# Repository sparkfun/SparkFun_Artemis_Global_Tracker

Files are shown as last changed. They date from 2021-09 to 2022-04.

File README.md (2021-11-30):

SparkFun Artemis Global Tracker
===============================

SparkFun Artemis Global Tracker (https://www.sparkfun.com/products/18712)

[*SparkFun Artemis Global Tracker (WRL-18712)*](https://www.sparkfun.com/products/18712)

The SparkFun Artemis Global Tracker combines the SparkFun Artemis processor with an Iridium 9603N satellite transceiver, ZOE-M8Q GNSS transceiver, and MS8607 PHT sensor to create a truly global tracking and data gathering device in a small form-factor. With a clear view of the sky, this board allows you to send and receive short data messages from anywhere in the world including remote locations like the polar regions, far beyond the reach of WiFi and GSM networks.

Repository Contents
-------------------

* **/Documentation** - Datasheets, FAQs, Hardware Overview, and Message Format for the full Global Tracker Example
* **/Hardware** - Eagle PCB, SCH and LBR design files
* **/Software** - Arduino examples
* **/Tools** - Tools to help: configure the full GlobalTracker example via USB or remotely via Iridium messaging; and track and map its position
* **/binaries** - binary files for the examples which you can upload using the [Artemis Firmware Upload GUI](https://github.com/sparkfun/Artemis-Firmware-Upload-GUI) instead of the Arduino IDE
* **/img** - Folder hosting for images used in the repository
* **LICENSE.md** contains the licence information

Documentation
-------------

* **[Hookup Guide](https://learn.sparkfun.com/tutorials/artemis-global-tracker-hookup-guide)** - Hookup Guide for the SparkFun Artemis Global Tracker.
* **[Artemis Development with Arduino](https://learn.sparkfun.com/tutorials/artemis-development-with-the-arduino-ide)** - An in-depth guide on developing in the Arduino IDE for the Artemis module and any Artemis microcontroller development board.
* **[SparkFun Apollo3 Arduino Core](https://github.com/sparkfun/Arduino_Apollo3)** - GitHub Repository for the SparkFun Apollo3 Arduino core.
* **[Installing an Arduino Library Guide](https://learn.sparkfun.com/tutorials/installing-an-arduino-library)** - Basic information on how to install an Arduino library.
* **[SparkFun IridiumSBD I<sup>2</sup>C Arduino Library](https://github.com/sparkfun/SparkFun_IridiumSBD_I2C_Arduino_Library)** - An Arduino library to support Short Burst Data communication using the Iridium 9602 and 9603N over both Serial and I2C.
* **[SparkFun u-blox GNSS Arduino Library](https://github.com/sparkfun/SparkFun_u-blox_GNSS_Arduino_Library)** - An Arduino library which allows you to communicate seamlessly with the full range of u-blox GNSS modules.
* **[SparkFun MS8607 Arduino Library](https://github.com/sparkfun/SparkFun_PHT_MS8607_Arduino_Library)** - An Arduino library for the TE MS8607 combined Pressure, Humidity and Temperature sensor.

Version History
---------------

* [SPX-16469](https://www.sparkfun.com/products/16469) - Initial SparkX Release
* [WRL-18712](https://www.sparkfun.com/products/18712) - Initial SparkFun Release

License Information
-------------------

This product is _**open source**_!

Please review the LICENSE.md file for license information.

If you have any questions or concerns on licensing, please contact technical support on our [SparkFun forums](https://forum.sparkfun.com/viewforum.php?f=123).

Distributed as-is; no warranty is given.

- Your friends at SparkFun.

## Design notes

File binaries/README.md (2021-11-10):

# Artemis Global Tracker: Binaries

This folder contains the binary files for some of the AGT examples.

You can upload these to the AGT using the [Artemis Firmware Upload GUI](https://github.com/sparkfun/Artemis-Firmware-Upload-GUI) instead of the Arduino IDE.
Which is handy if you want to quickly update the firmware in the field, or are not familiar with the IDE.

To use:

* Download and extract the [AGT repo ZIP](https://github.com/sparkfun/Artemis_Global_Tracker/archive/main.zip)
* Download and extract the [AFU repo ZIP](https://github.com/sparkfun/Artemis-Firmware-Upload-GUI/archive/master.zip)
* Run the AFU artemis_firmware_uploader_gui executable for your platform
  * **/Windows** contains the Windows .exe
  * **/OSX** contains an executable for macOS X
  * **/Linux** contains an executable built on Ubuntu
  * **/Raspberry_Pi__Debian** contains an executable for Raspberry Pi 4 (Debian Buster)
* Select the AGT firmware file you'd like to upload (should end in *.bin*)
  * **Example1 - Blink** powers up the tracker and blinks the white LED (connected to D19).
  * **Example14 - Simple Tracker** is a simple tracker which: wakes up every INTERVAL minutes; gets a GNSS fix; reads the PHT sensor; and sends all the data in a SBD message.
  * **Example15 - Better Tracker** is a better tracker where the INTERVAL, RBDESTINATION and RBSOURCE are stored in 'EEPROM' (Flash) and can be configured via Iridium SBD messages.
  * **Example16 - Global Tracker** is the full Global Tracker. All of the settings can be configured via USB-C or remotely via an Iridium SBD message using the [Artemis Global Tracker Configuration Tool (AGTCT)](../Tools).
  * **Example19 - Serial Terminal** allows the AGT to be operated via a simple Serial Terminal interface. Open the Serial Monitor or a Terminal Emulator at 115200 baud to see the menu.
* Attach the AGT target board using USB
* Select the COM port (hit Refresh to refresh the list of USB devices)
* Press Upload

The GUI does take a few seconds to load and run. _**Don't Panic**_ if the GUI does not start right away.

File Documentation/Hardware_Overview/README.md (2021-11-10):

# Artemis Global Tracker: Hardware Overview

The Artemis Global Tracker is an open source satellite tracker utilising the [SparkFun Artemis module](https://www.sparkfun.com/products/15484),
[Iridium 9603N satellite transceiver](https://www.iridium.com/products/iridium-9603/) and [u-blox ZOE-M8Q GNSS
](https://www.u-blox.com/en/product/zoe-m8-series).

The hardware design is based extensively on the:
- [SparkFun Artemis module](https://www.sparkfun.com/products/15484)
- [SparkFun Thing Plus - Artemis](https://www.sparkfun.com/products/15574) battery charging circuit and USB-C interface
- [SparkFun Qwiic Iridium 9603N](https://www.sparkfun.com/products/16394) Iridium 9603N, LTC3225 supercapacitor charger and ADM4210 inrush current circuit
- [SparkFun GPS Breakout - ZOE-M8Q](https://www.sparkfun.com/products/15193) ZOE connections and backup battery circuit

The design also makes use of the:
- [Skyworks AS179-92LF GaAs RF Switch](https://www.skyworksinc.com/products/switches/as179-92lf)
- [Maxtena M1600HCT-P-SMA antenna](https://www.maxtena.com/products/f-gps/m1600hct-p-sma/) which is tuned for Iridium, GPS and GLONASS
  - [Available from SparkFun](https://www.sparkfun.com/products/16838)
- [TE / MEAS Switzerland MS8607](https://www.te.com/usa-en/product-CAT-BLPS0018.html) combined pressure, humidity and temperature sensor

The full schematic for the tracker can be found [here](../../Hardware/Schematic.pdf)

Additional information can be found in the [FAQs](../GlobalTracker_FAQs/README.md)

## The Artemis Module

The heart of the tracker is, of course, the most excellent Artemis module from SparkFun. The pad allocation is defined [here](../Hardware_Overview/ARTEMIS_PINS.md).

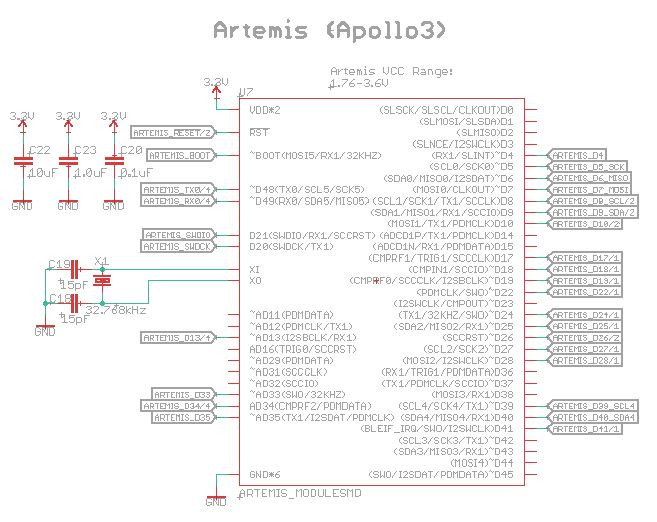
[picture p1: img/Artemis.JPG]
Artemis


## Power Options

The tracker can be powered from:
- the USB-C interface
- a LiPo battery (recharged via the USB-C interface)
- an external solar panel or battery pack (6V maximum)

3 x Energizer&trade; Ultimate Lithium AA or AAA cells are recommended as they will work down to -40C

Low-forward-voltage diodes isolate the power sources from each other. You can have the USB, LiPo and external cells connected simultaneously, it will do no harm.
The tracker will preferentially draw power from USB if it is connected.

If the USB is disconnected, the tracker will preferentially draw power from the external cells. If you have the external cells connected, you may as well disconnect the LiPo.

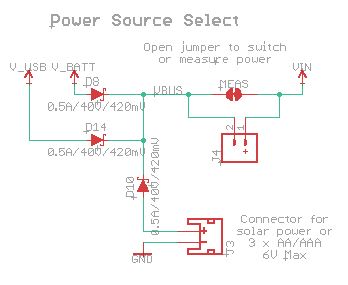
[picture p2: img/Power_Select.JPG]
Power_Select


J4 (VBUS -> VIN) can be used to measure the current draw or to connect a power switch after you open the MEAS split pad.

## USB Interface

The USB interface is taken directly from the [SparkFun Thing Plus - Artemis](https://www.sparkfun.com/products/15574).

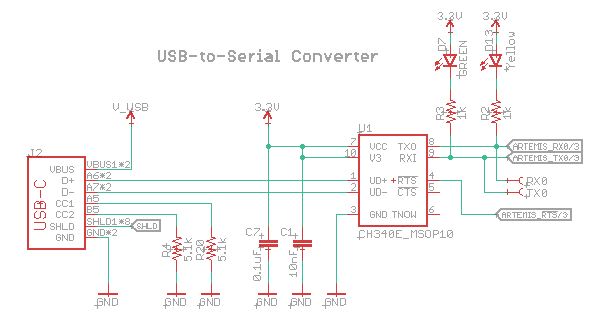
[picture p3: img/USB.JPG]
USB


## LiPo Charger

The LiPo charger circuit is taken directly from the [SparkFun Thing Plus - Artemis](https://www.sparkfun.com/products/15574).

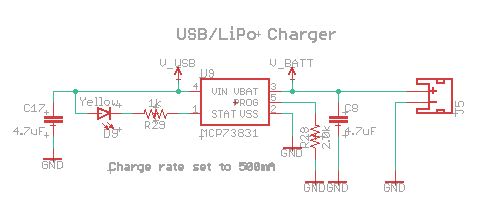
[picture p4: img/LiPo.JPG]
LiPo


## 3.3V Regulator

3.3V power for the tracker is regulated by an AP2112K regulator. Its 50uA quiescent current draw means it can be powered continuously without
depleting the batteries during sleep.

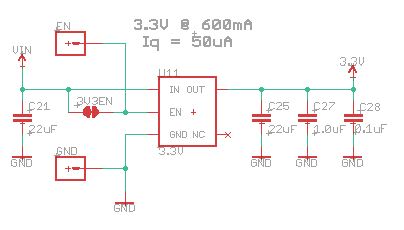
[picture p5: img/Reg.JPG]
Reg


If you want to completely disable the regulator to minimise the current draw, you can do so by opening the 3.3V_EN split pad. The EN pin can then be used to enable/disable the regulator.
Pull EN low to disable the regulator, pull it up to VIN to enable it. EN could also be driven by a logic signal from an external timer circuit.

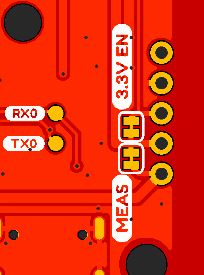
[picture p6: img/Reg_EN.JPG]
Reg_EN


## ZOE-M8Q

GNSS data is provided by the u-blox ZOE-M8Q as used on the [SparkFun GPS Breakout - ZOE-M8Q](https://www.sparkfun.com/products/15193).

Connection to the Artemis is via I2C port 1. The serial and safeboot pins are available on test pads to allow the ZOE firmware to be updated.

Geofence alerts from the ZOE can be produced on PIO14, which is connected to Artemis pin D10.

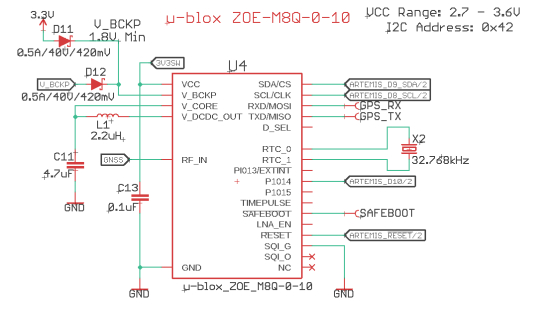
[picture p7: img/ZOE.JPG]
ZOE


Back-up power for the ZOE is drawn preferentially from the 3.3V rail, but there is a small back-up battery too to keep the ZOE's clock running
when all other power sources have been disconnected. The battery recharges only when USB power is connected (to help minimise the 3.3V current
draw during sleep).

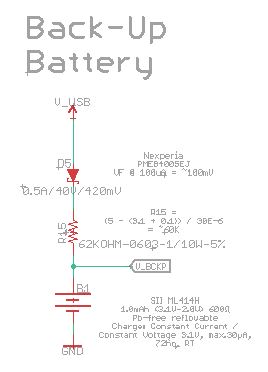
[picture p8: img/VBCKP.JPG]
VBCKP


3.3V power for the ZOE is switched via a FET. The same switched power also feeds the antenna switch when the GNSS is in use.

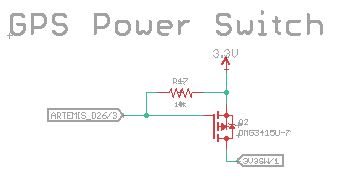
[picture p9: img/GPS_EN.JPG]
GPS_EN


## Iridium 9603N

The tracker uses the same Iridium 9603N transceiver as the [SparkFun Qwiic Iridium 9603N](https://www.sparkfun.com/products/16394).

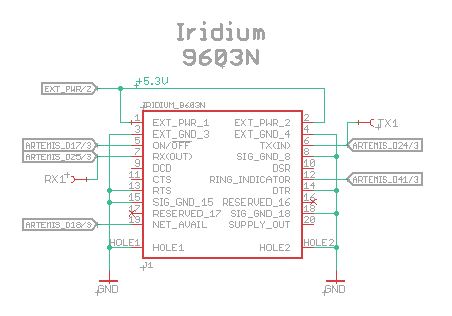
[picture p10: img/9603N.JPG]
9603N


Power for the 9603N is provided by the same LTC3225 supercapacitor charger and ADM4210 in-rush current limit circuit as used by the Qwiic Iridium.

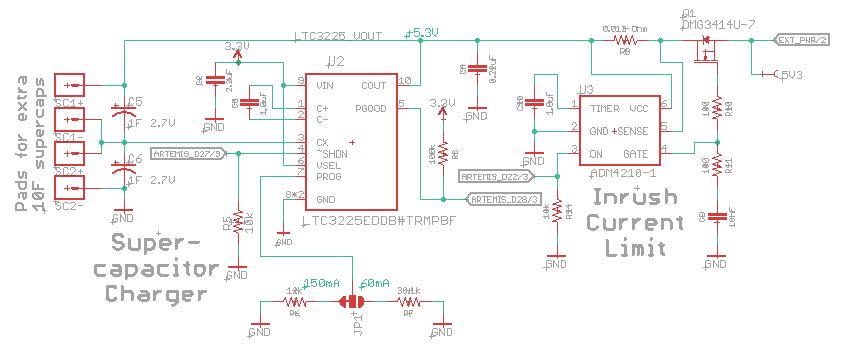
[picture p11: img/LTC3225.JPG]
LTC3225


The LTC3225 charge current is adjustable up to a maximum of 150mA. When set to the full 150mA, the LTC3225 can match the 145mA average current
drawn by the 9603N during transmit. This means that 1 Farad supercapacitors are adequate as they only need to hold enough charge to meet the
9603N's 1.3A peak current draw during the very brief (8.3ms) transmit bursts.

If you want to power the Global Tracker from a low current source, e.g. solar panels, the charge current can be reduced to 60mA by
changing the **Charge Current** jumper link. The 60mA charge current is enough to offset the 9603N's 39mA average current draw during receive,
but bigger supercapacitors are needed to deliver the average current draw during a complete receive/transmit cycle.
So, if you do change the charge current to 60mA, you will also need to solder additional 10 Farad supercapacitors on to
the rear of the PCB using the solder pads provided.

## Antenna Switch

The ZOE and Iridium 9603N share the antenna via a [Skyworks AS179-92LF GaAs RF Switch](https://www.skyworksinc.com/products/switches/as179-92lf).

Care needs to be taken that the 3.3V GNSS and 5.3V 9603N are not powered up simultaneously as _bad things might happen to the AS179_.

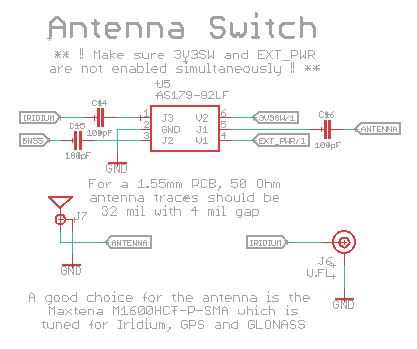
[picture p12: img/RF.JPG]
RF


## Pressure, Humidity and Temperature Sensor

Pressure, humidity and temperature readings are provided by a [TE / MEAS Switzerland MS8607](https://www.te.com/usa-en/product-CAT-BLPS0018.html) combined sensor.
The MS8607 shares I2C port 1 with the ZOE.

The sensor will provide pressure readings as low as 10mbar which is equivalent to an altitude of approximately 31,000m.

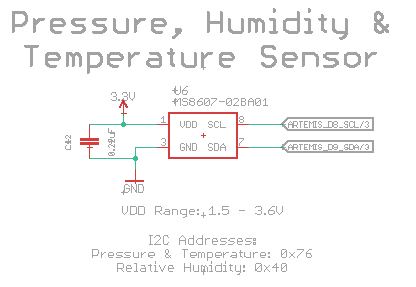
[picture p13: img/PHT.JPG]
PHT


## I/O Pins

The Artemis' SPI and I2C (port 1) pins are broken out on pin headers so the user can connect external peripherals.

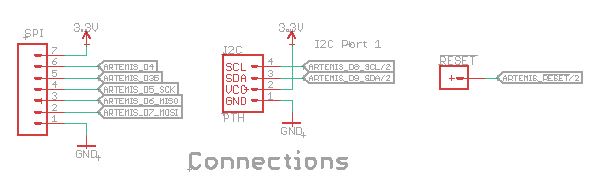
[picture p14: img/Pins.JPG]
Pins


I2C port 4 is broken out on a standard SparkFun Qwiic connector.

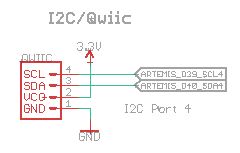
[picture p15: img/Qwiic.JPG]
Qwiic


## Bus Voltage

The bus voltage (from the USB, LiPo or external cells) can be measured via the Artemis pin AD13. A simple two resistor divider divides the bus voltage by three.
Power to the resistor divider is switched by an N-FET so the power draw can be minimised during sleep.

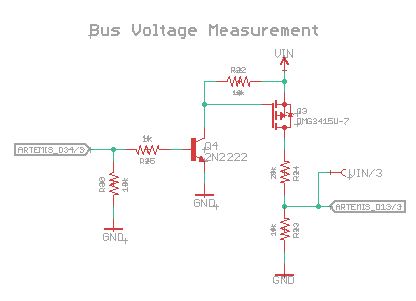
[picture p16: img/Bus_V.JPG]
Bus_V


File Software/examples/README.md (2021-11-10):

# Artemis Global Tracker Examples

These examples demonstrate how to use the Artemis Global Tracker. There are examples showing: how to communicate with the MS8607 PHT sensor;
how to get a fix from the ZOE-M8Q GNSS; how to set up a geofence and how to wake up the Artemis when the geofence status changes;
how to send Iridium Short Burst Data (SBD) messages and monitor the ring channel for new messages. Example16 contains the code
for the full GlobalTracker.

If you don't want to use the Arduino IDE, you can upload the examples using the [Artemis Firmware Upload GUI](https://github.com/sparkfun/Artemis-Firmware-Upload-GUI) instead.
You will find the binary files in the [binaries folder](../../binaries).

**Example1 - Blink** powers up the tracker and blinks the white LED (connected to D19).

**Example2 - Bus Voltage** demonstrates how to read: the battery (bus) voltage; the internal VCC voltage; the Artemis internal temperature; the VSS (ground) voltage.

**Example3 - PHT** demonstrates how to read the pressure, humidity and temperature from the on-board MS8607 sensor.

**Example4 - External PHT** demonstrates how to read the pressure, humidity and temperature from an [external MS8607 sensor](https://www.sparkfun.com/products/16298) connected to the Qwiic port.

**Example5 - GNSS** demonstrates how to read the tracker's position from the ZOE-M8Q GNSS.

**Example6 - Geofence** demonstrates how to set four geofences around the tracker's current position. The white LED will go out if the tracker is moved outside the largest geofenced area.

**Example7 - Get IMEI** demonstrates how to read the IMEI identifier from the Iridium 9603N modem. You do not need message credits to run this example.

**Example8 - Check CSQ** demonstrates how to read the signal quality from the Iridium 9603N modem. You do not need message credits to run this example.

**Example9 - Get Time** demonstrates how to read the time from the Iridium network. You do not need message credits to run this example.

**Example10 - Basic Send** demonstrates how to send a simple "Hello, world!" message via Iridium. This example will use one message credit each time you run it.

**Example11 - Ring** demonstrates how to monitor the Iridium ring channel and download new messages sent to the tracker. This example will use one or more credits each time
a message is downloaded (depending on the length of the message).

**Example12 - Test Low Power** demonstrates how to put the Artemis into deep sleep and wake it up again every INTERVAL seconds.

**Example13 - Geofence Alert** demonstrates how to set a geofence around the tracker's current position. The Artemis will then go into deep sleep and will be woken up again by the ZOE-M8Q
if the geofence status changes. The ZOE is put into power save mode to help reduce the current draw (to approximately 9mA).

**Example14 - Simple Tracker** is a simple tracker which: wakes up every INTERVAL minutes; gets a GNSS fix; reads the PHT sensor; and sends all the data in a SBD message.
The message is transmitted as text and has the format:
- DateTime,Latitude,Longitude,Altitude,Speed,Course,PDOP,Satellites,Pressure,Temperature,Battery,Count

This example will use two message credits each time a message is sent due to the length of the message.

**Example15 - Better Tracker** is a better tracker where the INTERVAL, RBDESTINATION and RBSOURCE are stored in 'EEPROM' (Flash) and can be configured via Iridium SBD messages.

The message transmit interval can be configured by sending a plain text message to the tracker via the RockBLOCK Gateway using the format _[INTERVAL=nnn]_
where _nnn_ is the new message interval in _minutes_. The interval will be updated the next time the beacon wakes up for a transmit cycle.

If you want to enable message forwarding via the RockBLOCK Gateway, you can do this by including the text _[RBDESTINATION=nnnnn]_ in the message
where _nnnnn_ is the RockBLOCK serial number of the tracker or RockBLOCK you want the messages to be forwarded to. You can disable message forwarding
again by sending a message containing _[RBDESTINATION=0]_. You can change the source serial number which is included in the messages by including the text
_[RBSOURCE=nnnnn]_ in the RockBLOCK message where _nnnnn_ is the serial number of the RockBLOCK 9603N on the tracker. You can concatenate the configuration messages.
Send the following to set all three settings in one go: _[INTERVAL=5][RBDESTINATION=12345][RBSOURCE=54321]_

If message forwarding is enabled, the message format will be (using the above example):
- RB0012345,DateTime,Latitude,Longitude,Altitude,Speed,Course,PDOP,Satellites,Pressure,Temperature,Battery,Count,RB0054321

If message forwarding is enabled, you will be charged twice for each message: once to send it, and once to receive it.

**Example16 - Global Tracker** is the full Global Tracker which has many settings that can be configured and stored in EEPROM. The GlobalTracker can be configured to transmit:
on a GeoFence alert; or when Pressure, Temperature or Humidity limits are exceeded; or if the battery voltage is low. All of the settings can be configured via USB-C
or remotely via a binary format Iridium SBD message.

Messages can be sent in text format (human-readable) or binary format (to save messages credits). You can configure which message fields are included in the message so you only send the data you need.
The [Artemis Global Tracker Configuration Tool (AGTCT)](../../Tools) will generate the configuration messages for you.

You can trigger user-defined functions e.g. to operate an [external relay](https://www.sparkfun.com/products/15093).

You can also include readings from additional external sensors.

You can have the Iridium 9603N monitor the ring channel continuously for new Mobile Terminated messages so it can respond to them immediately,
but this will increase the current draw considerably. This is not recommended for battery-powered applications.

Please refer to the [GlobalTracker FAQs](../../Documentation/GlobalTracker_FAQs/README.md) for more information.

**Example17 - Production Test** is code used to test the Artemis Global Tracker during production. You will need an AGT Test Header to allow this code to run.

**Example18 - Production Test 2** is code used to test the Artemis Global Tracker during production. You will need an AGT Test Header to allow this code to run.

**Example19 - Serial Terminal** allows the AGT to be operated via a simple Serial Terminal interface. Open the Serial Monitor or a Terminal Emulator at 115200 baud to see the menu. You can:
- Read the temperature and pressure from the MS8607
- Read position, velocity and time data from the ZOE-M8Q GNSS
- Check for new Iridium messages
- Send and receive text and binary Iridium messages
- Flush the Iridium Mobile Terminated message queue

**Example20 - GNSS Module Info** reads the module information from the ZOE-M8Q GNSS, allowing you to see what software version it is running

**Example21 - Iridium Serial and Power Test** tests the work-around for v2.1 of the Apollo3 core (where the Iridium modem pulling the Serial1 RX pin low can cause the Artemis to hang)

<br/>

To run the examples, you will need to install **v2.1.0** of the SparkFun Apollo3 core and then set the board to the "**RedBoard Artemis ATP**":
- At the time of writing, v2.1.1 of the core contains a feature which makes communication with the u-blox GNSS problematic. Be sure to use **v2.1.0**
- https://learn.sparkfun.com/tutorials/artemis-development-with-the-arduino-ide
 
You will need to install [this version of the Iridium SBD library](https://github.com/sparkfun/SparkFun_IridiumSBD_I2C_Arduino_Library)
- (Available through the Arduino Library Manager: search for IridiumSBDi2c)

You will also need to install the [Qwiic_PHT_MS8607_Library](https://github.com/sparkfun/SparkFun_PHT_MS8607_Arduino_Library)
- (Available through the Arduino Library Manager: search for SparkFun MS8607)

You also need the [SparkFun u-blox GNSS library](https://github.com/sparkfun/SparkFun_u-blox_GNSS_Arduino_Library)
- (Available through the Arduino Library Manager: search for SparkFun u-blox GNSS)

Basic information on how to install an Arduino library is available [here](https://learn.sparkfun.com/tutorials/installing-an-arduino-library)

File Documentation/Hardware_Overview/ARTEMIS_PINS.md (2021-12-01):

# Artemis Global Tracker: Artemis Pad Allocation

| Module Pad No. | Name | Pin | Allocation |
|---|---|---|---|
| 1 | GND | | Power Ground |
| 2 | GPIO20 | SWDCK | JTAG single wire clock |
| 3 | GPIO49 | RX0 | Bootload RX pin for serial bootloading |
| 4 | GPIO39 | ~D39 | Qwiic SCL |
| 5 | GPIO40 | D40 | Qwiic SDA |
| 6 | GPIO9 | D9 | ZOE-M8Q SDA |
| 7 | BOOT | | Bootload. Hold pin high during reset to initiate bootloader |
| 8 | GPIO10 | D10 | ZOE-M8Q PIO14 (Geofence Alert) |
| 9 | GPIO48 | TX0 | Bootload TX pin for serial bootloading |
| 10 | GPIO21 | SWDIO | JTAG single wire I/O |
| 11 | GPIO8 | D8 | ZOE-M8Q SCL |
| 12 | GPIO5 | ~D5 | SPI SCK or GPIO |
| 13 | GPIO7 | ~D7 | SPI MOSI or GPIO |
| 14 | GPIO35 | ~AD35 | SPI CS(1) or GPIO |
| 15 | GPIO4 | ~D4 | SPI CS(2) or GPIO |
| 16 | GPIO24 | ~D24 | Iridium 9603N TX(In) |
| 17 | GPIO22 | ~D22 | AD4210 ON |
| 18 | GPIO23 | ~D23 | N/C |
| 19 | GPIO27 | ~D27 | LTC3225 SHDN |
| 20 | GPIO14 | D14 | N/C |
| 21 | GPIO28 | ~D28 | LTC3225 PGOOD |
| 22 | GND | | Power |
| 23 | GPIO6 | ~D6 | SPI MISO or GPIO |
| 24 | GPIO32 | ~AD32 | GPIO |
| 25 | GPIO25 | ~D25 | Iridium 9603N RX(Out) |
| 26 | GPIO12 | ~AD12 | GPIO |
| 27 | GPIO26 | ~D26 | GPS_EN |
| 28 | GPIO13 | ~AD13 | Bus Voltage Measure |
| 29 | GPIO15 | D15 | GPIO |
| 30 | GPIO33 | ~AD33/SWO | JTAG SWO |
| 31 | GPIO34 | AD34 | Bus Voltage Measure Enable |
| 32 | GPIO11 | ~AD11 | GPIO |
| 33 | GPIO29 | ~AD29 | GPIO |
| 34 | XO | | 32kHz Xtal Connection for external 32.768kHz RTC crystal |
| 35 | XI | | 32kHz Xtal Connection for external 32.768kHz RTC crystal |
| 36 | VDD | | Power |
| 37 | VDD | | Power |
| 38 | GND | | Power |
| 39 | GND | | Power |
| 40 | GPIO19 | ~D19 | White LED |
| 41 | GPIO18 | ~D18 | Iridium 9603N Network Available |
| 42 | GPIO16 | AD16 | N/C |
| 43 | GPIO17 | D17 | Iridium 9603N ON/OFF |
| 44 | GPIO31 | ~AD31 | GPIO |
| 45 | GPIO41 | D41 | Iridium 9603N Ring Indicator |
| 46 | GPIO45 | ~D45 | N/C |
| 47 | GND | | Power |
| 48 | GPIO2 | D2 | N/C |
| 49 | GPIO1 | D1 | N/C |
| 50 | nRESET | | System Reset Pull pin low to reset system |
| 51 | GPIO0 | D0 | N/C |
| 52 | GPIO43 | ~D43 | GPIO |
| 53 | GPIO42 | ~D42 | GPIO |
| 54 | GPIO3 | D3 | N/C |
| 55 | GPIO36 | D36 | N/C |
| 56 | GPIO38 | D38 | N/C |
| 57 | GPIO37 | ~D37 | GPIO |
| 58 | GPIO44 | ~D44 | N/C |
| 59 | GND | | Power |

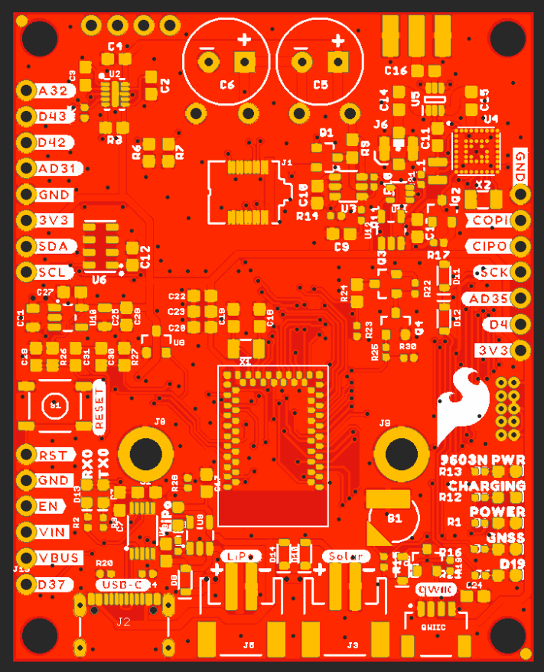
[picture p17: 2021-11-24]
Hardware/Artemis_Global_Tracker_TOP_VIEW.png

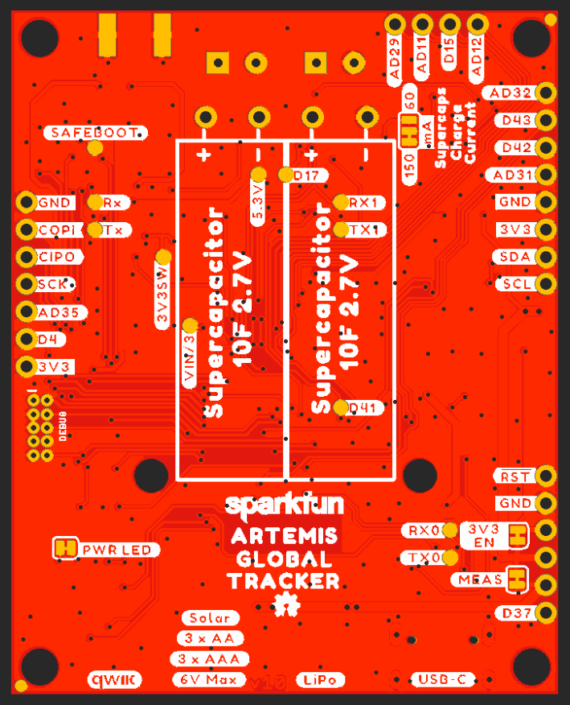
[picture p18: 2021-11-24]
Hardware/Artemis_Global_Tracker_BOTTOM_VIEW.png

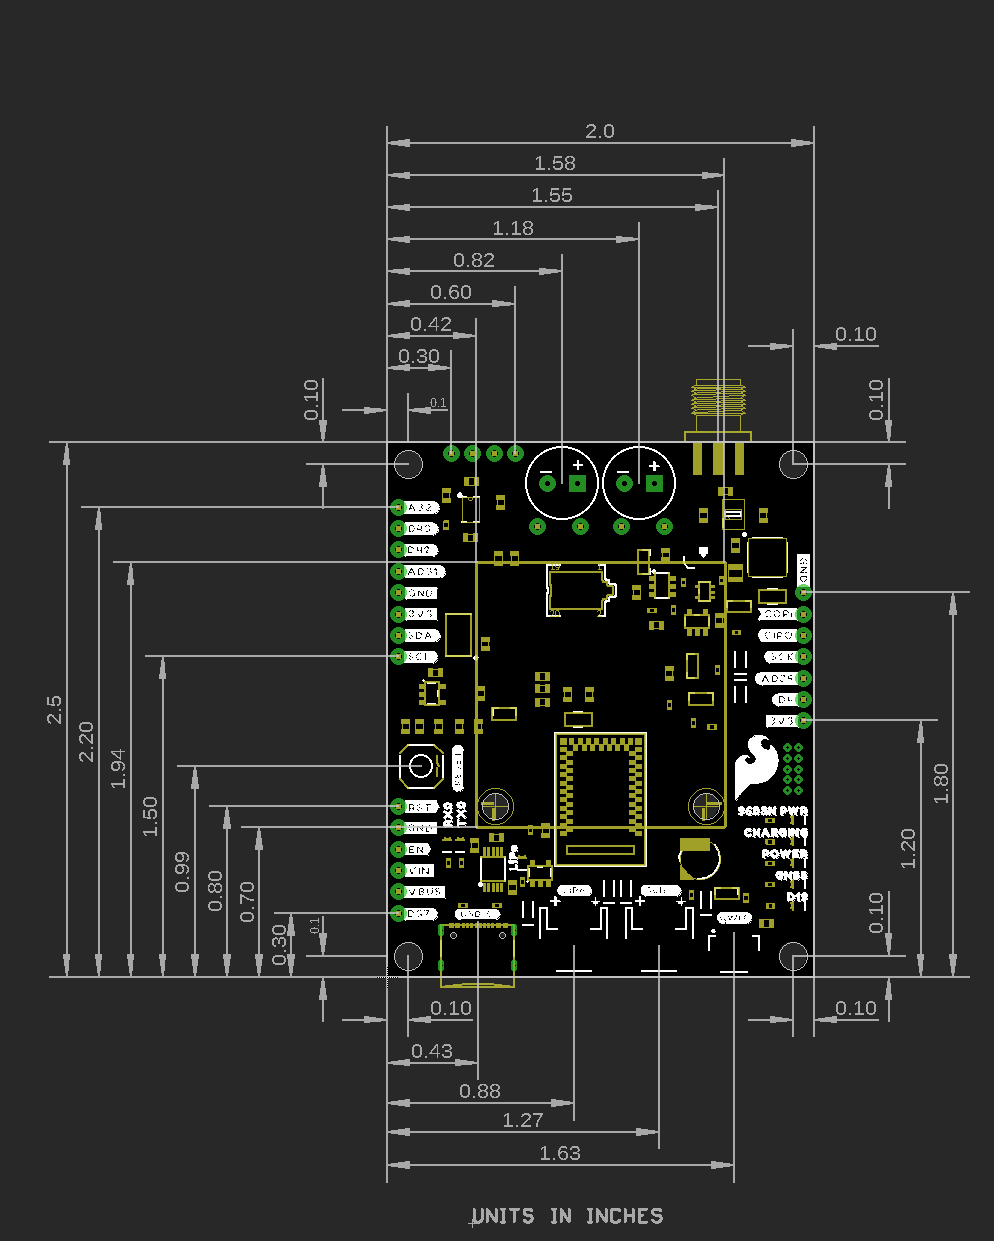
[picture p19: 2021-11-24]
Hardware/Artemis_Global_Tracker_DIMENSIONAL.png

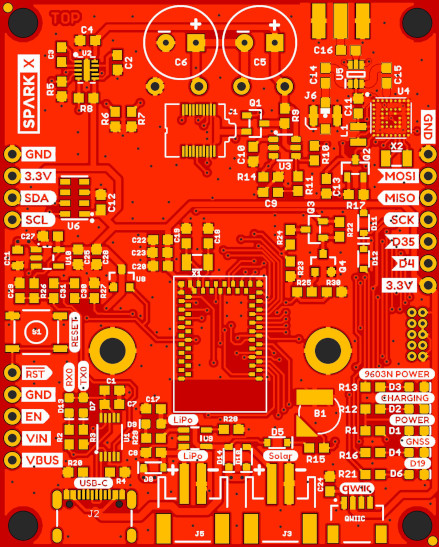
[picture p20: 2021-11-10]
img/Top.JPG

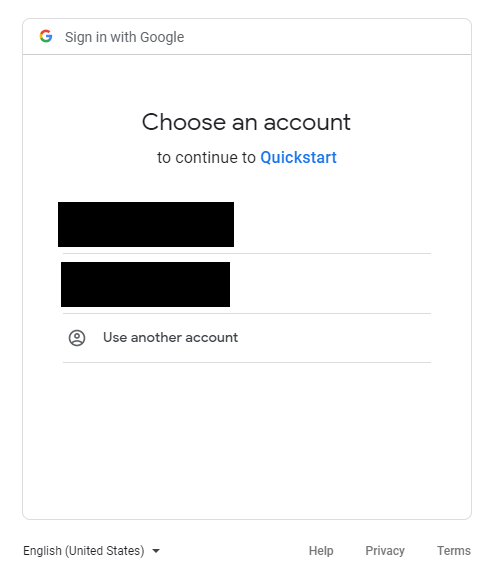
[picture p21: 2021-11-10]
img/Quickstart1.PNG

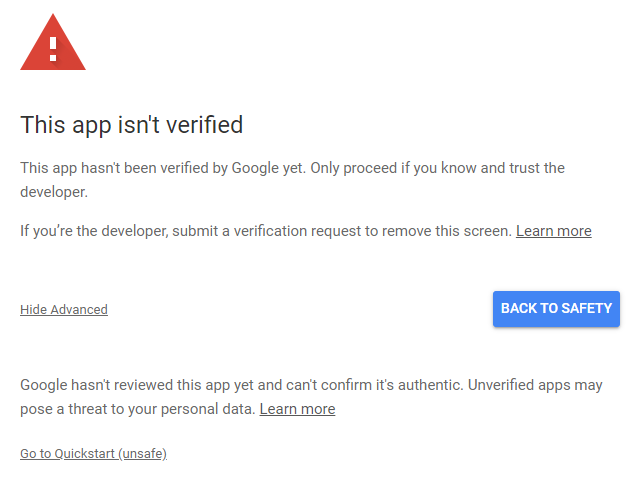
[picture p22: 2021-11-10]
img/Quickstart3.PNG

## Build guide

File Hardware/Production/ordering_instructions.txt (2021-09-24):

panel size, 116x178mm
PCB thickness, 1.6mm
number of layers, 2
soldermask color, Red
silkscreen color, White
oz copper, 1oz
finish, HASL lead free
stencils, top
pcs per panel, 4
min trace width, 0.2032mm / 0.0080in
min drill size, 0.2540mm / 0.0100in

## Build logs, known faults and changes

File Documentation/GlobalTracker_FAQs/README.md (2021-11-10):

# Artemis Global Tracker: GlobalTracker FAQs

These FAQs assume you are running the [full Global Tracker (Example16)](../../Software/examples/Example16_GlobalTracker)

## Contents:
- [Do I need the extra 10F supercapacitors?](#Do-I-need-the-extra-10F-supercapacitors)
- [What voltage does the AGT need?](#What-voltage-does-the-AGT-need)
- [How much current does the AGT draw?](#How-much-current-does-the-AGT-draw)
- [Which antenna should I use?](#Which-antenna-should-I-use)
- [Can I use an active antenna?](#Can-I-use-an-active-antenna)
- [How do I configure the messages sent by the tracker?](#How-do-I-configure-the-messages-sent-by-the-tracker)
- [How do I send binary messages?](#How-do-I-send-binary-messages)
- [How do I enable RockBLOCK message forwarding?](#How-do-I-enable-RockBLOCK-message-forwarding)
- [How do I enable Pressure, Humidity and Temperature alarms?](#How-do-I-enable-Pressure-Humidity-and-Temperature-alarms)
- [How do I enable Geofence alarms?](#How-do-I-enable-Geofence-alarms)
- [How do I monitor the ring channel continuously for new MT messages?](#How-do-I-monitor-the-ring-channel-continuously-for-new-MT-messages)
- [How do I define and trigger a user function?](#How-do-I-define-and-trigger-a-user-function)
- [How do I send a user value?](#How-do-I-send-a-user-value)
- [How can I see the location of my trackers on a map?](#How-can-I-see-the-location-of-my-trackers-on-a-map)

## Do I need the extra 10F supercapacitors?

The AGT comes with 1F supercapacitors installed. You only need to add the additional 10F capacitors on the bottom of the board if you decide to
change the supercapacitor charge current from 150mA to 60mA.

Background:

The LTC3225 supercapacitor charger charge current is adjustable up to a maximum of 150mA. When set to the full 150mA, the LTC3225 can match the 145mA average current
drawn by the 9603N during transmit. This means that 1 Farad supercapacitors are adequate as they only need to hold enough charge to meet the
9603N's 1.3A peak current draw during the very brief (8.3ms) transmit bursts.

If you want to power the Global Tracker from a low current source, e.g. solar panels, the charge current can be reduced to 60mA by
changing the **Charge Current** jumper link. The 60mA charge current is enough to offset the 9603N's 39mA average current draw during receive,
but bigger supercapacitors are needed to deliver the average current draw during a complete receive/transmit cycle.
So, if you do change the charge current to 60mA, you will also need to solder additional 10 Farad supercapacitors on to
the rear of the PCB using the solder pads provided.

## What voltage does the AGT need?

Please refer to the [Power Options](../Hardware_Overview#power-options) in the Hardware Overview.

**Important Note:** We recommend that you power the AGT using the USB, Lipo battery and/or "Solar" power connectors.
If you choose to power the AGT via the VBUS breakout pin, there will be no reverse-polarity protection and _bad things could happen_
when connecting another power source.

Via the VBUS breakout pin:
- Maximum: 6.0V
- Recommended Minimum: 3.4V
  - The AP2112K 3.3V regulator has a dropout voltage of 100mV at 250mA at 25°C
- Actual Minimum: 3.2V (Approx.)
  - The LTC3225 supercapacitor charger requires a minimum of 2.8V and is powered by the AP2112K
  - The Artemis and ZOE GNSS have lower minimum voltages

Via the USB, Lipo battery or "Solar" (external power) connectors:
- Maximum: 6.0V
- Minimum: add approximately 350mV to the above figures
  - The PMEG4005 reverse-protection diode has a forward voltage of approx. 350mV at 300mA at 25°C

## How much current does the AGT draw?

In deep sleep, with the Power LED disconnected, the AGT draws a current of approximately 220µA.

The maximum current draw is dictated by the LTC3225 supercapacitor charge current:
- The LTC3225 has an efficiency of approximately 80% at 3.3V V<sub>IN</sub> at 100mA charge current
- Using the maximum charge current of 150mA, the LTC3225 will draw approximately 200mA
- The typical total current draw during supercapacitor charging is 250mA

## Which antenna should I use?

We recommend [this one](https://www.sparkfun.com/products/16838). It is optimized for Iridium and GNSS (GPS and GLONASS).

## Can I use an active antenna?

No. Two reasons:
- The [antenna switch circuit](../Hardware_Overview#antenna-switch) includes a DC-blocking capacitor
- The Iridium transmit would almost certainly damage an active preamplifier

## How do I configure the messages sent by the tracker?

The messages sent by the Global Tracker contain one or more **MOFIELDS** (Mobile Originated message FIELDS).

By default, Example16_GlobalTracker sends a _text_ message, every 5 minutes, containing the following MOFIELDS:
- **DATETIME** : the GNSS date and time in _YYYYMMDDHHMMSS_ format
- **LAT** : the GNSS latitude in degrees
- **LON** : the GNSS longitude in degrees
- **ALT** : the GNSS altitude above mean sea level in meters

For a full definition of the message fields, please see the [message format documentation](../Message_Format).

Let's say you also want to include the **SPEED** (ground speed) and **HEAD** (heading) MOFIELDS:

You will find the Configuration Tool in the [Tools folder](../../Tools/Artemis_Global_Tracker_Configuration_Tool).
If you are familiar with Python and are able to install PyQt5 and all the other required modules, you can run _AGTCT.py_.
If you are less familiar with Python, you will find a 64-bit Windows executable (.exe) version in [this folder](../../Tools/Artemis_Global_Tracker_Configuration_Tool/Windows_64-bit).

When you run the configuration tool, the [PyQt5 user interface](#AGTCT1) will appear.
If you are using the 64-bit Windows executable (.exe) version: don't panic! It takes a few seconds for the user interface to appear.

It just so happens that **DATETIME** + **LAT** + **LON** + **ALT** + **SPEED** + **HEAD** are the MOFIELDS expected by the [Mapper](../../Tools/Artemis_Global_Tracker_Mapping_Tools)
and there is a pickle (.pkl) file containing those settings that you can load:
- Click on the _Browse_ button
- Click on _mapper.pkl_ and then click _Open_
- Click on the _Load Config_ button

The user interface should now look like [this](#AGTCT2). You will notice that:
- The **DATETIME**, **LAT**, **LON**, **ALT**, **SPEED** and **HEAD** MOFIELDS checkboxes are ticked. This tells the tracker to send (only) these MOFIELDS.
- The **MOFIELDS** _Include_ checkbox is ticked. This must be ticked otherwise the MOFIELDS will not be included in the configuration message. You will get a warning message if you forget.
- None of the _FLAGS1_ checkboxes are ticked. This ensures the message is sent in _text_ format, not _binary_.
- The **FLAGS1** _Include_ checkbox is ticked. This must be ticked otherwise FLAGS1 will not be included in the configuration message.
- The **TXINT** _Include_ checkbox is ticked and the value box contains _15_. This will change the message transmit interval to 15 minutes. The default is 5 minutes.

Now click on the _Calculate Config_ button and you should see the [configuration message](#AGTCT3)
_02310030c00f00000000000000000000490f00038d30_ in the _Configuration Message_ window.

You now have a choice to make. You can either update the tracker settings [via a USB cable](#Updating-the-configuration-via-USB),
or remotely [via an Iridium message](#Updating-the-configuration-via-Iridium).

If you want to restore the default settings, you can repeat the tracker configuration using the _default.pkl_ pickle file.

Loading the _empty.pkl_ is a quick way to clear all of the checkboxes and values.

### Updating the configuration via USB
- Connect the tracker to your computer using a standard USB-C cable. If you are using Windows, you should hear the usual bing-bong connection sound.
- Click on the _Refresh_ button and select the tracker's COM port from the drop-down box.
- Click on _Open Port_ and you should see a [welcome message from the tracker](#AGTCT4) in the _Serial Monitor_ window.
- Click on _Upload Config_ and you should see [these messages in the _Serial Monitor_](#AGTCT5):

```
*** Tracker Configuration ***
Waiting for data...
Data received! Checking if it is valid...
Data is valid! Parsing it...
Parsing complete. Updating values in EEPROM.
Done!
```

You can now disconnect the tracker and close the configuration tool. The tracker will use the new settings from now on.

### Updating the configuration via Iridium
- Right-click in the _Configuration Message_ window and click on _Select All_.
- Right-click in the _Configuration Message_ window again and click on _Copy_.
- Log in to [Rock7 Operations](https://rockblock.rock7.com/Operations).
- Click on the _Send a Message_ tab.
- Tick the RockBLOCK serial number of the tracker you want to update.
- Select _Hex_ from the Mode drop-down.
- Right-click in the _Hex String_ window and click _Paste_.
- Click _Send Message_ to send the configuration message.

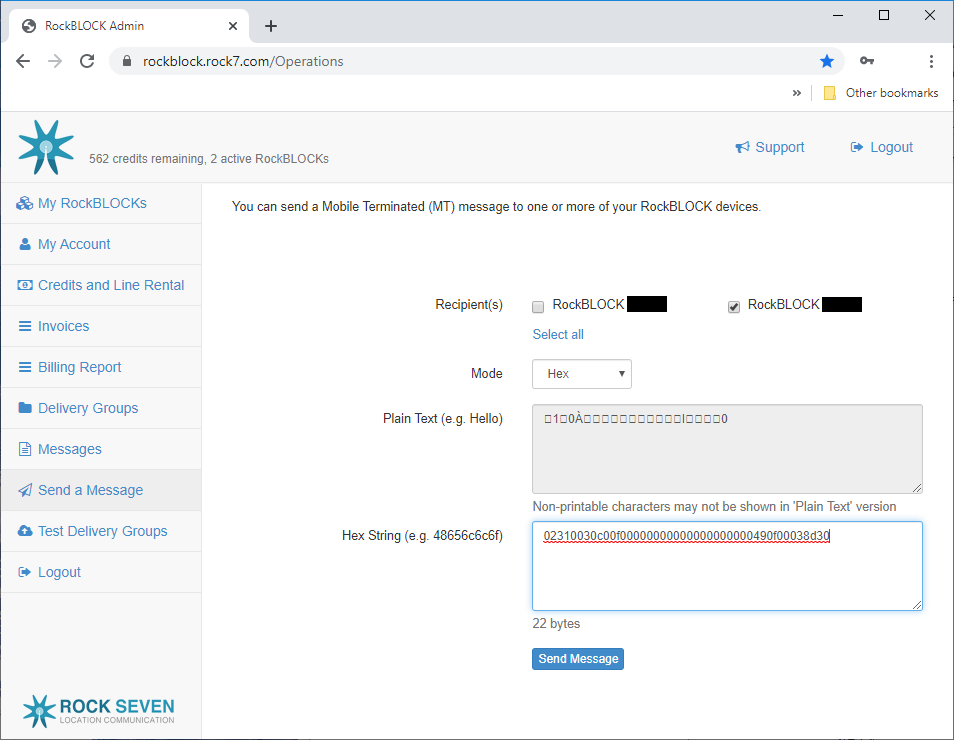
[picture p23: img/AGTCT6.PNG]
AGTCT6


The tracker settings will be updated the next time the tracker transmits.

## How do I send binary messages?

Sending messages in _binary_ format is a good way to save message credits. The message length will be approximately half compared to text, and you are charged one message
credit for every 50 bytes sent (or part thereof). The only downside is that binary messages are not human-readable.

- Open the configuration tool as shown above.
- Make sure all of the checkboxes and values are clear. Loading _empty.pkl_ is a quick way to do this.
- Tick the **FLAGS1** _Send message in binary format_ checkbox.
- Tick the **FLAGS1** _Include_ checkbox.
- Click on _Calculate Config_.

The configuration tool should look like [this](#AGTCT7). Now update the tracker settings
as shown above.

If you want to change the MOFIELDS, you can do that in the [same message](#AGTCT8).

## How do I enable RockBLOCK message forwarding?

The Rock7 RockBLOCK gateway has a powerful feature that allows you to automatically forward messages from one RockBLOCK device to another.
See [this link](https://docs.rockblock.rock7.com/docs/messaging-between-rockblocks) for further details.

E.g.
- if the RockBLOCK serial number of your tracker is 54321
- and you want to forward messages to RockBLOCK 12345

Do the following:
- Open the configuration tool as shown above.
- Make sure all of the checkboxes and values are clear. Loading _empty.pkl_ is a quick way to do this.
- Tick the **FLAGS1** _Forward messages to DEST_ checkbox.
- Tick the **FLAGS1** _Include_ checkbox.
- Tick the **DEST** _Include_ checkbox.
- Enter _12345_ in the DEST value box.
- Tick the **SOURCE** _Include_ checkbox.
- Enter _54321_ in the SOURCE value box.
- Tick the MOFIELDS checkboxes for the message fields you want to send, including the **SOURCE** MOFIELD so the destination RockBLOCK knows which tracker sent the message
- Tick the **MOFIELDS** _Include_ checkbox.
- Click on _Calculate Config_.

The configuration tool should look like [this](#AGTCT9). Now update the tracker settings
as shown above.

Notes:
- Including the **SOURCE** MOFIELD is optional, but is useful as it lets the destination RockBLOCK know which tracker sent the message.
- The tracker's SOURCE serial number can only be changed via USB, to avoid it being changed accidentally. Remember to set this before you deploy your tracker.
- You will be charged twice for each message: once when the source sends it and again when the destination receives it.

## How do I enable Pressure, Humidity and Temperature alarms?

The tracker can be configured to wake up every **WAKEINT** _seconds_. When it wakes, it will check the pressure, humidity and temperature readings from the on-board MS8607 PHT sensor.
If pressure, temperature or humidity alarms are enabled, a message will be sent every **ALARMINT** _minutes_ if any of the limits are exceeded.

E.g.
- If you want to use the tracker to monitor the temperature and humidity in your greenhouse once per minute;
- you want to send alarm messages every 15 minutes if the temperature goes above 40C;
- or if the humidity falls below 30% RH.
- If things are normal, you want to send a message once per day.

You would do the following:
- Open the configuration tool as shown above.
- Make sure all of the checkboxes and values are clear. Loading _empty.pkl_ is a quick way to do this.
- Tick the **FLAGS1** _Enable HITEMP alarm messages_ and _Enable LOHUMID_ checkboxes.
- Tick the **FLAGS1** _Include_ checkbox.
- Tick the MOFIELDS checkboxes for the message fields you want to send, e.g. **PRESS**, **TEMP**, **HUMID** and **DATETIME**
- Tick the **MOFIELDS** _Include_ checkbox.
- Tick the **WAKEINT** _Include_ checkbox.
- Enter _60_ in the WAKEINT value box. This sets the wake interval to 60 seconds.
- Tick the **ALARMINT** _Include_ checkbox.
- Enter _15_ in the ALARMINT value box. This sets the alarm transmit interval to 15 minutes.
- Tick the **TXINT** _Include_ checkbox.
- Enter _1440_ in the TXINT value box. This sets the normal transmit interval to 1440 minutes (every 24 hours).
- Tick the **HITEMP** _Include_ checkbox.
- Enter _40.0_ in the HITEMP value box. This sets the high temperature alarm limit to 40.0C.
- Tick the **LOHUMID** _Include_ checkbox.
- Enter _30.0_ in the LOHUMID value box. This sets the low humidity alarm limit to 30.0% RH.
- Click on _Calculate Config_.

The configuration tool should look like [this](#AGTCT10). Now update the tracker settings
as shown above.

## How do I enable Geofence alarms?

The tracker can be configured to leave the ZOE-M8Q GNSS powered on continuously so it can generate geofence alarms.

**Note: enabling geofence alerts will substantially increase the current draw and shorten the battery life as the ZOE will be powered continuously.**

E.g.
- If you want to set a geofence around latitude 55.0 degrees north, longitude 1 degree west, with a radius of 100m.
- You want to use a position confidence level of 95%.
- You want alarm messages to be generated when the tracker leaves the geofenced area.
- You want to send alarm messages every 5 minutes.
- If things are normal, you want to send a message once per day.

You would do the following:
- Open the configuration tool as shown above.
- Make sure all of the checkboxes and values are clear. Loading _empty.pkl_ is a quick way to do this.
- Tick the **FLAGS2** _Enable GeoFence alarm messages_ checkbox.
- Tick the **FLAGS2** _Include_ checkbox.
- Tick the MOFIELDS checkboxes for the message fields you want to send, e.g. **LAT**, **LON**, **SPEED** and **HEAD**
- Tick the **MOFIELDS** _Include_ checkbox.
- Tick the **WAKEINT** _Include_ checkbox.
- Enter _300_ in the WAKEINT value box. This sets the wake interval to 300 seconds (5 minutes).
- Tick the **ALARMINT** _Include_ checkbox.
- Enter _5_ in the ALARMINT value box. This sets the alarm transmit interval to 5 minutes.
- Tick the **TXINT** _Include_ checkbox.
- Enter _1440_ in the TXINT value box. This sets the normal transmit interval to 1440 minutes (every 24 hours).
- Tick the **GEOFNUM** _Include_ checkbox.
- Enter _12_ in the GEOFNUM value box. This sets the number of geofences to 1 and the confidence level to 2 (95%). See the [GEOFNUM definition](../Message_Format#geofnum-0x3a) for more details.
- Tick the **GEOF1LAT** _Include_ checkbox.
- Enter _55.0_ in the GEOF1LAT value box. This sets the geofence latitude to 55 degrees north.
- Tick the **GEOF1LON** _Include_ checkbox.
- Enter _-1.0_ in the GEOF1LON value box. This sets the geofence longitude to 1 degree west (western longitudes are negative).
- Tick the **GEOF1RAD** _Include_ checkbox.
- Enter _100.0_ in the GEOF1RAD value box. This sets the geofence radius to 100m.
- Click on _Calculate Config_.

The configuration tool should look like [this](#AGTCT11). Now update the tracker settings
as shown above.

Notes:
- Enabling geofence alerts will substantially increase the current draw and shorten battery life as the ZOE will be powered continuously.
- WAKEINT and ALARMINT need to be set to the same value.
- If you want the alarm messages to be generated when entering a geofenced area, tick the **FLAGS2** _Alarm when inside the GeoFence_ checkbox.

## How do I monitor the ring channel continuously for new MT messages?

The tracker can be configured to leave the Iridium 9603N powered on continuously so it can monitor the ring channel and respond to new Mobile Terminated messages immediately.

**Note: monitoring the ring channel will substantially increase the current draw as the Iridium 9603N will be powered continuously.**
**This is not recommended for battery-powered applications.**

E.g.
- You want to monitor the ring channel continuously so you can respond quickly to new MT messages.
- If things are normal, you want to send a message once per day.

You would do the following:
- Open the configuration tool as shown above.
- Make sure all of the checkboxes and values are clear. Loading _empty.pkl_ is a quick way to do this.
- Tick the **FLAGS2** _Monitor Ring Channel continuously_ checkbox.
- Tick the **FLAGS2** _Include_ checkbox.
- Tick the **WAKEINT** _Include_ checkbox.
- Enter _86400_ in the WAKEINT value box. This sets the wake interval to 86400 seconds (24 hours).
- Tick the **ALARMINT** _Include_ checkbox.
- Enter _1440_ in the ALARMINT value box. This sets the alarm transmit interval to 1440 minutes (every 24 hours).
- Tick the **TXINT** _Include_ checkbox.
- Enter _1440_ in the TXINT value box. This sets the normal transmit interval to 1440 minutes (every 24 hours).
- Click on _Calculate Config_.

The configuration tool should look like [this](#AGTCT12). Now update the tracker settings
as shown above.

Notes:
- Monitoring the ring channel will substantially increase the current draw as the Iridium 9603N will be powered continuously. This is not recommended for battery-powered applications.
- WAKEINT should be set to the same value as ALARMINT and TXINT.
- Iridium ring alerts are only sent if the network knows your approximate location. You need to send at least one message per day in order to receive ring alerts.

## How do I define and trigger a user function?

The tracker supports eight different user functions. Each function is triggered when the corresponding field ID is received via a Mobile Terminated message.

The user functions are defined in [Tracker_User_Functions.ino](../../Software/examples/Example16_GlobalTracker/Tracker_User_Functions.ino).

E.g.
- You have a [Qwiic Relay](https://www.sparkfun.com/products/15093) connected to the tracker via the Qwiic connector.
- You want the relay to switch on when USERFUNC1 (field ID 0x58) is received.
- You want the relay to switch off again when USERFUNC2 (field ID 0x59) is received.

You will need to install the _SparkFun Qwiic Relay Arduino Library_ first, through the Arduino Library Manager. Search for _Qwiic Relay_.

Example code for the Qwiic (Single) Relay is available [here](https://github.com/sparkfun/SparkFun_Qwiic_Relay_Arduino_Library/blob/master/Examples/Example1_Single_Relay_Basics/Example1_Single_Relay_Basics.ino).

We need to add these lines to the start of Tracker_User_Functions.ino:

```
#include "SparkFun_Qwiic_Relay.h"
#define RELAY_ADDR 0x18 // Alternate address 0x19
Qwiic_Relay relay(RELAY_ADDR);
TwoWire myWire(4); //Will use Artemis pads 39/40
```

Then we need to add these lines to USER_FUNC_1:

```
  myWire.begin(); // Begin I2C communication to the relay
  if(relay.begin(myWire)) // Try to begin the relay
  {
    relay.turnRelayOn(); // If relay.begin was successful, turn the relay on
  }
  myWire.end(); // End I2C communication
```

And we need to add these lines to USER_FUNC_2:

```
  myWire.begin(); // Begin I2C communication to the relay
  if(relay.begin(myWire)) // Try to begin the relay
  {
    relay.turnRelayOff(); // If relay.begin was successful, turn the relay off
  }
  myWire.end(); // End I2C communication
```

The start of Tracker_User_Functions.ino should now look like this:

```
// Artemis Global Tracker: User Functions

// Add your own code to these functions to return USERVAL's or execute USERFUNC's

#include "SparkFun_Qwiic_Relay.h"
#define RELAY_ADDR 0x18 // Alternate address 0x19
Qwiic_Relay relay(RELAY_ADDR);
TwoWire myWire(4); //Will use Artemis pads 39/40

void USER_FUNC_1()
{
  debugPrintln("Executing USERFUNC1...");
  // Add your own code here - it will be executed when the Tracker receives a "USERFUNC1" (0x58) message field

  myWire.begin(); // Begin I2C communication to the relay
  if(relay.begin(myWire)) // Try to begin the relay
  {
    relay.turnRelayOn(); // If relay.begin was successful, turn the relay on
  }
  myWire.end(); // End I2C communication
}

void USER_FUNC_2()
{
  debugPrintln("Executing USERFUNC2...");
  // Add your own code here - it will be executed when the Tracker receives a "USERFUNC2" (0x59) message field

  myWire.begin(); // Begin I2C communication to the relay
  if(relay.begin(myWire)) // Try to begin the relay
  {
    relay.turnRelayOff(); // If relay.begin was successful, turn the relay off
  }
  myWire.end(); // End I2C communication
}
```

To trigger each user function, you need to send a configuration message to the tracker containing the appropriate field ID. E.g. to trigger USERFUNC1 you would do the following:
- Open the configuration tool as shown above.
- Make sure all of the checkboxes and values are clear. Loading _empty.pkl_ is a quick way to do this.
- Tick the **USERFUNCs** _Execute USERFUNC1_ checkbox.
- Click on _Calculate Config_.

The configuration tool should look like [this](#AGTCT13).
Now send the configuration message _0258035db9_ to the tracker through Rock7 Operations as shown above.

The configuration message for USERFUNC2 is _0259035ebb_

Notes:
- The Qwiic Relay will draw extra current while it is energised. This will shorten your battery life.
- USERFUNCs 5 and 6 allow a 16-bit uint16_t to be passed to the user function.
- USERFUNCs 7 and 8 allow a 32-bit uint32_t to be passed to the user function.

## How do I send a user value?

[Tracker_User_Functions.ino](../../Software/examples/Example16_GlobalTracker/Tracker_User_Functions.ino#L53-L114) also contains
eight functions which can be used to include user-defined data in the tracker messages.
- USER_VAL_1 and USER_VAL_2 allow _byte_ values to be included.
- USER_VAL_3 and USER_VAL_4 allow _uint16_t_ values to be included.
- USER_VAL_5 and USER_VAL_6 allow _uint32_t_ values to be included.
- USER_VAL_7 and USER_VAL_8 allow _float_ values to be included.

Let's say you have connected a sensor to the tracker which returns a _float_ reading. You would include the code to read your sensor inside USER_VAL7() or USER_VAL_8(); you would load
your sensor reading into _retVal_.

To include USERVAL7 in the messages from the tracker, you would:
- Open the configuration tool as shown above.
- Make sure all of the checkboxes and values are clear. Loading _empty.pkl_ is a quick way to do this.
- Tick the MOFIELDS checkboxes for any standard message fields you want to send, e.g. **DATETIME**.
- Tick the **USERVAL7** MOFIELDS checkbox.
- Tick the **MOFIELDS** _Include_ checkbox.
- Click on _Calculate Config_.

The configuration tool should look like [this](#AGTCT14). Now update the tracker settings
as shown above.

## How can I see the location of my trackers on a map?

The [Tools Folder](../../Tools#artemis_global_tracker_mapping_tools) contains a set of mapping tools which will display
the location and routes of up to eight trackers on a Google Maps Static image in a PyQt5 user interface. The tools have all been tried and tested on both Linux and Windows.
The tools are straight forward to use, but you do need to be familiar with Python3.

## AGTCT Screenshots

### AGTCT1
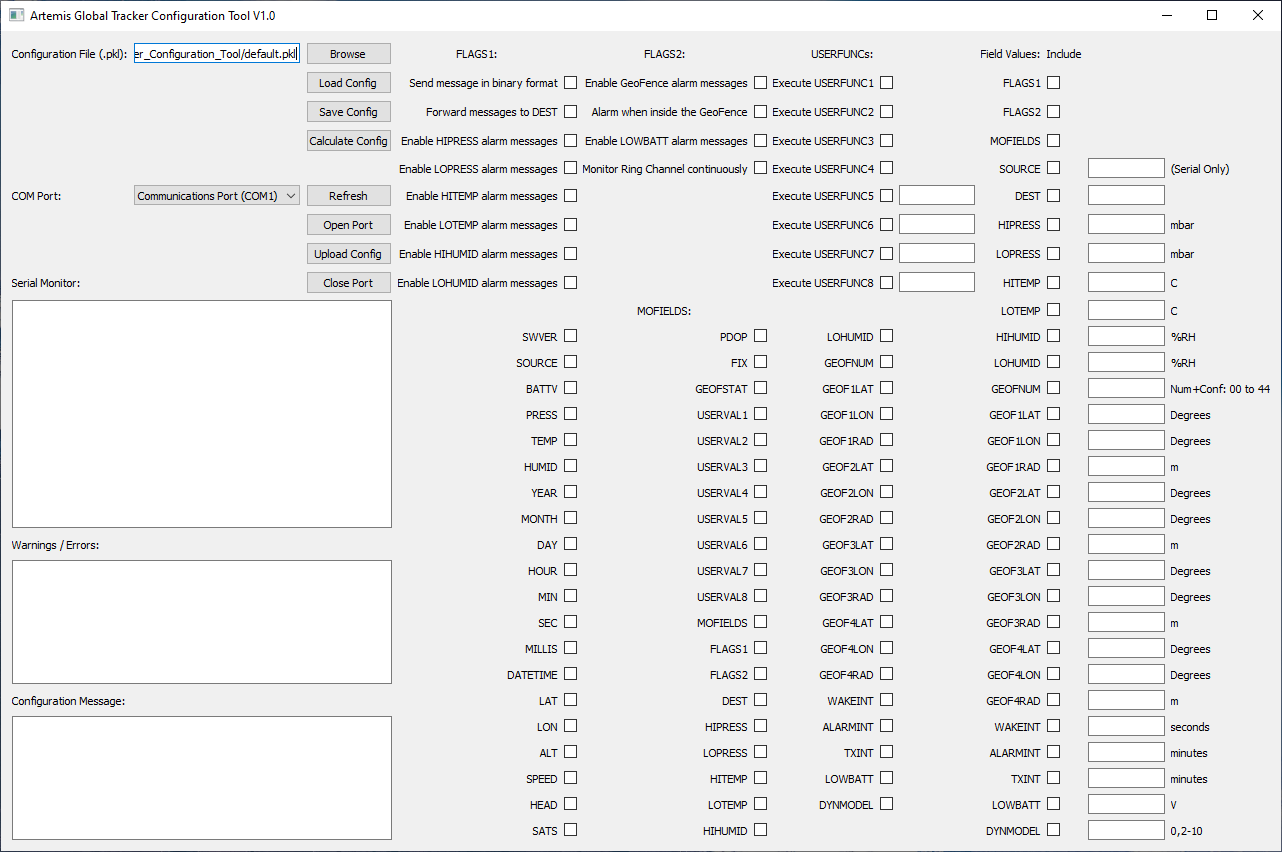
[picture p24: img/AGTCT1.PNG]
AGTCT1


[BACK](#How-do-I-configure-the-messages-sent-by-the-tracker)

### AGTCT2
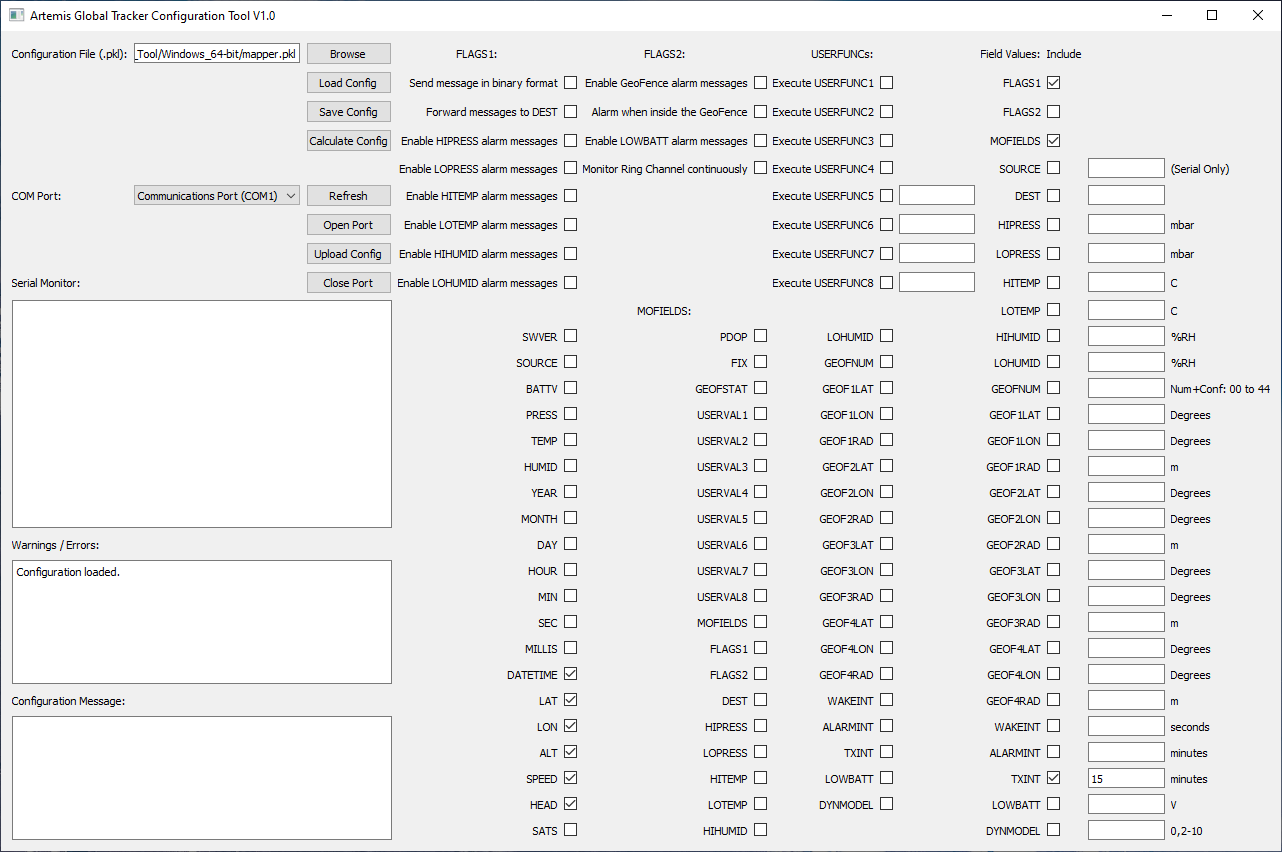
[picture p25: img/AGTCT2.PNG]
AGTCT2


[BACK](#How-do-I-configure-the-messages-sent-by-the-tracker)

### AGTCT3
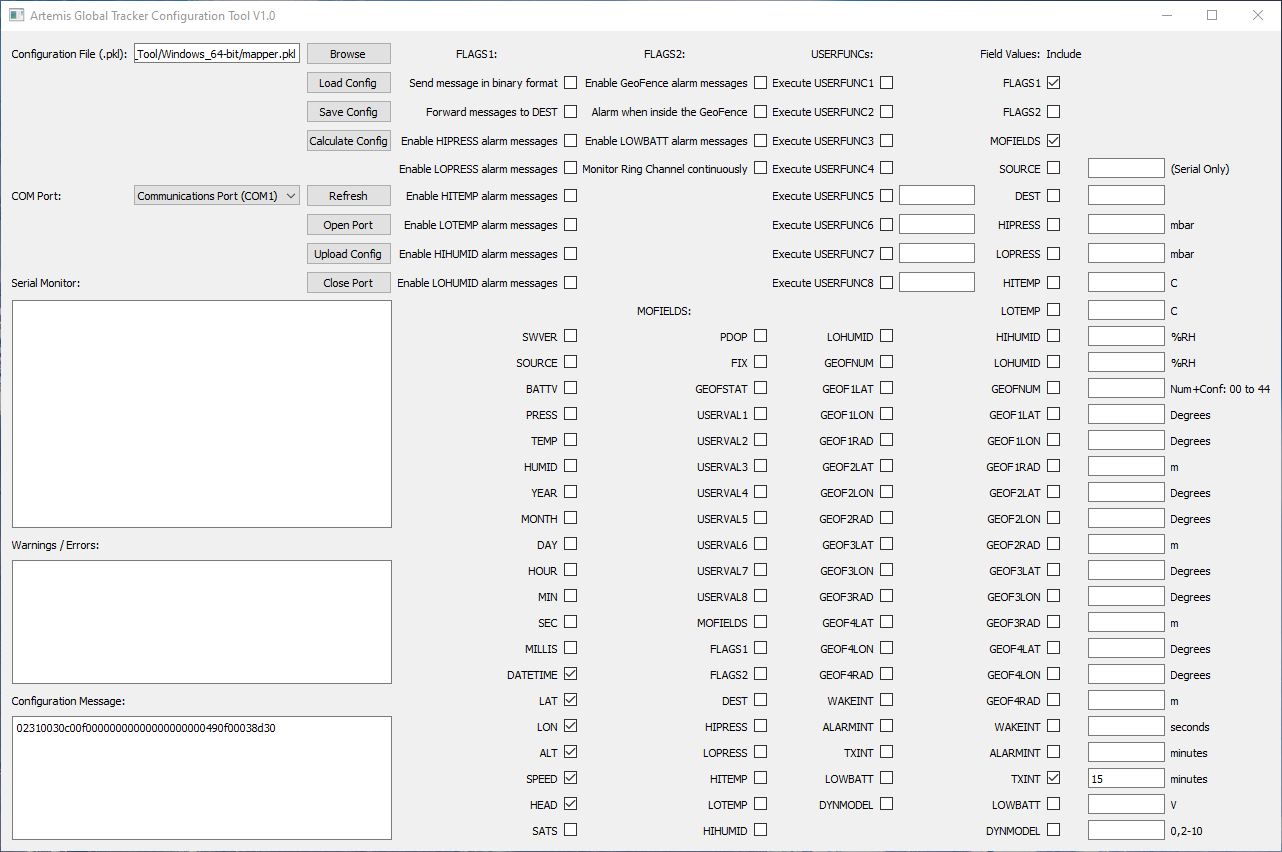
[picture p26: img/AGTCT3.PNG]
AGTCT3


[BACK](#How-do-I-configure-the-messages-sent-by-the-tracker)

### AGTCT4
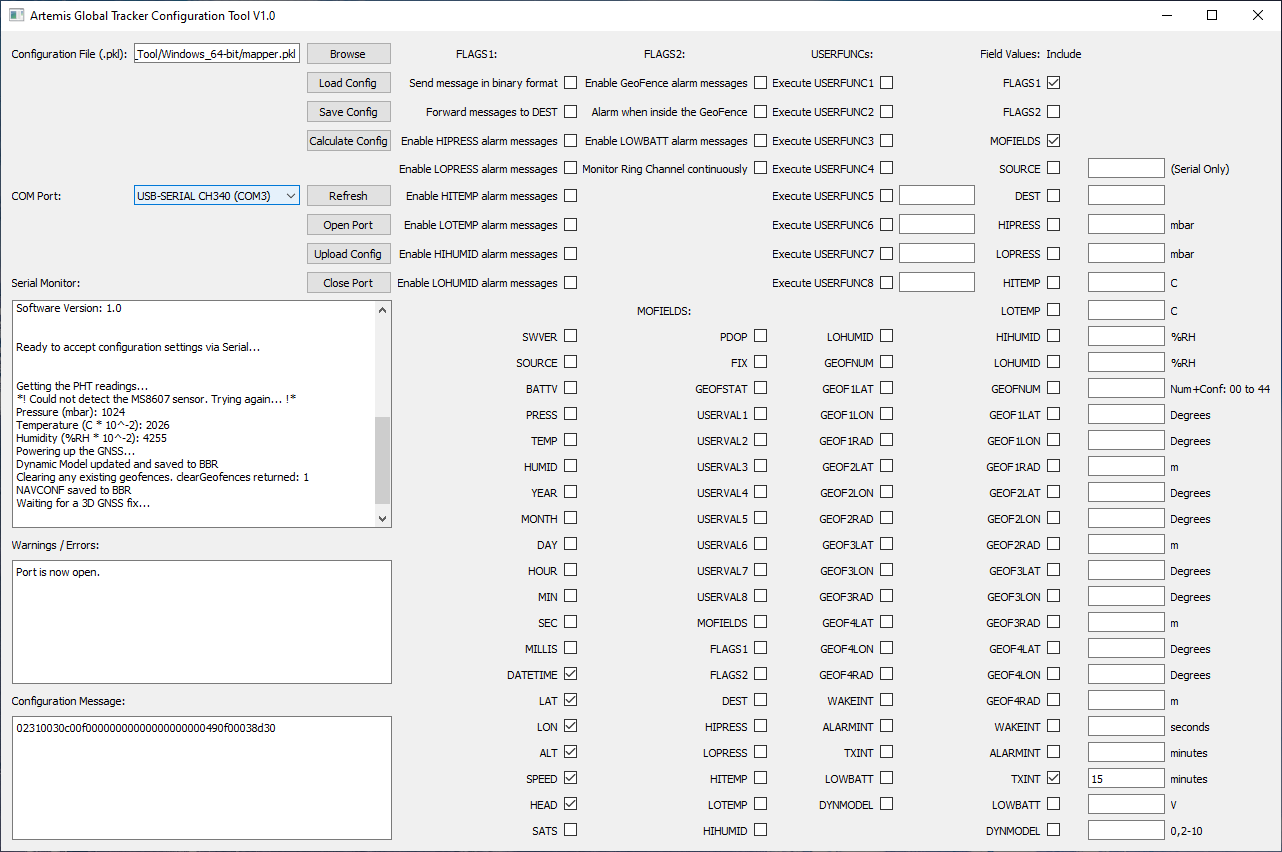
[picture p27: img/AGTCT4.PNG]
AGTCT4


[BACK](#Updating-the-configuration-via-USB)

### AGTCT5
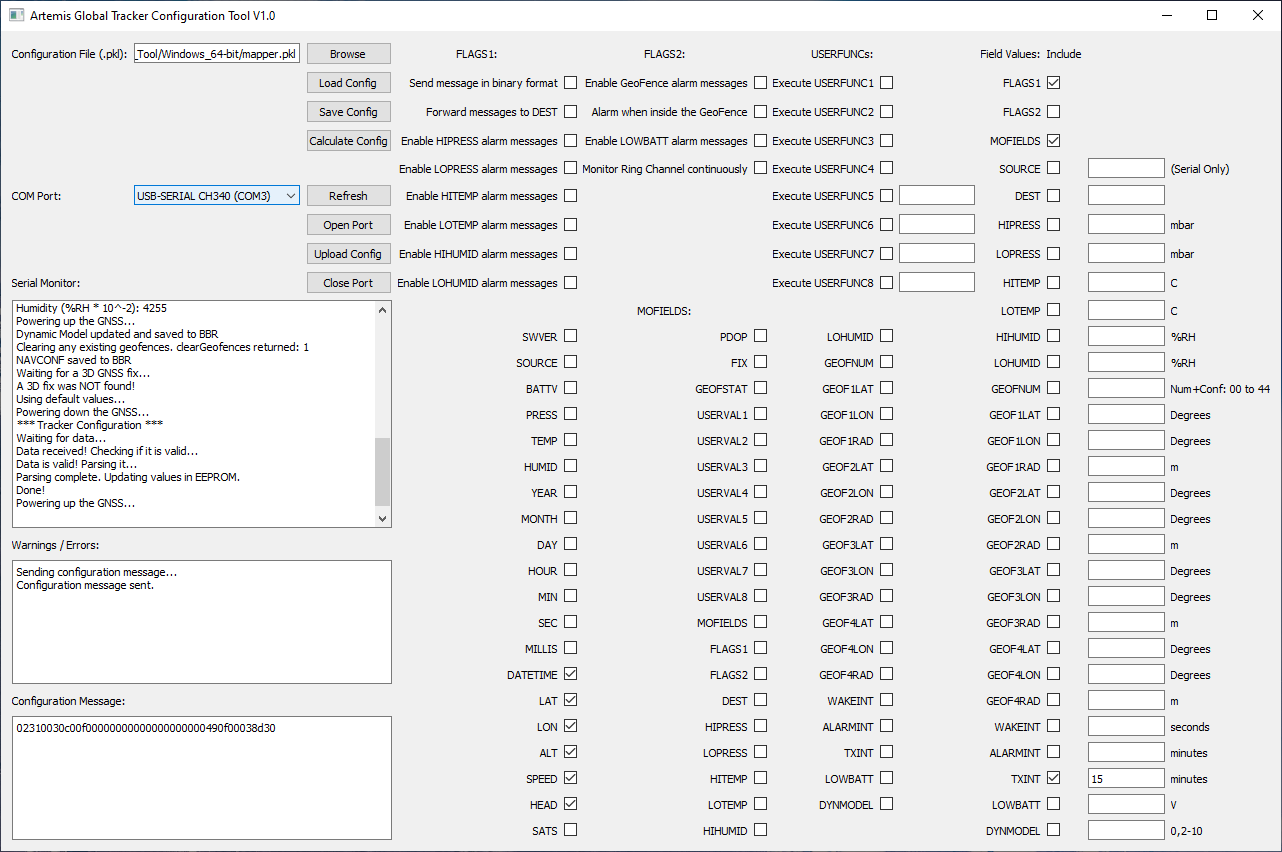
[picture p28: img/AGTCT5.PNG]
AGTCT5


[BACK](#Updating-the-configuration-via-USB)

### AGTCT6
AGTCT6

[BACK](#Updating-the-configuration-via-Iridium)

### AGTCT7
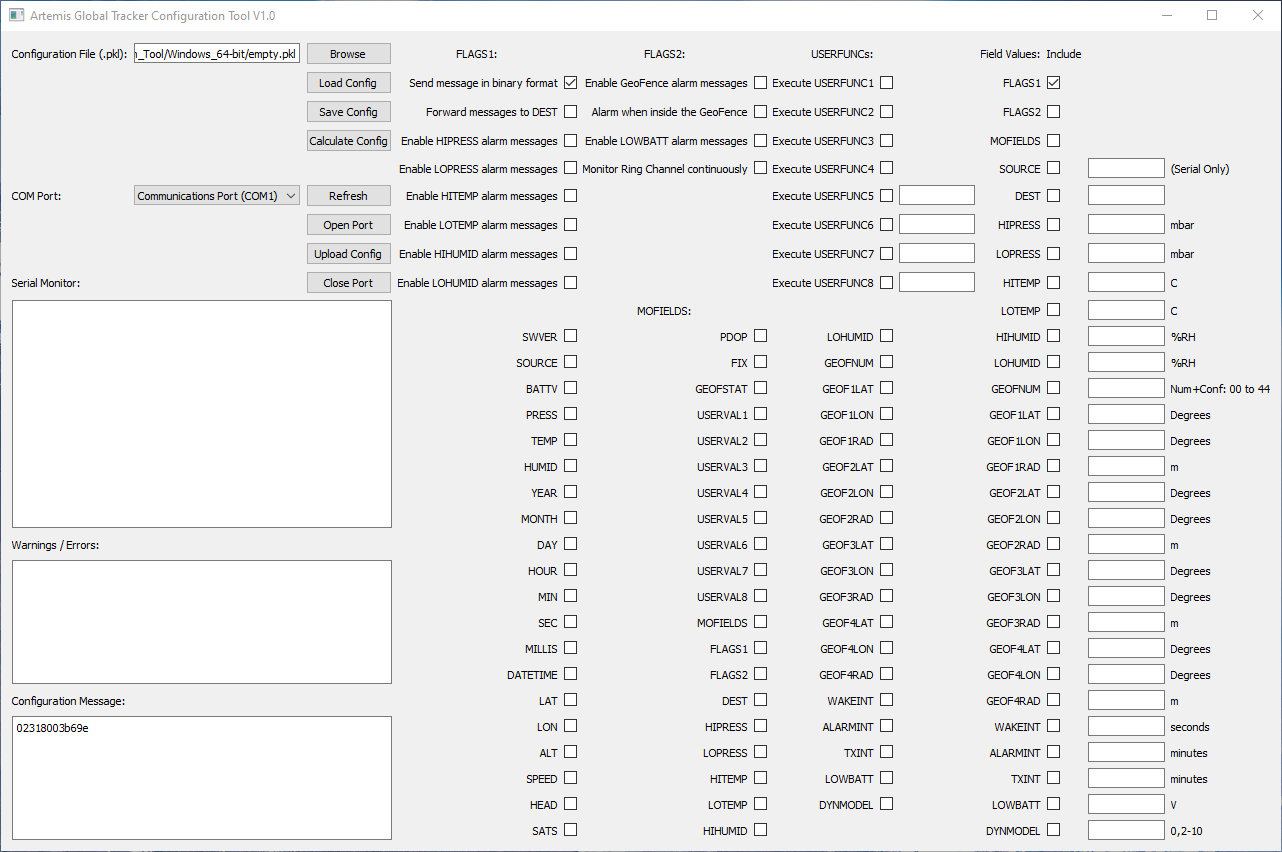
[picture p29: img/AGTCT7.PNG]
AGTCT7


[BACK](#How-do-I-send-binary-messages)

### AGTCT8
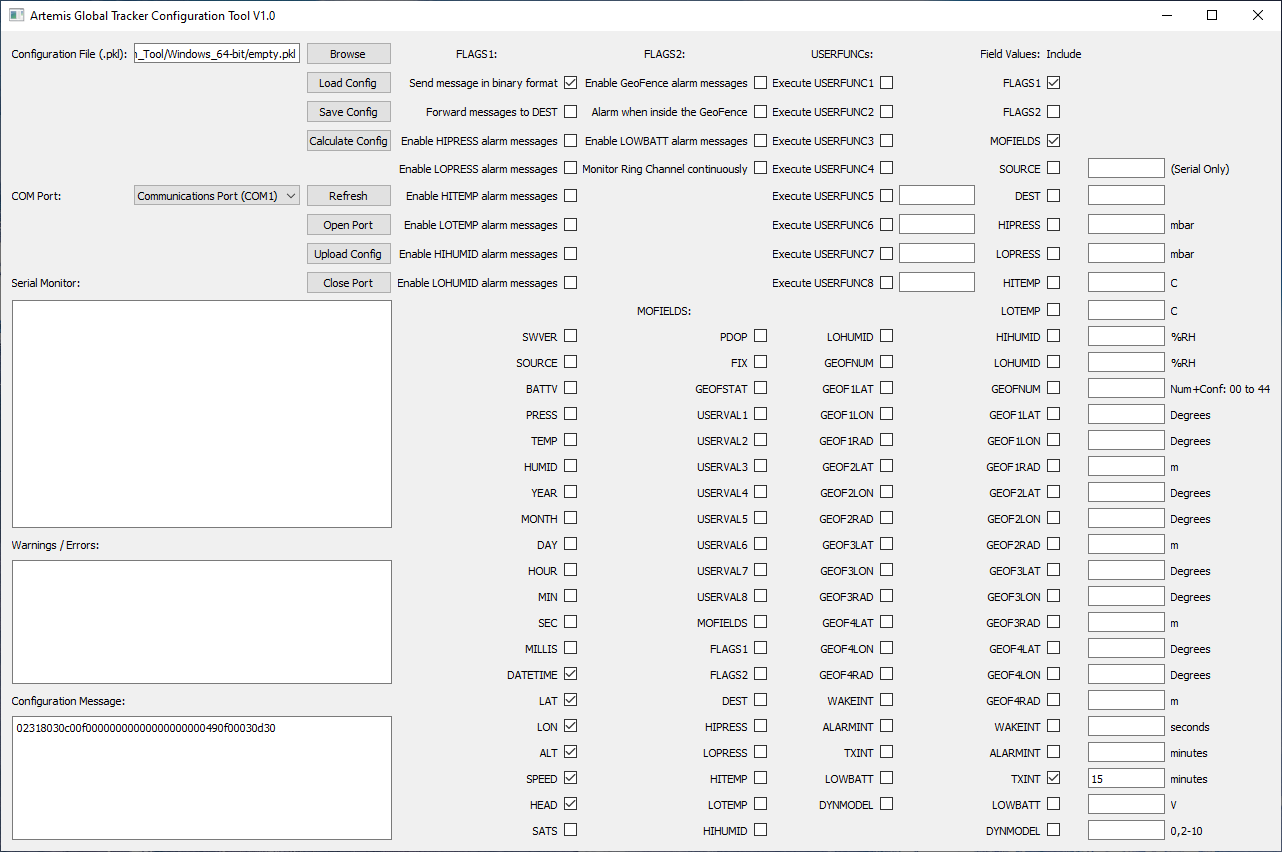
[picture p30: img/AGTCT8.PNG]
AGTCT8


[BACK](#How-do-I-send-binary-messages)

### AGTCT9
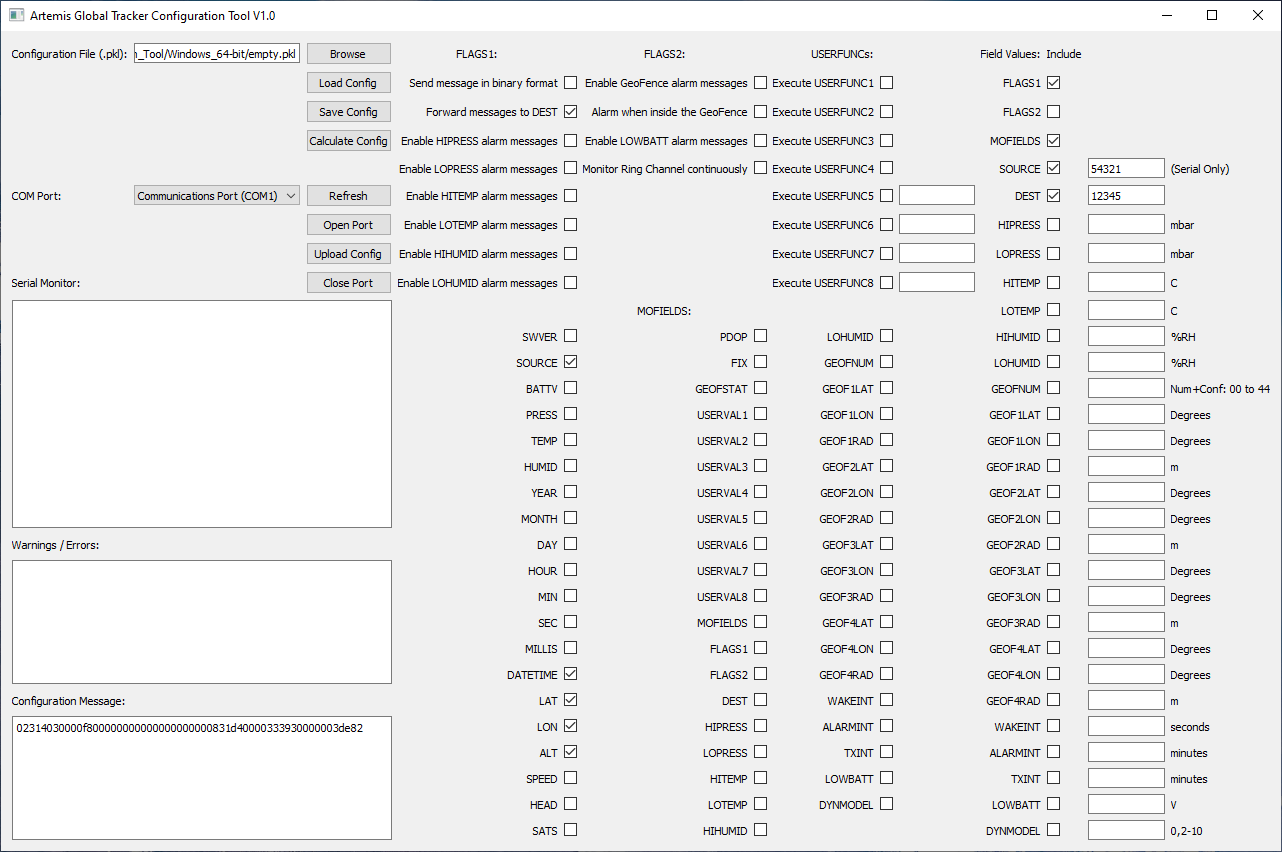
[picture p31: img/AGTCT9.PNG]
AGTCT9


[BACK](#How-do-I-enable-RockBLOCK-message-forwarding)

### AGTCT10
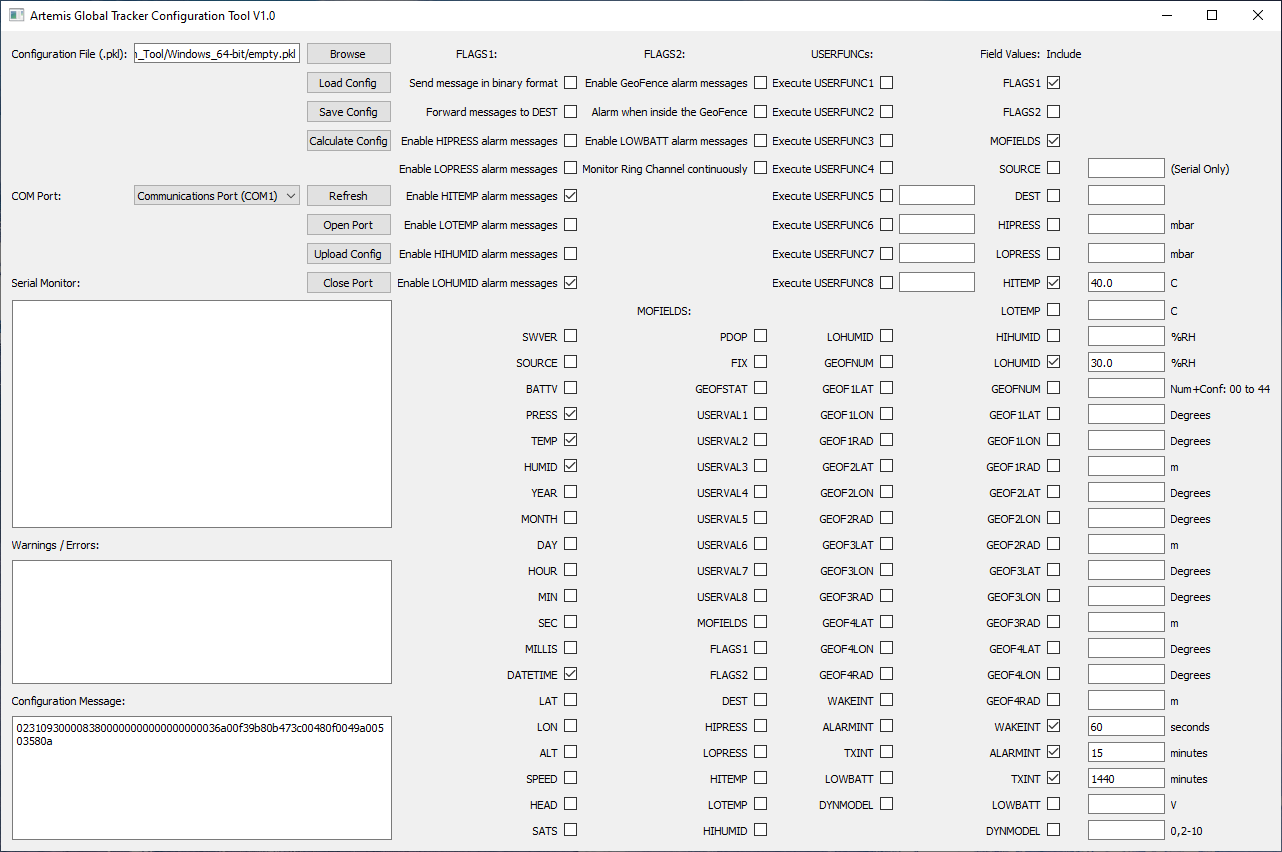
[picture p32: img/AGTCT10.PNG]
AGTCT10


[BACK](#How-do-I-enable-Pressure-Humidity-and-Temperature-alarms)

### AGTCT11
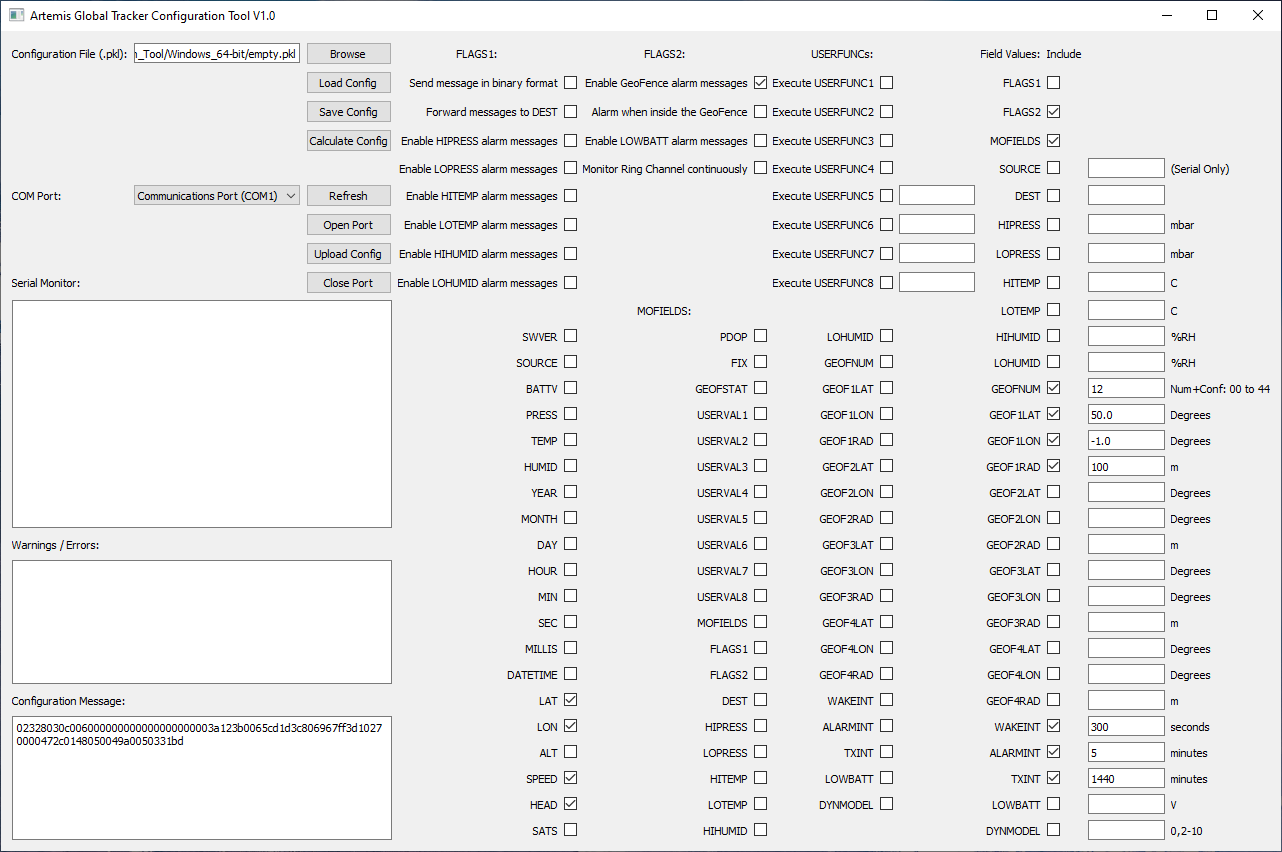
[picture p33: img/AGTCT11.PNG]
AGTCT11


[BACK](#How-do-I-enable-Geofence-alarms)

### AGTCT12
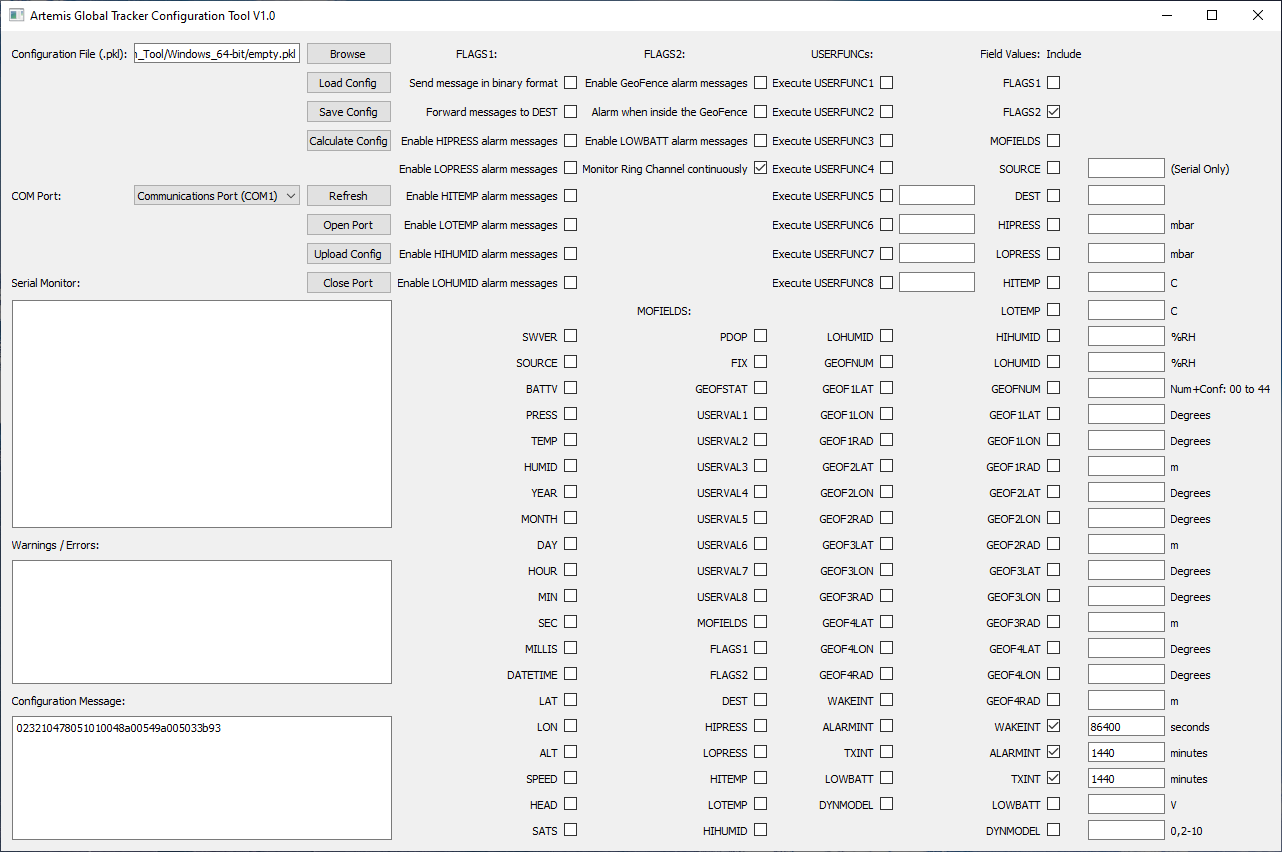
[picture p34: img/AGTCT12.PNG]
AGTCT12


[BACK](#How-do-I-monitor-the-ring-channel-continuously-for-new-MT-messages)

### AGTCT13
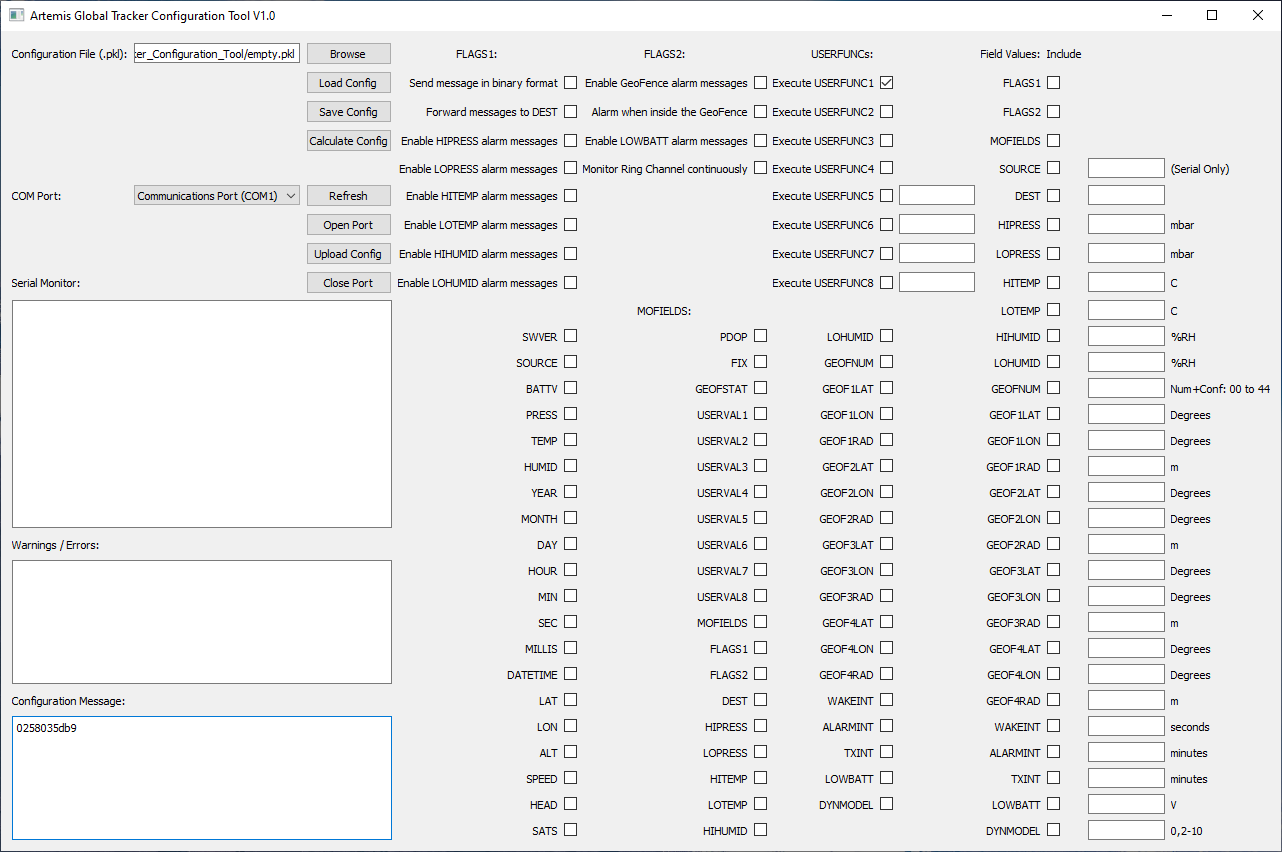
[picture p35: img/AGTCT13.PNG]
AGTCT13


[BACK](#How-do-I-define-and-trigger-a-user-function)

### AGTCT14
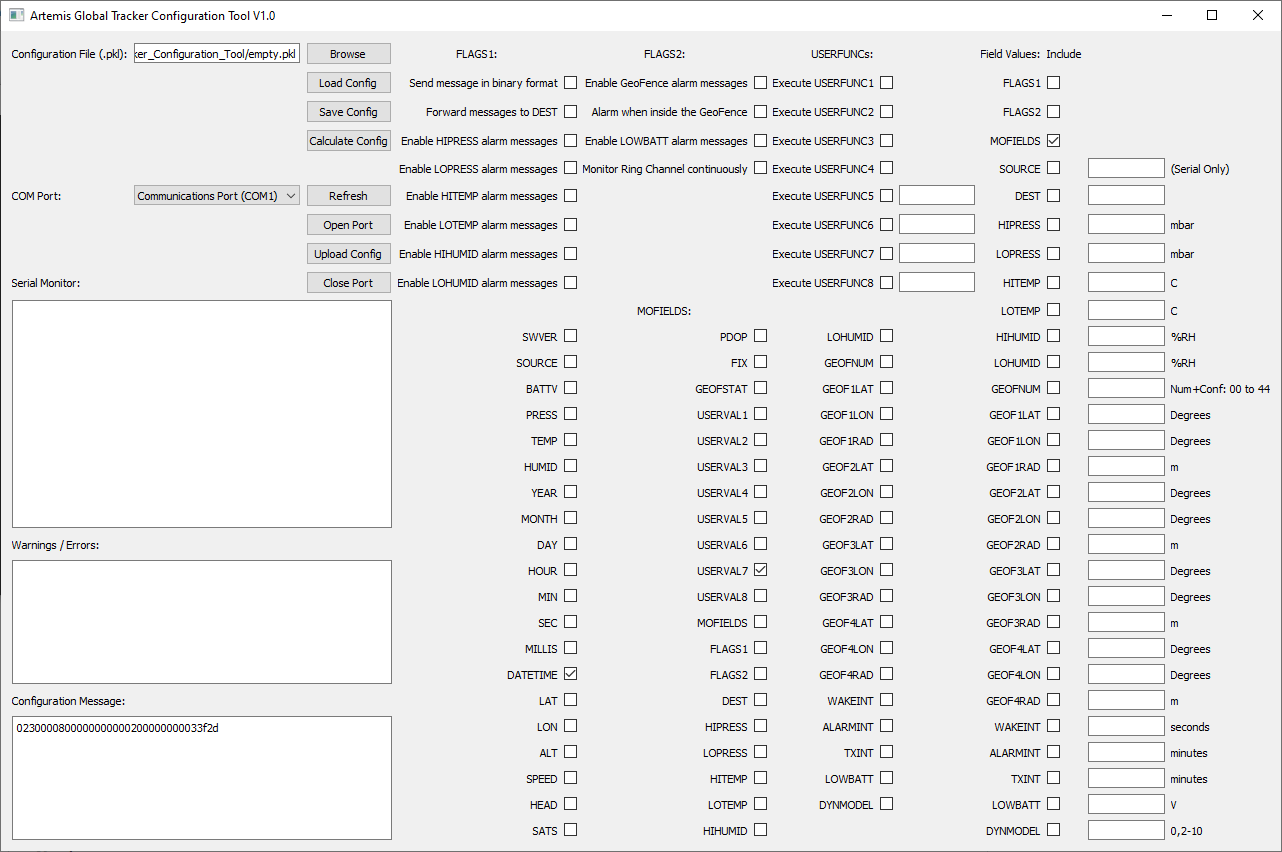
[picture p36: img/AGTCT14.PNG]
AGTCT14


[BACK](#How-do-I-send-a-user-value)

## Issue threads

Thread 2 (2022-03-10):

hello - FYI: project built on the AGT

jerabaul29, 2022-03-10:
Hi :)

FYI, we have released quite some materials about a project based on the AGT - not sure if you want to mention this somewhere on your Readme. Anyways, thanks for developing this great board :)

https://github.com/jerabaul29/OpenMetBuoy-v2021a

jerabaul29, 2022-03-10:
(this may include some examples of code etc that may be useful for other people too :) ).

Closed 2022-08-31.

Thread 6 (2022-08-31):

Is it possible that using a SMA cable degrades the signal?

jerabaul29, 2022-08-31:
In the OpenMetBuoy project, to get space for the antenna, we use an SMA cable extension.

https://www.sparkfun.com/products/12861

I thought that would be fine, however, a colleague (@tn77) found that using a 90 degrees SMA adapter (looks similar to https://www.digikey.no/no/products/detail/rf-solutions/ADP-SMAM-SMAF90/5845786?productid=5845786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 but @tnn77 can put the link to the one used maybe?), the signal reception for iridium seems quite a bit better.

Any thoughts about this? Can it be bad ampedance matching or something like this that is problematic with the SMA cable extension?

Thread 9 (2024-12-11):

Not Receiving Messages & Registration Problems

tschesnok, 2024-12-11:
I got the AGT up and running via Example 16 GlobalTracker.ino and am viewing output via serial terminal.

It seems that everything works.. GPS is correct location, same with other sensors. And best of all I get a "Send Message Success" from the Modem.

But I never get a message via https://rockblock.rock7.com/Operations.

Additional Info:
Registering the device on rock7.com did not initially work. I got an error. Their Admin eventually got it registered and I purchased a plan.
The modem was issuing success messages with or without an active plan or registration. Is that even possible?

Am I dealing with a back end issue or a modem issue? I assume it has satellite coverage given that the message send "succeeded"?

Closed 2024-12-12.

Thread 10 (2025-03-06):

Which diode is used for power?

gauteh, 2025-03-06:
Hi,

can you share which diode is used on the power input schema:

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

Thank you,
Gaute

nseidle, 2025-03-06:
[PMEG4005EJ,115](https://assets.nexperia.com/documents/data-sheet/PMEG4005EJ.pdf).

gauteh, 2025-03-06:
Thank you.

tor. 6. mars 2025, 16:53 skrev Nathan Seidle ***@***.***>:

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

Closed 2025-03-06.

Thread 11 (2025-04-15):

Board programmed with example 16 randomly stops sending GPS updates via Iridium

adrian-bodenmann, 2025-04-15:
We are using the SparkFun WRL-18712 board programmed with the code in example 16 and it sometimes stops transmitting GPS messages.

When monitoring the serial communication from the board, it eventually sends the following lines:
`*** modem.clearBuffers failed with error 3 ***`

followed by
`*** modem.begin failed with error 5 ***`, which is then sent repeatedly, and it never recovers until the board is restarted.

This happens randomly. Sometimes within 10s of minutes, sometimes within hours, sometimes it does not happen at all (tested for several days). We have now 3 SparkFun WRL-18712 boards and it happens on all of them. We originally had 1 that we noticed stopped transmitting GPS, so we initially thought there was an electrical issue, so bought 2 new ones, but the new ones have the same issue.

I did a lot of debugging, and it looks like the serial strings sent from the Iridium 9603 modem sometimes stop sending the line feed (LF), and sometimes the carriage return (CR) at the end of the terminator, i.e. "OK[CR]" or "OK" instead of "OK[CR][LF]".

waitForATResponse() in IridiumSBD.cpp then times out because it does not see the terminator it is expecting. That then causes an ISBD_PROTOCOL_ERROR (3) and afterwards an ISBD_NO_MODEM_DETECTED (5) error.

(Note: The missing "[LF]" or the "[CR][LF]" characters are sent at the start of the next transmission from the Iridium 9603 modem, but that does not happen until a new prompt (e.g. "AT") is sent to it).

adrian-bodenmann, 2025-04-15:
Small update / clarification
Iridium 9603 modem seems to be shifting what it is sending more and more backwards, i.e. starting with terminating messages with
"...OK[CR][LF]", then
"...OK[CR]", then
"...OK", then
"...O"
This always seems to happen first in the reply message to the prompt "AT+CGMR".

Previously I thought of using "OK" as terminator string instead of "OK[CR][LF]" as a workaround, but this now does not seem to be an option either.

PaulZC, 2025-04-15:
Just copying my reply from the Forum:

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

PaulZC, 2025-04-15:
Hi Adrian (@adrian-bodenmann ),

Please try enabling the extra diagnostic messages:

```#define DIAGNOSTICS true // Change this to true to see IridiumSBD diagnostics```

They may provide more clues?

Best,
Paul

adrian-bodenmann, 2025-04-23:
Thank you for your reply.
I am using Version 2.2.1 of Apollo3 core. So it looks like this causes the issue.

The reason why I used 2.2.1 is that 2.1.0 causes another other issue, and I assumed that the issue from 2.1.1 would have been fixed by 2.2.1.

Version 2.1.0 causes the following issue: If the program is (re)started while the Iridium modem is on (red LED on), it gets stuck at modem.begin() forever. This does not happen with version 2.2.1.

The boards are connected by the USB cable. No extra batteries attached.

I've been running the code with the DIAGNOSTICS enabled, and I added more `consoleprint`s or adapted them (e.g. printing `[CR]` instead of the invisible `\r`)

This is an example of the code running well to start with, using Version 2.2.1 of Apollo3 core:
```
2025-04-23 10:33:36.378 INFO  Received on serial: >> AT
2025-04-23 10:33:36.378 INFO  Received on serial: Waiting for response OK
2025-04-23 10:33:36.378 INFO  Received on serial: << AT[CR][CR][LF]OK[CR][LF]
2025-04-23 10:33:36.378 INFO  Received on serial: >> ATE1
2025-04-23 10:33:36.378 INFO  Received on serial: Waiting for response OK
2025-04-23 10:33:36.393 INFO  Received on serial: << ATE1[CR][CR][LF]OK[CR][LF]
```

And this is 6 minutes later, where the linefeed ([LF]) character is read late, presumably due to the bug in Version 2.2.1 of Appollo3:
```
2025-04-23 10:39:23.139 INFO  Received on serial: >> AT
2025-04-23 10:39:23.139 INFO  Received on serial: Waiting for response OK
2025-04-23 10:39:23.139 INFO  Received on serial: << [LF]AT[CR][CR][LF]OK[CR]
2025-04-23 10:39:52.704 INFO  Received on serial: waitForATResponse timed out
2025-04-23 10:39:53.704 INFO  Received on serial: >> AT
2025-04-23 10:39:53.706 INFO  Received on serial: Waiting for response OK
2025-04-23 10:39:53.706 INFO  Received on serial: << [LF]AT[CR][CR][LF]OK[CR]
```
In this occurence the error happened after 6 minutes, but it it varies between minutes, hours, to not occurring at all, with exactly the same setup.

I am a bit surprised the UART bug in Appollo3 has been known for such a long time and is not fixed, because I am sure it causes very hard to debug issues for others as well. Are there plans to fix this in a future release?

For the above-mentioned reason rolling back to 2.1.0 is not really a viable solution

PaulZC, 2025-06-06:
Hi Adrian (@adrian-bodenmann ),

Apologies. I took my eye off the ball here...

Just for background, if you follow the [comment link](https://github.com/sparkfun/Arduino_Apollo3/issues/423) in the code, you can follow the fun we had diagnosing the RX-pin-held-low issue:

https://github.com/sparkfun/SparkFun_Artemis_Global_Tracker/blob/3212a30d17952d89d7fb301f154e82907fe01a70/Software/examples/Example16_GlobalTracker/Example16_GlobalT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

Sadly, the SparkFun Artemis (Apollo3) core isn't actively maintained, due to staff changes over the years. Patching the core is not a simple job...

But, to _hopefully_ get you going, please try the following:

1. In `Example16_GlobalTracker.ino`, around [line 110](https://github.com/sparkfun/SparkFun_Artemis_Global_Tracker/blob/3212a30d17952d89d7fb301f154e82907fe01a70/Software/examples/Example16_GlobalTracker/Example16_GlobalT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), add a global flag:

```
bool Serial1Begun = false; // Flag to indicate if Serial1 has been begun
```

2. In `IridiumSBD::beginSerialPort()` ([line 267](https://github.com/sparkfun/SparkFun_Artemis_Global_Tracker/blob/3212a30d17952d89d7fb301f154e82907fe01a70/Software/examples/Example16_GlobalTracker/Example16_GlobalT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)), set the flag true at the end of that function:

```
  Serial1.begin(19200);
  Serial1Begun = true; // Flag that Serial1 has been begun
}
```

3. In `IridiumSBD::endSerialPort()` (immediately follows `IridiumSBD::beginSerialPort()`), add code to call `Serial1.end` if Serial1 has been begun:

```
void IridiumSBD::endSerialPort()
{
  diagprint(F("custom IridiumSBD::endSerialPort\r\n"));

  if (Serial1Begun) // If begun, close the port
  {
    Serial1.end();
    Serial1Begun = false;
  }

  // Disable the Serial1 RX pin to avoid the code hang
  am_hal_gpio_pinconfig(PinName(D25), g_AM_HAL_GPIO_DISABLE);
}
```
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
PaulZC, 2025-06-18:
PS. You can avoid the 5 minute wait by changing `#define GNSS_timeout 5UL` to `#define GNSS_timeout 1UL` (Line ~168).

PaulZC, 2025-06-18:
Thanks Adrian,

This really has me scratching my head. I can't explain why the code runs successfully on some boards and not others. I think it must be some weird version of the RX-pin-held-low issue, but I'm really not sure. I'll keep looking at it...

All the best,
Paul

adrian-bodenmann, 2025-06-24:
I got a new supecap and replaced the broken one on our black board. Before replacing it, the voltage was around 2.6V or so when the cap was powered, but when the Iridium modem was turned off, the voltage slowly dropped. With the new one this does not happen and both supercaps keep their voltage stable, even when the Iridium modem is turned off by the Arduino.
However, it does not change how the software behaves. If I restart the code (reconnect the serial port) while it is trying to transmit, it works fine, without getting stuck at "Starting modem...".

Have you made made any progress with identifying why your green board and our red boad gets stuck at "Starting mode..." after restarging the code while it is transmitting?

PaulZC, 2025-06-25:
Hi Adrian,

Thanks for the update. I'm glad you were able to replace the supercap successfully.

No, sorry, I haven't made any further progress.

The code should restart cleanly when it is 'reset' via the serial monitor. Right now, I can't explain why it is hanging at `Serial1.begin()`. All I can think of is that the hardware is left in some weird, partially-initialized state after the 'reset'. Perhaps because the modem is still active when the reset occurs. If I use the reset button instead of closing/opening the serial monitor, it does start the serial port correctly. Maybe the longer reset helps?

But I'm guessing you're not closing/opening the port when the unit is in the robot? Please tell me more about how you are using the system inside the robot. Is it permanently powered? Or are you switching the power? Are you providing power via USB? From what? Is it a dumb power supply, or are the USB data lines active?

Do you monitor the internal temperature of the robot? The cap venting electrolyte could have been caused by it being too hot. JR, another scientist using the AGT, has noticed temperature-related faults. Please see #8 for his notes. He sees issues at low temperatures. I'm wondering if you are seeing similar issues - but at high temperatures?

Best wishes,
Paul

adrian-bodenmann, 2025-06-25:
Pressing the reset button is unfortunately not an option for us..
Looking into the code, `Serial1.begin()` calls `void UART::begin(unsigned long baudrate, uint16_t config)` in HardwareSerial.cpp, and something must be going wrong there. Is there a way to debug this? `diagprint()` obviously does not work. Is there any other way of outputting messages on the serial line?

On the underwater robot we power the board via USB and via the battery, so the board keeps running even if tha main battery of the robot runs out of power. We do this as the only way to find the robot again is to have its GPS location, and if we don't have it, we lose the robot.
On the robot, power on the USB port is switched on when the robot is powered. We don't have any precise control when the program communicating with the Sparkfun board opens the serial connection. We also might close the program and open it again later (i.e. re-connecton on serial).
Currently I am running the tests just with the board powered via USB, no battery attached, and monitor the serial line.

We should have temperature logs of the CPU board. My colleague will download those tomorrow and check if the temperature was any higher than usual on the day the supercap (likely) failed.
We haven't seen any issues to the ones JR described.

adrian-bodenmann, 2025-06-25:
With Apollo3 version 2.1.1 it gets stuck at Serial1.begin(), but with Apollo3 version 2.2.0 it does not. So a change between those versions made the problem go away, but there is no change to the UART class between those versions. Do you seen any changes between the verisons that explains this?

PaulZC, 2025-06-26:
Here's an example of using a debugger on Apollo3:

https://github.com/sparkfun/Arduino_Apollo3/issues/401#issuecomment-860016907

adrian-bodenmann, 2025-06-26:
Hi Paul,

We do need the serial connection as we want to be able to talk to the board.

Tough the code being restarted every time we connect via serial is indeed a feature we don't actually need. If we could avoid the console reset that would be quite a good work around. How do we do that (ideally without losing ability to program the board)?

Best,
Adrian

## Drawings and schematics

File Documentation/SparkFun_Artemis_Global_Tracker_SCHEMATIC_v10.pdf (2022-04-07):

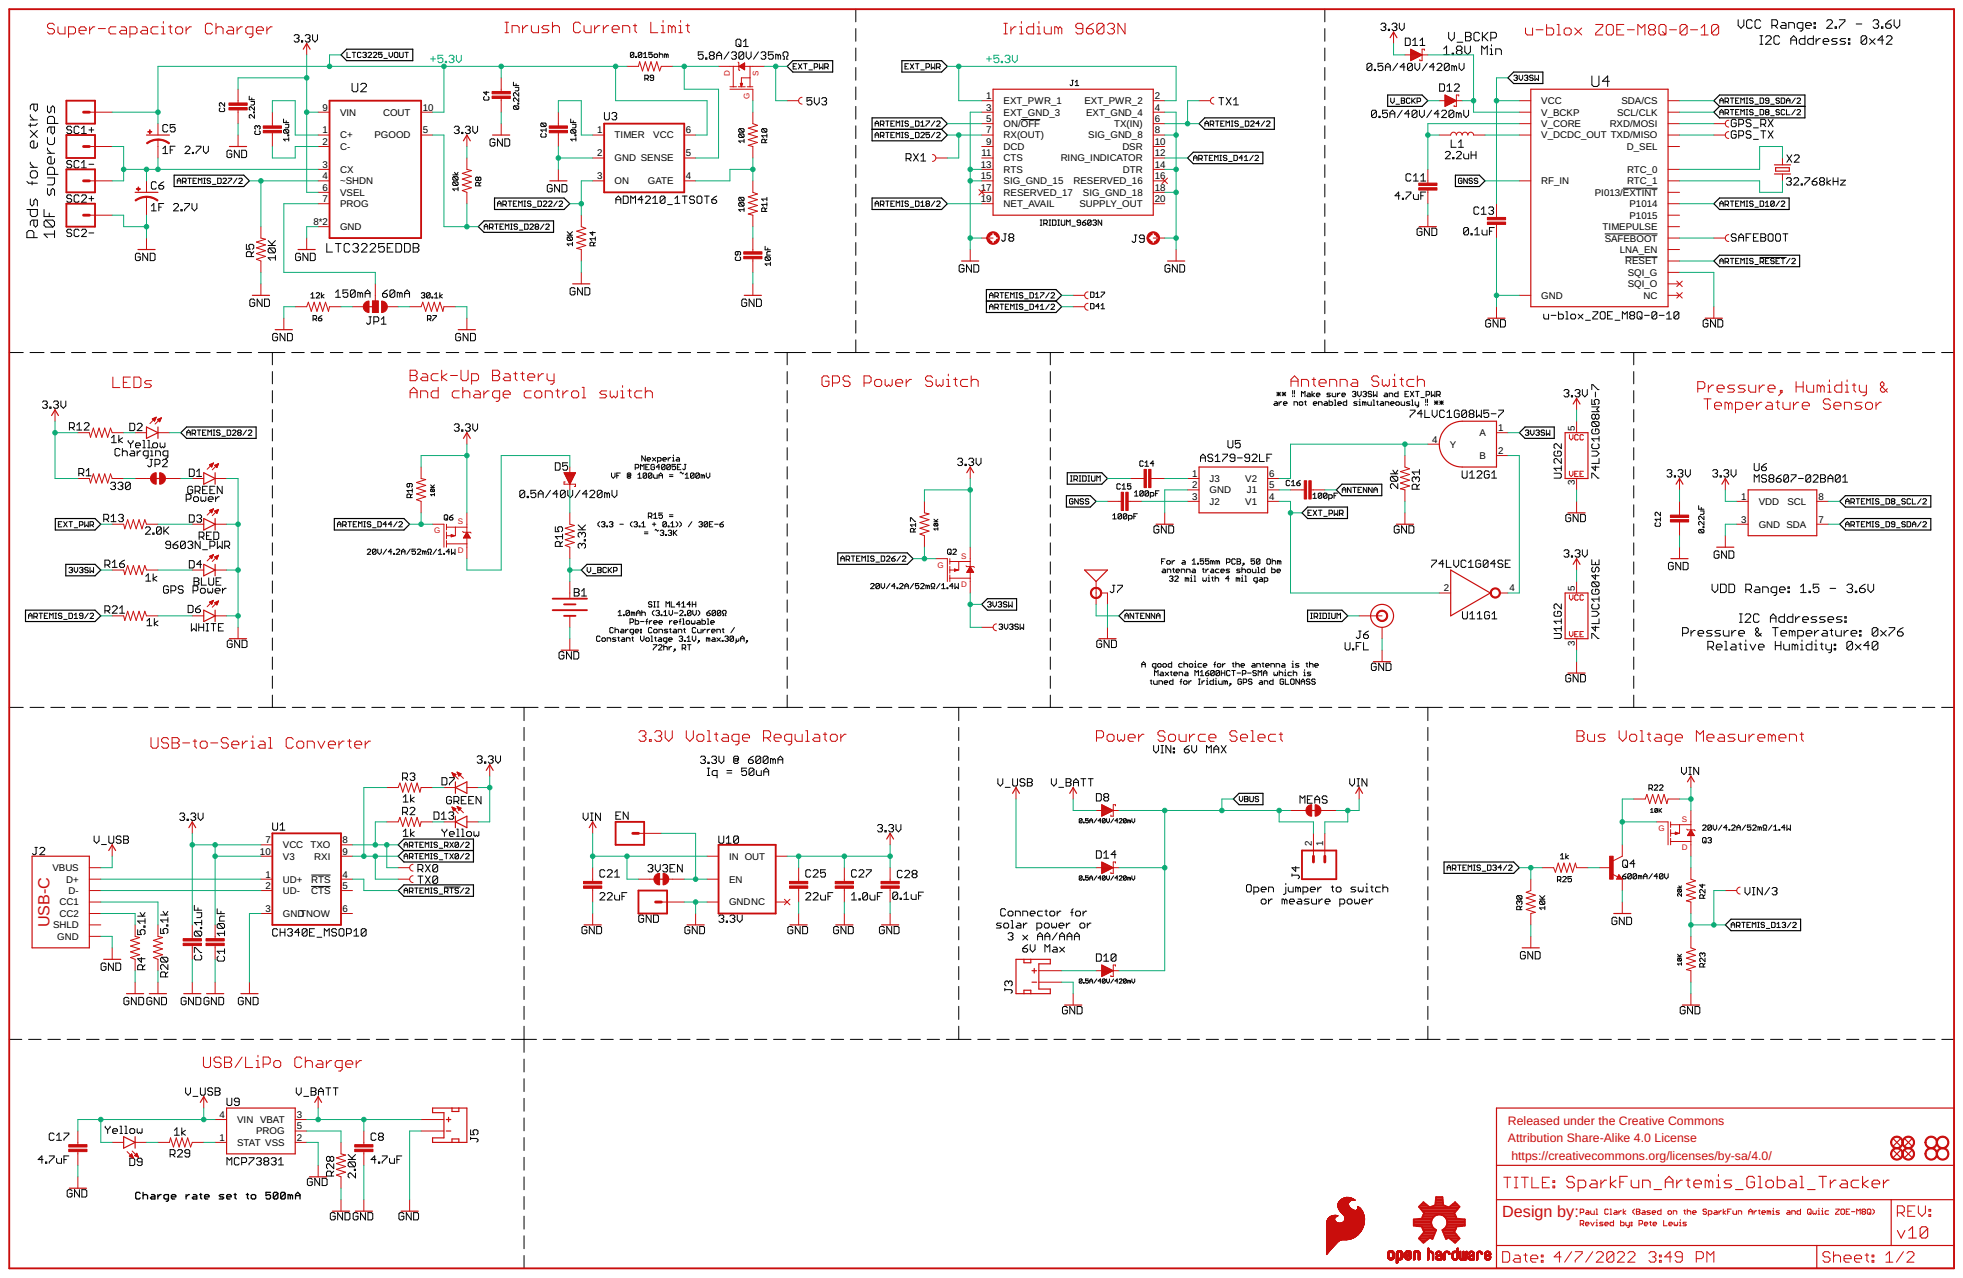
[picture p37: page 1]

SDA/CS
SCL/CLK D_SEL RXD/MOSI TXD/MISO

Released under the Creative Commons Attribution Share-Alike 4.0 License

https://creativecommons.org/licenses/by-sa/4.0/

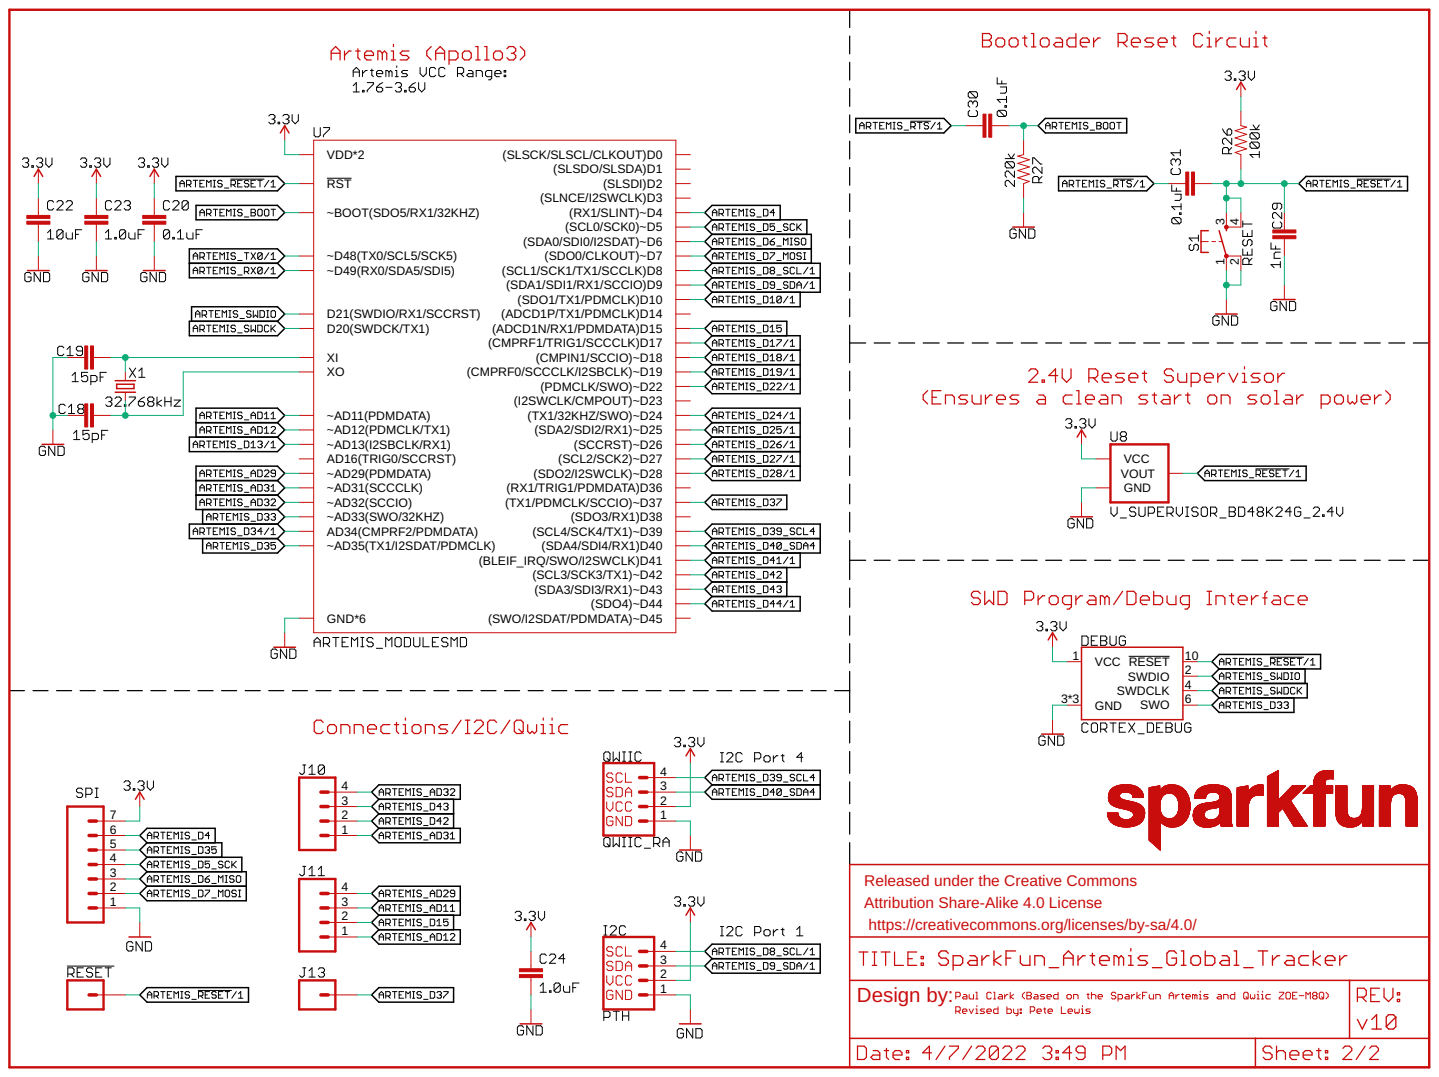
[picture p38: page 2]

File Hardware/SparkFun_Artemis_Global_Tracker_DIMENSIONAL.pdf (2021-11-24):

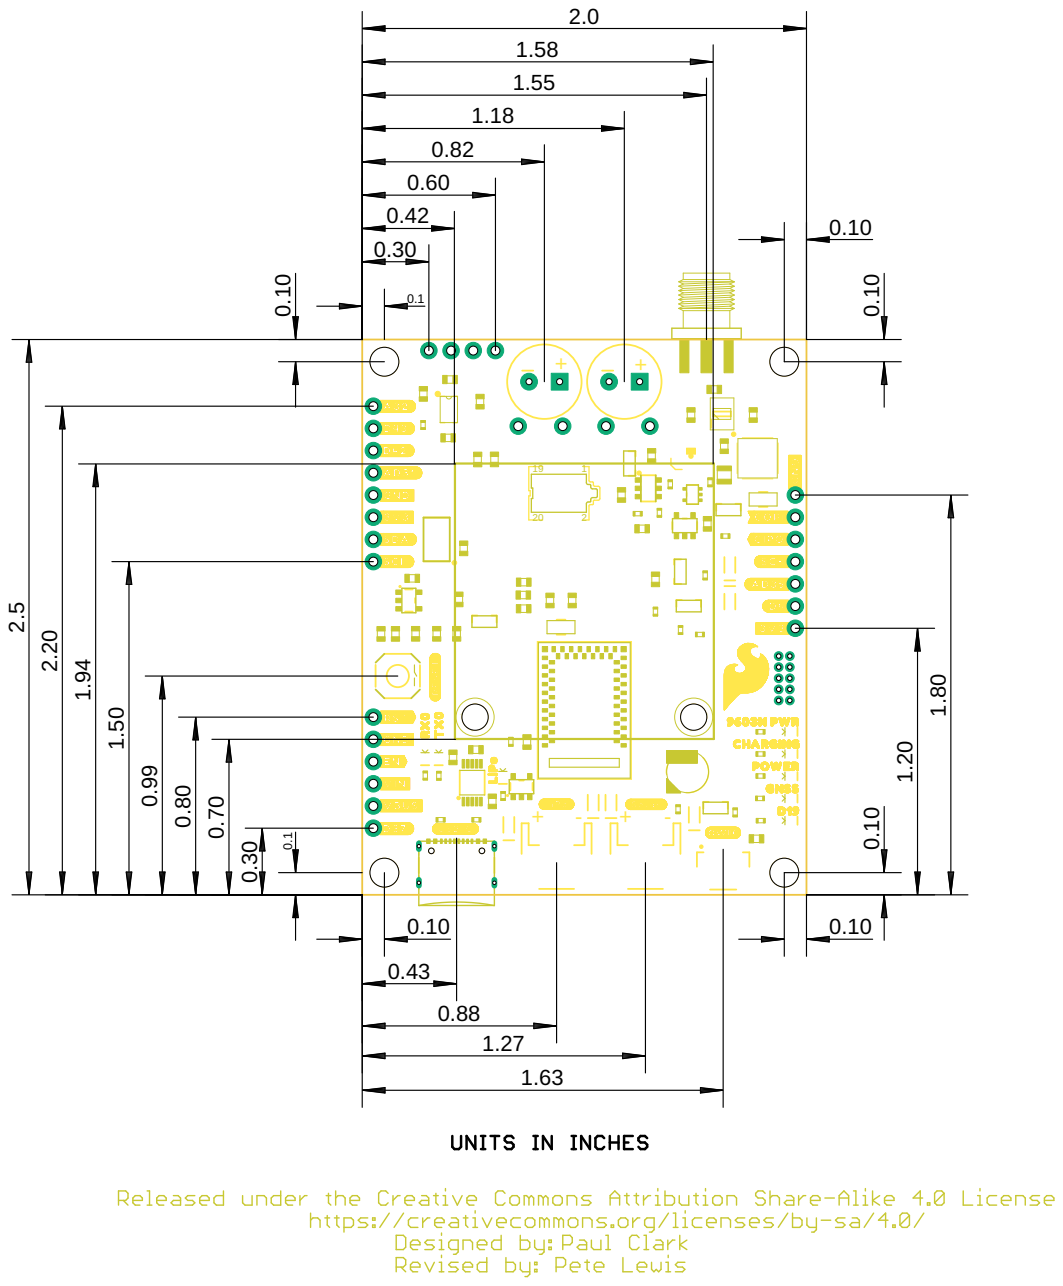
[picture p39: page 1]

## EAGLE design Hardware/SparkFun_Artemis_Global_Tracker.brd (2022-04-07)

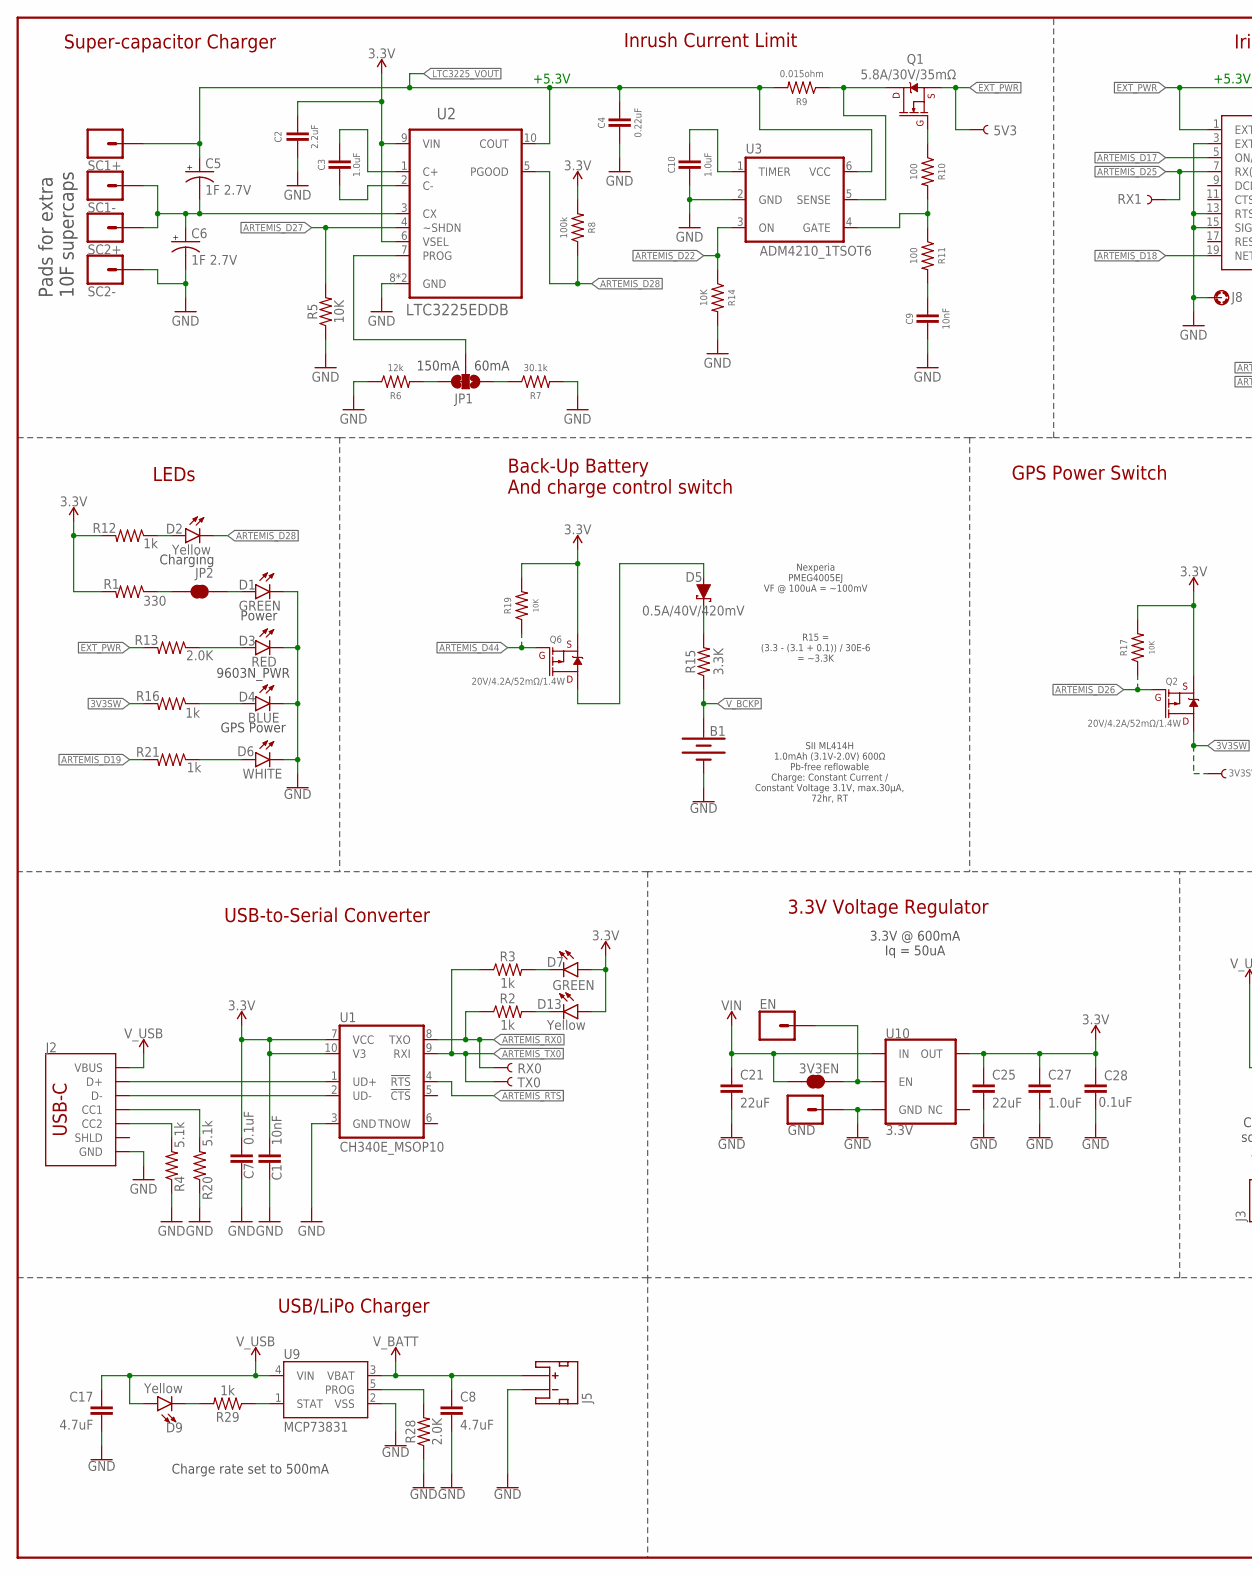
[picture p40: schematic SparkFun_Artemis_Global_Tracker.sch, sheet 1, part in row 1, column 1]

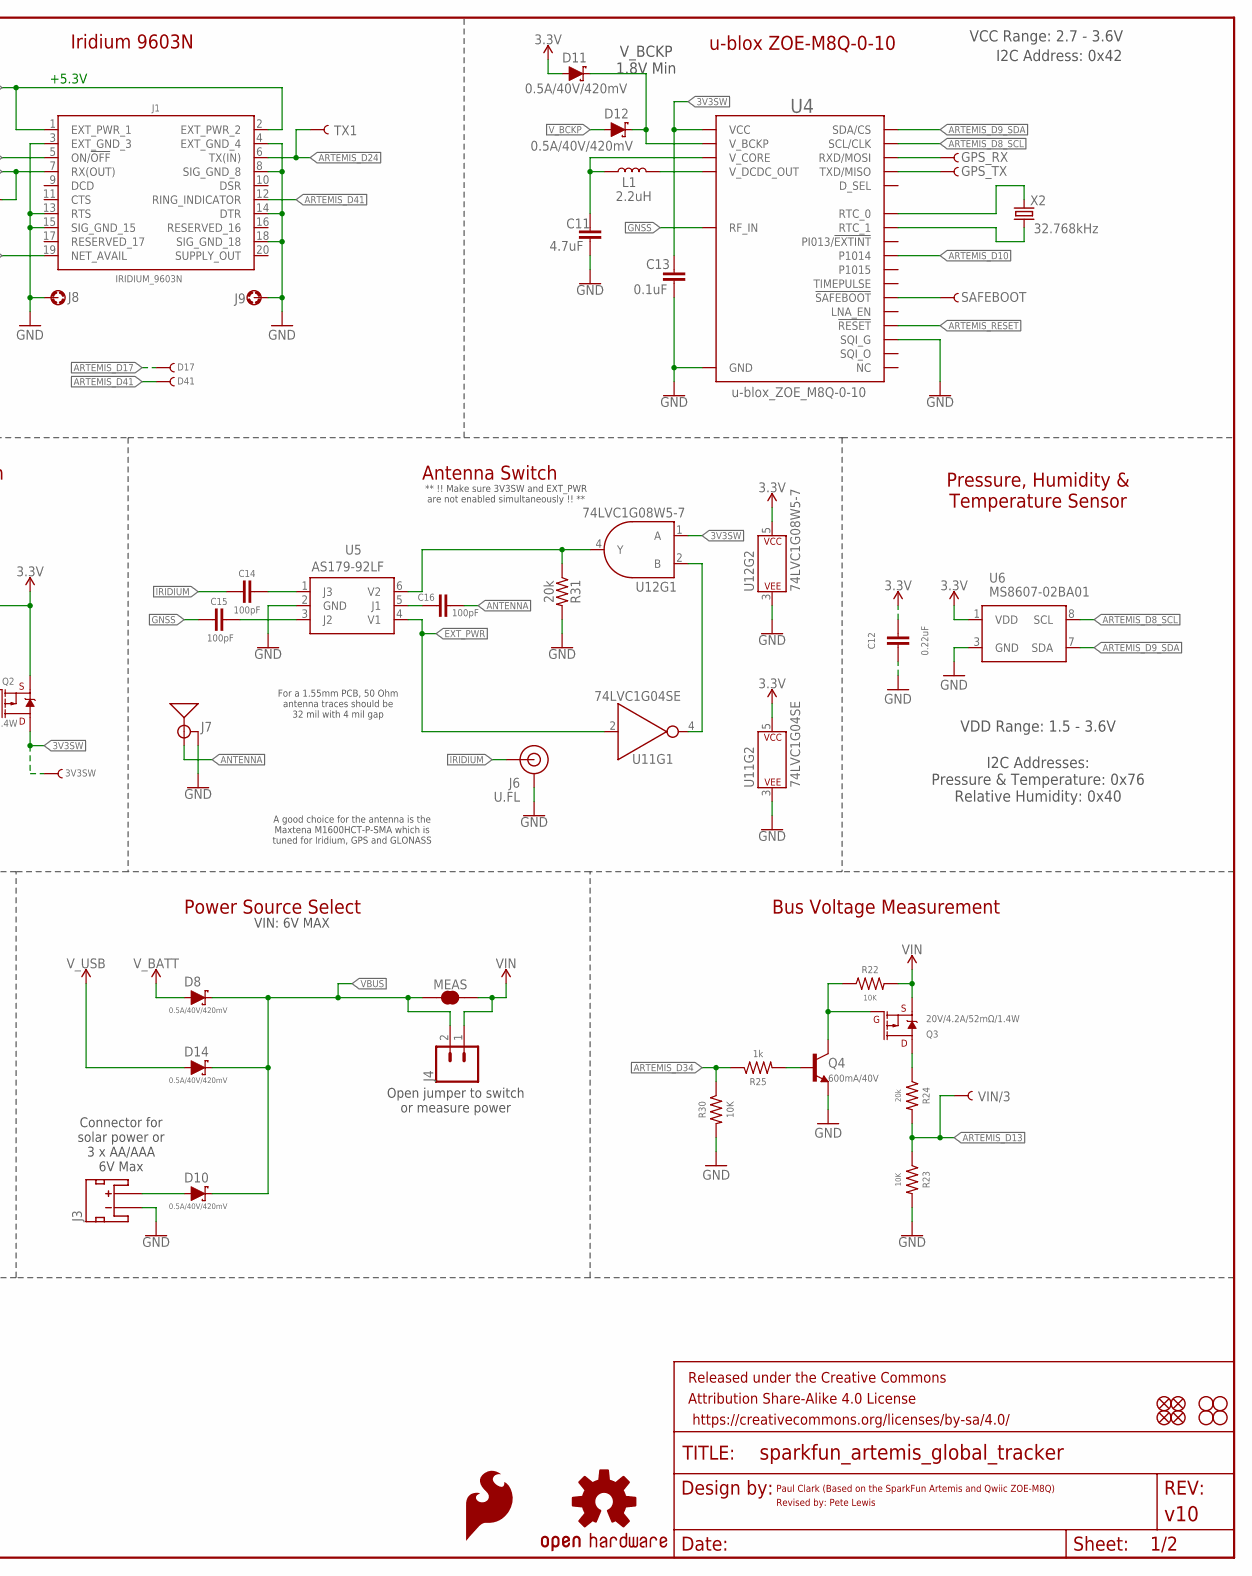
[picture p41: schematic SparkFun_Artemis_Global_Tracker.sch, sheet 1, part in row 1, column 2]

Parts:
3V3EN: JUMPER-SMT_2_NC_TRACE_SILK; SMT-JUMPER_2_NC_TRACE_SILK
3V3SW, 5V3: TEST-POINT3X5; PAD.03X.05
B1: ML414H_IV01E_BATTERY; ML414H_IV01E
C1, C9: 10nF; 0603
C2: 2.2uF; 0603
C3, C10, C27: 1.0uF; 0603
C4, C12: 0.22uF; 0603
C5, C6: 1F 2.7V; CPOL-RADIAL-1F-2.7V
C7, C13, C28: 0.1uF; 0603
C8, C11, C17: 4.7uF; 0603
C14, C15, C16: 100pF; 0603
C21, C25: 22uF; 0805
D1, D7: GREEN; LED-0603
D2, D9, D13: Yellow; LED-0603
D3: RED; LED-0603
D4: BLUE; LED-0603
D5, D8, D10, D11, D12, D14: 0.5A/40V/420mV; SOD-323
D6: WHITE; LED-0603
D17, D41: TEST-POINT3X5; PAD.03X.05
EN: CONN_01PTH_NO_SILK_YES_STOP; 1X01_NO_SILK
FRAME5: FRAME-LEDGER; CREATIVE_COMMONS
GND: CONN_01PTH_NO_SILK_YES_STOP; 1X01_NO_SILK
GPS_RX: TEST-POINT3X5; PAD.03X.05
GPS_TX: TEST-POINT3X5; PAD.03X.05
J1: IRIDIUM_9603N
J2: USB-C; USB-C-16P-2LAYER-PADS
J3, J5: JST_2MM_MALE; JST-2-SMD
J4: CONN_021X02_NO_SILK; 1X02_NO_SILK
J6: U.FL
J7: ANTENNA-GROUNDEDEDGE_SMA; SMA-EDGE
J8, J9: STAND-OFF-REFLOW-M2.0_6.0MM_TALL; STAND-OFF-REFLOW-M2.0
JP1: JUMPER-SMT_3_1-NC_TRACE_SILK; SMT-JUMPER_3_1-NC_TRACE_SILK
JP2: JUMPER-SMT_2_NC_TRACE_SILK; SMT-JUMPER_2_NC_TRACE_SILK
JP7, JP8, JP13, JP14: FIDUCIAL1X2; FIDUCIAL-1X2
JP9, JP10, JP11, JP12: STAND-OFF
L1: 2.2uH; 0806
LOGO2: SFE_LOGO_FLAME.3_INCH; SFE_LOGO_FLAME_.3
LOGO4: OSHW-LOGOMINI; OSHW-LOGO-MINI
MEAS: JUMPER-SMT_2_NC_TRACE_SILK; SMT-JUMPER_2_NC_TRACE_SILK
Q1: 5.8A/30V/35mΩ; SOT23-3
Q2, Q3, Q6: 20V/4.2A/52mΩ/1.4W; SOT23-3
Q4: 600mA/40V; SOT23-3
R1: 330; 0402-TIGHT
R2, R3, R12, R16, R21, R25, R29: 1k; 0402-TIGHT
R4, R20: 5.1k; 0402-TIGHT
R5, R14, R17, R19, R22, R23, R30: 10K; 0402-TIGHT
R6: 12k; 0603
R7: 30.1k; 0603
R8: 100k; 0603
R9: 0.015ohm; 0603
R10, R11: 100; 0402-TIGHT
R13, R28: 2.0K; 0402-TIGHT
R15: 3.3K; 0402-TIGHT
R24: 20k; 0603
R31: 20k; 0402-TIGHT
RX0, RX1: TEST-POINT3X5; PAD.03X.05
SAFEBOOT: TEST-POINT3X5; PAD.03X.05
SC1+, SC1-, SC2+, SC2-: CONN_01PTH_NO_SILK_YES_STOP; 1X01_NO_SILK
TX0, TX1: TEST-POINT3X5; PAD.03X.05
U1: CH340E_MSOP10; MSOP10
U2: LTC3225EDDB; DFN300X200-10L
U3: ADM4210_1TSOT6; TSOT6
U4: u-blox_ZOE_M8Q-0-10; UBLOX_ZOE_M8-0-10
U5: AS179-92LF; SOT65P220X100-6N
U6: MS8607-02BA01
U9: MCP73831; SOT23-5
U10: 3.3V; SOT23-5
U11: 74LVC1G04SE; SOT353
U12: 74LVC1G08W5-7; SOT23-5
VIN/3: TEST-POINT3X5; PAD.03X.05
X2: 32.768kHz; CRYSTAL-SMD-3.2X1.5MM

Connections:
3.3V: C1.1, C2.1, C7.1, C12.1, C25.1, C27.1, C28.1, D7.A, D11.A, D13.A, Q2.2 (S), Q6.2 (S), R1.2, R8.2, R12.2, R17.2, R19.2, U1.7 (VCC), U1.10 (V3), U2.6 (VSEL), U2.9 (VIN), U6.1 (VDD), U10.5 (OUT), U11.5 (P$V+), U12.5 (P$V+); also elsewhere on the board
3V3SW: 3V3SW.1, C13.1, Q2.3 (D), R16.2, U4.24 (VCC), U4.25 (VCC), U12.1 (A)
ANTENNA: C16.1, J7.SIG (SIGNAL)
ARTEMIS_!RESET: U4.20 (!RESET); also elsewhere on the board
ARTEMIS_!RTS!: U1.4 (!RTS); also elsewhere on the board
ARTEMIS_D8_SCL: U4.32 (SCL/CLK), U6.8 (SCL); also elsewhere on the board
ARTEMIS_D9_SDA: U4.2 (SDA/CS), U6.7 (SDA); also elsewhere on the board
ARTEMIS_D10: U4.50 (P1014); also elsewhere on the board
ARTEMIS_D13: R23.1, R24.2, VIN/3.1; also elsewhere on the board
ARTEMIS_D17: D17.1, J1.5 (ON/!OFF!); also elsewhere on the board
ARTEMIS_D18: J1.19 (NET_AVAIL); also elsewhere on the board
ARTEMIS_D19: R21.2; also elsewhere on the board
ARTEMIS_D22: R14.1, U3.3 (ON); also elsewhere on the board
ARTEMIS_D24: J1.6 (TX(IN)), TX1.1; also elsewhere on the board
ARTEMIS_D25: J1.7 (RX(OUT)), RX1.1; also elsewhere on the board
ARTEMIS_D26: Q2.1 (G), R17.1; also elsewhere on the board
ARTEMIS_D27: R5.2, U2.4 (~SHDN); also elsewhere on the board
ARTEMIS_D28: D2.C, R8.1, U2.5 (PGOOD); also elsewhere on the board
ARTEMIS_D34: R25.1, R30.1; also elsewhere on the board
ARTEMIS_D41: D41.1, J1.12 (RING_INDICATOR); also elsewhere on the board
ARTEMIS_D44: Q6.1 (G), R19.1; also elsewhere on the board
ARTEMIS_RX0: R2.1, RX0.1, U1.8 (TXO); also elsewhere on the board
ARTEMIS_TX0: R3.1, TX0.1, U1.9 (RXI); also elsewhere on the board
CC3: J2.B5 (CC2), R4.2
CC4: J2.A5 (CC1), R20.2
D+2: J2.A6 (D+), J2.B6 (D+), U1.1 (UD+)
D-2: J2.A7 (D-), J2.B7 (D-), U1.2 (UD-)
EXT_PWR: 5V3.1, J1.1 (EXT_PWR_1), J1.2 (EXT_PWR_2), Q1.2 (S), R13.2, U5.4 (V1), U11.2 (A)
GND: B1.-, C1.2, C2.2, C4.2, C6.-, C7.2, C8.2, C9.2, C10.2, C11.2, C12.2, C13.2, C17.2, C21.2, C25.2, C27.2, C28.2, D1.C, D3.C, D4.C, D6.C, GND.1, J1.3 (EXT_GND_3), J1.4 (EXT_GND_4), J1.8 (SIG_GND_8), J1.13 (RTS), J1.14 (DTR), J1.15 (SIG_GND_15), J1.18 (SIG_GND_18), J2.GND, J2.GND2 (GND), J3.1 (-), J5.1 (-), J6.1 (GND), J6.2 (GND), J7.GND@0 (GND), J7.GND@1 (GND), J7.GND@2 (GND), J7.GND@3 (GND), J8.1, J9.1, Q4.2 (E), R4.1, R5.1, R6.1, R7.2, R14.2, R20.1, R23.2, R28.1, R30.2, R31.2, SC2-.1, U1.3 (GND), U2.8 (GND), U2.11 (GND), U3.2 (GND), U4.1 (GND), U4.3 (GND), U4.5 (GND), U4.7 (GND), U4.8 (GND), U4.9 (GND), U4.10 (GND), U4.11 (GND), U4.12 (GND), U4.17 (GND), U4.23 (GND), U4.29 (SQI_G), U4.31 (SQI_G), U4.37 (GND), U4.38 (GND), U4.39 (GND), U4.40 (GND), U4.41 (GND), U4.44 (GND), U4.46 (SQI_G), U4.47 (SQI_G), U4.49 (GND), U5.2 (GND), U6.3 (GND), U9.2 (VSS), U10.2 (GND), U11.3 (P$V-), U12.3 (P$V-); also elsewhere on the board
GNSS: C15.2, U4.4 (RF_IN)
IRIDIUM: C14.2, J6.FEED (SIGNAL)
LTC3225_VOUT: C4.1, C5.+, R9.2, SC1+.1, U2.10 (COUT), U3.6 (VCC)
unnamed: C5.-, C6.+, SC1-.1, SC2+.1, U2.3 (CX)
unnamed: JP1.3, R6.2
unnamed: JP2.2, R1.1
unnamed: JP1.1, R7.1
unnamed: D2.A, R12.1
unnamed: D3.A, R13.1
unnamed: D5.A, Q6.3 (D)
unnamed: Q1.3 (D), R9.1, U3.5 (SENSE)
unnamed: C3.2, U2.2 (C-)
unnamed: C3.1, U2.1 (C+)
unnamed: JP1.2, U2.7 (PROG)
unnamed: Q1.1 (G), R10.1
unnamed: R10.2, R11.1, U3.4 (GATE)
unnamed: C9.1, R11.2
unnamed: C10.1, U3.1 (TIMER)
unnamed: L1.2, U4.26 (V_DCDC_OUT)
unnamed: C11.1, L1.1, U4.27 (V_CORE)
unnamed: U4.18 (RTC_0), X2.P$2 (2)
unnamed: U4.19 (RTC_1), X2.P$1 (1)
unnamed: D5.C, R15.2
unnamed: D4.A, R16.1
unnamed: D13.C, R2.2
unnamed: D1.A, JP2.1
unnamed: D11.C, D12.C, U4.16 (V_BCKP)
unnamed: SAFEBOOT.1, U4.34 (!SAFEBOOT)
unnamed: GPS_RX.1, U4.22 (RXD/MOSI)
unnamed: GPS_TX.1, U4.21 (TXD/MISO)
unnamed: C14.1, U5.1 (J3)
unnamed: C15.1, U5.3 (J2)
unnamed: C16.2, U5.5 (J1)
unnamed: R31.1, U5.6 (V2), U12.4 (Y)
unnamed: D7.C, R3.2
unnamed: U11.4 (Y), U12.2 (B)
unnamed: D6.A, R21.1
unnamed: 3V3EN.2, EN.1, U10.3 (EN)
unnamed: Q3.1 (G), Q4.3 (C), R22.1
unnamed: R28.2, U9.5 (PROG)
unnamed: D9.C, R29.2
unnamed: R29.1, U9.1 (STAT)
unnamed: Q3.3 (D), R24.1
unnamed: Q4.1 (B), R25.2
VBUS: D8.C, D10.C, D14.C, J4.2, MEAS.1
VIN: 3V3EN.1, C21.1, J4.1, MEAS.2, Q3.2 (S), R22.2, U10.1 (IN)
V_AAA: D10.A, J3.2 (+)
V_BATT: C8.1, D8.A, J5.2 (+), U9.3 (VBAT)
V_BCKP: B1.+, D12.A, R15.1
V_USB: C17.1, D9.A, D14.A, J2.VBUS1 (VBUS), J2.VBUS2 (VBUS), U9.4 (VIN)

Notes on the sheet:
Paul Clark (Based on the SparkFun Artemis and Qwiic ZOE-M8Q)
Power
+5.3V
150mA
60mA
Pads for extra 10F supercaps
Super-capacitor Charger
Charging
9603N_PWR
Iridium 9603N
LEDs
Inrush Current Limit
GPS Power
u-blox ZOE-M8Q-0-10
VCC Range: 2.7 - 3.6V
I2C Address: 0x42
V_BCKP 1.8V Min
Back-Up Battery And charge control switch
SII ML414H 1.0mAh (3.1V-2.0V) 600Ω Pb-free reflowable Charge: Constant Current / Constant Voltage 3.1V, max.30μA, 72hr, RT
Nexperia PMEG4005EJ VF @ 100uA = ~100mV
R15 = (3.3 - (3.1 + 0.1)) / 30E-6 = ~3.3K
GPS Power Switch
Antenna Switch
** !! Make sure 3V3SW and EXT_PWR are not enabled simultaneously !! **
A good choice for the antenna is the Maxtena M1600HCT-P-SMA which is tuned for Iridium, GPS and GLONASS
For a 1.55mm PCB, 50 Ohm antenna traces should be 32 mil with 4 mil gap
Pressure, Humidity & Temperature Sensor
VDD Range: 1.5 - 3.6V
I2C Addresses: Pressure & Temperature: 0x76 Relative Humidity: 0x40
USB-to-Serial Converter
3.3V @ 600mA Iq = 50uA
USB/LiPo Charger
Charge rate set to 500mA
Power Source Select
Open jumper to switch or measure power
Connector for solar power or 3 x AA/AAA 6V Max
Bus Voltage Measurement
Revised by: Pete Lewis
VIN: 6V MAX
3.3V Voltage Regulator

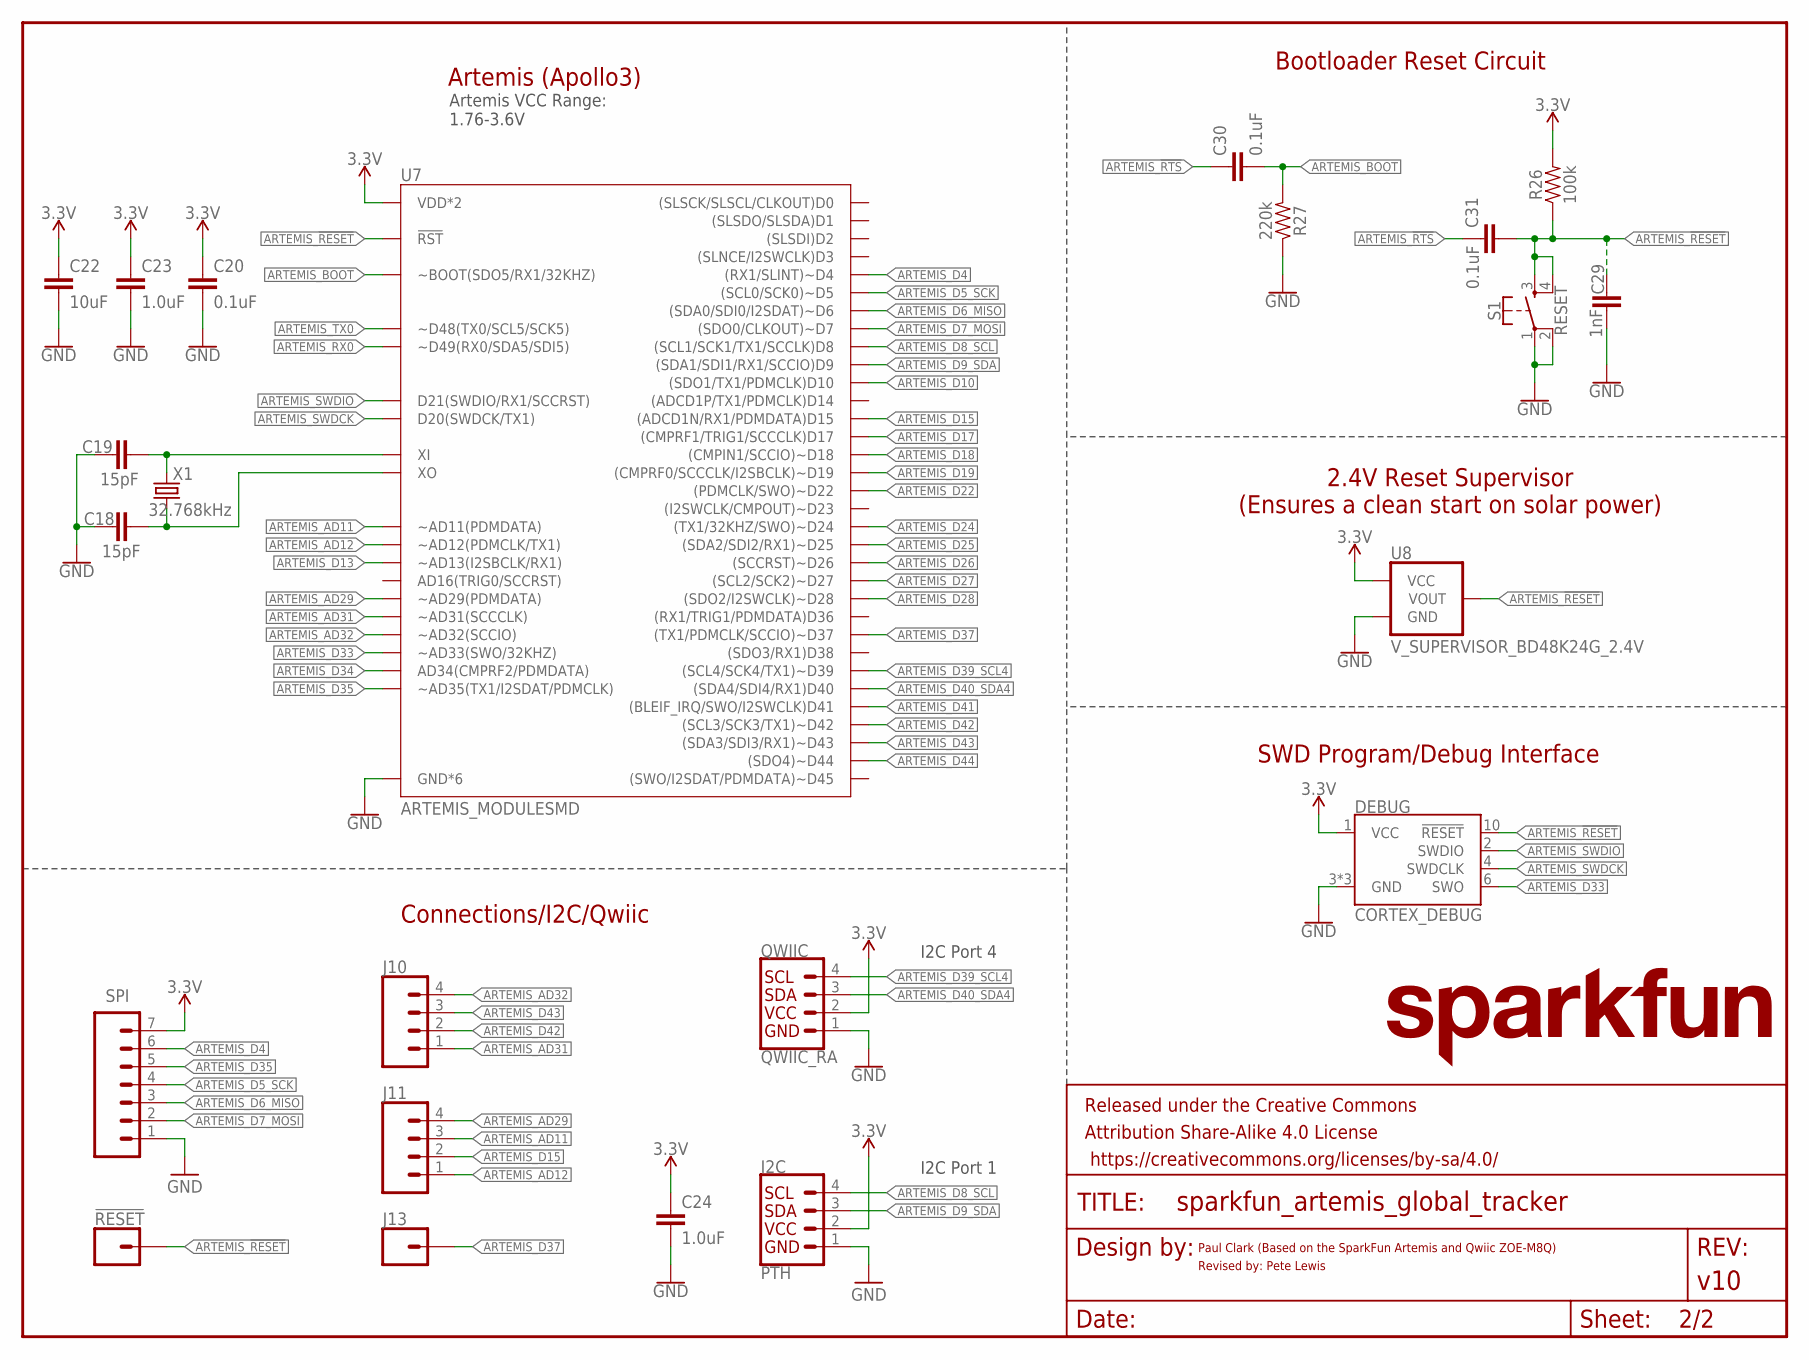
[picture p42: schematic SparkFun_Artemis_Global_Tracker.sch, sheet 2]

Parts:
!RESET: CONN_01PTH_NO_SILK_YES_STOP; 1X01_NO_SILK
C18, C19: 15pF; 0603
C20, C30, C31: 0.1uF; 0603
C22: 10uF; 0603
C23, C24: 1.0uF; 0603
C29: 1nF; 0603
DEBUG: CORTEX_DEBUG; 2X5-PTH-1.27MM-NO_SILK
FRAME3: FRAME-LETTERNO_PACKAGE; DUMMY
I2C: PTH; 1X04_NO_SILK
J10, J11: CONN_041X04_NO_SILK_NO_POP; 1X04_NO_SILK
J13: CONN_01PTH_NO_SILK_YES_STOP; 1X01_NO_SILK
LOGO1: SFE_LOGO_NAME.1_INCH; SFE_LOGO_NAME_.1
QWIIC: QWIIC_RA; JST04_1MM_RA
R26: 100k; 0603
R27: 220k; 0603
S1: RESET; TACTILE_SWITCH_SMD_5.2MM
SPI: CONN_07NO_SILK; 1X07_NO_SILK
U7: ARTEMIS_MODULESMD; ARTEMIS_FP
U8: V_SUPERVISOR_BD48K24G_2.4V; SOT23-3
X1: 32.768kHz; CRYSTAL-SMD-3.2X1.5MM

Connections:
3.3V: C20.2, C22.1, C23.1, C24.1, DEBUG.1 (VCC), I2C.2, QWIIC.2, R26.2, SPI.7, U7.VDD@36 (VDD*2), U7.VDD@37 (VDD*2), U8.3 (VCC); also elsewhere on the board
ARTEMIS_!RESET: !RESET.1, C29.1, C31.2, DEBUG.10 (!RESET), R26.1, S1.3, S1.4, U7.~RST (!RST), U8.2 (VOUT); also elsewhere on the board
ARTEMIS_!RTS!: C30.1, C31.1; also elsewhere on the board
ARTEMIS_AD11: J11.3, U7.~AD11 (~AD11(PDMDATA))
ARTEMIS_AD12: J11.1, U7.~AD12 (~AD12(PDMCLK/TX1))
ARTEMIS_AD29: J11.4, U7.~AD29 (~AD29(PDMDATA))
ARTEMIS_AD31: J10.1, U7.~AD31 (~AD31(SCCCLK))
ARTEMIS_AD32: J10.4, U7.~AD32 (~AD32(SCCIO))
ARTEMIS_BOOT: C30.2, R27.2, U7.BOOT (~BOOT(SDO5/RX1/32KHZ))
ARTEMIS_D4: SPI.6, U7.~D4 ((RX1/SLINT)~D4)
ARTEMIS_D5_SCK: SPI.4, U7.~D5 ((SCL0/SCK0)~D5)
ARTEMIS_D6_MISO: SPI.3, U7.~D6 ((SDA0/SDI0/I2SDAT)~D6)
ARTEMIS_D7_MOSI: SPI.2, U7.D7 ((SDO0/CLKOUT)~D7)
ARTEMIS_D8_SCL: I2C.4, U7.D8 ((SCL1/SCK1/TX1/SCCLK)D8); also elsewhere on the board
ARTEMIS_D9_SDA: I2C.3, U7.D9 ((SDA1/SDI1/RX1/SCCIO)D9); also elsewhere on the board
ARTEMIS_D10: U7.D10 ((SDO1/TX1/PDMCLK)D10); also elsewhere on the board
ARTEMIS_D13: U7.~AD13 (~AD13(I2SBCLK/RX1)); also elsewhere on the board
ARTEMIS_D15: J11.2, U7.D15 ((ADCD1N/RX1/PDMDATA)D15)
ARTEMIS_D17: U7.D17 ((CMPRF1/TRIG1/SCCCLK)D17); also elsewhere on the board
ARTEMIS_D18: U7.~D18 ((CMPIN1/SCCIO)~D18); also elsewhere on the board
ARTEMIS_D19: U7.~D19 ((CMPRF0/SCCCLK/I2SBCLK)~D19); also elsewhere on the board
ARTEMIS_D22: U7.~D22 ((PDMCLK/SWO)~D22); also elsewhere on the board
ARTEMIS_D24: U7.~D24 ((TX1/32KHZ/SWO)~D24); also elsewhere on the board
ARTEMIS_D25: U7.~D25 ((SDA2/SDI2/RX1)~D25); also elsewhere on the board
ARTEMIS_D26: U7.~D26 ((SCCRST)~D26); also elsewhere on the board
ARTEMIS_D27: U7.~D27 ((SCL2/SCK2)~D27); also elsewhere on the board
ARTEMIS_D28: U7.~D28 ((SDO2/I2SWCLK)~D28); also elsewhere on the board
ARTEMIS_D33: DEBUG.6 (SWO), U7.~AD33/SWO (~AD33(SWO/32KHZ))
ARTEMIS_D34: U7.AD34 (AD34(CMPRF2/PDMDATA)); also elsewhere on the board
ARTEMIS_D35: SPI.5, U7.~AD35 (~AD35(TX1/I2SDAT/PDMCLK))
ARTEMIS_D37: J13.1, U7.~D37 ((TX1/PDMCLK/SCCIO)~D37)
ARTEMIS_D39_SCL4: QWIIC.4, U7.~D39 ((SCL4/SCK4/TX1)~D39)
ARTEMIS_D40_SDA4: QWIIC.3, U7.D40 ((SDA4/SDI4/RX1)D40)
ARTEMIS_D41: U7.D41 ((BLEIF_IRQ/SWO/I2SWCLK)D41); also elsewhere on the board
ARTEMIS_D42: J10.2, U7.~D42 ((SCL3/SCK3/TX1)~D42)
ARTEMIS_D43: J10.3, U7.~D43 ((SDA3/SDI3/RX1)~D43)
ARTEMIS_D44: U7.~D44 ((SDO4)~D44); also elsewhere on the board
ARTEMIS_RX0: U7.RXI-0 (~D49(RX0/SDA5/SDI5)); also elsewhere on the board
ARTEMIS_SWDCK: DEBUG.4 (SWDCLK), U7.SWDCK (D20(SWDCK/TX1))
ARTEMIS_SWDIO: DEBUG.2 (SWDIO), U7.SWDIO (D21(SWDIO/RX1/SCCRST))
ARTEMIS_TX0: U7.TXO-0 (~D48(TX0/SCL5/SCK5)); also elsewhere on the board
GND: C18.1, C19.1, C20.1, C22.2, C23.2, C24.2, C29.2, DEBUG.3 (GND), DEBUG.5 (GND), DEBUG.9 (GND), I2C.1, QWIIC.1, R27.1, S1.1, S1.2, SPI.1, U7.GND@1 (GND*6), U7.GND@22 (GND*6), U7.GND@38 (GND*6), U7.GND@39 (GND*6), U7.GND@47 (GND*6), U7.GND@59 (GND*6), U8.1 (GND); also elsewhere on the board
XTALI: C19.2, U7.XI, X1.P$1 (1)
XTALO: C18.2, U7.XO, X1.P$2 (2)

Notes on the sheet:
Artemis (Apollo3)
Artemis VCC Range: 1.76-3.6V
Bootloader Reset Circuit
SWD Program/Debug Interface
Connections/I2C/Qwiic
I2C Port 1
I2C Port 4
2.4V Reset Supervisor (Ensures a clean start on solar power)
Paul Clark (Based on the SparkFun Artemis and Qwiic ZOE-M8Q)
Revised by: Pete Lewis

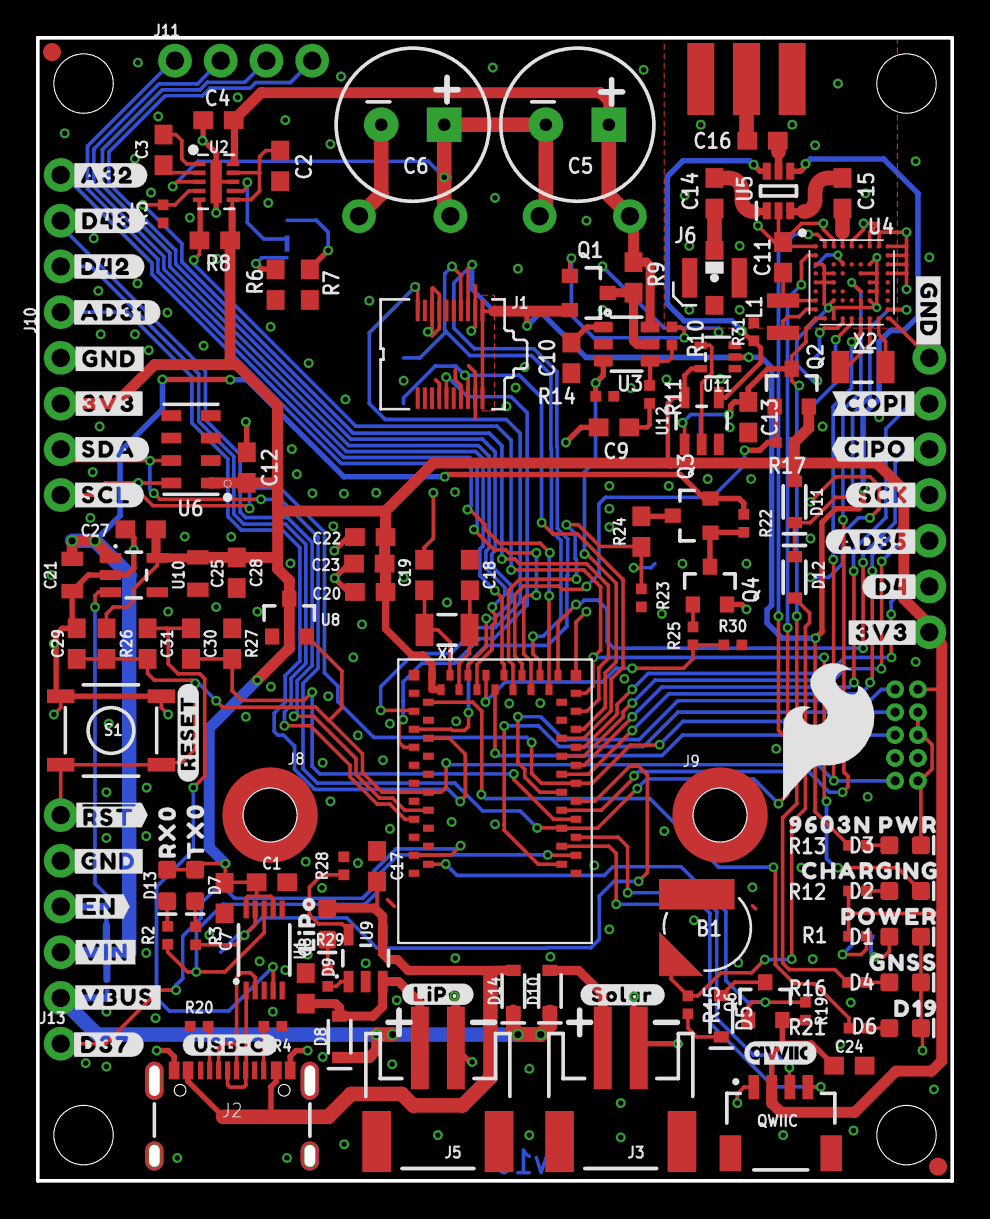
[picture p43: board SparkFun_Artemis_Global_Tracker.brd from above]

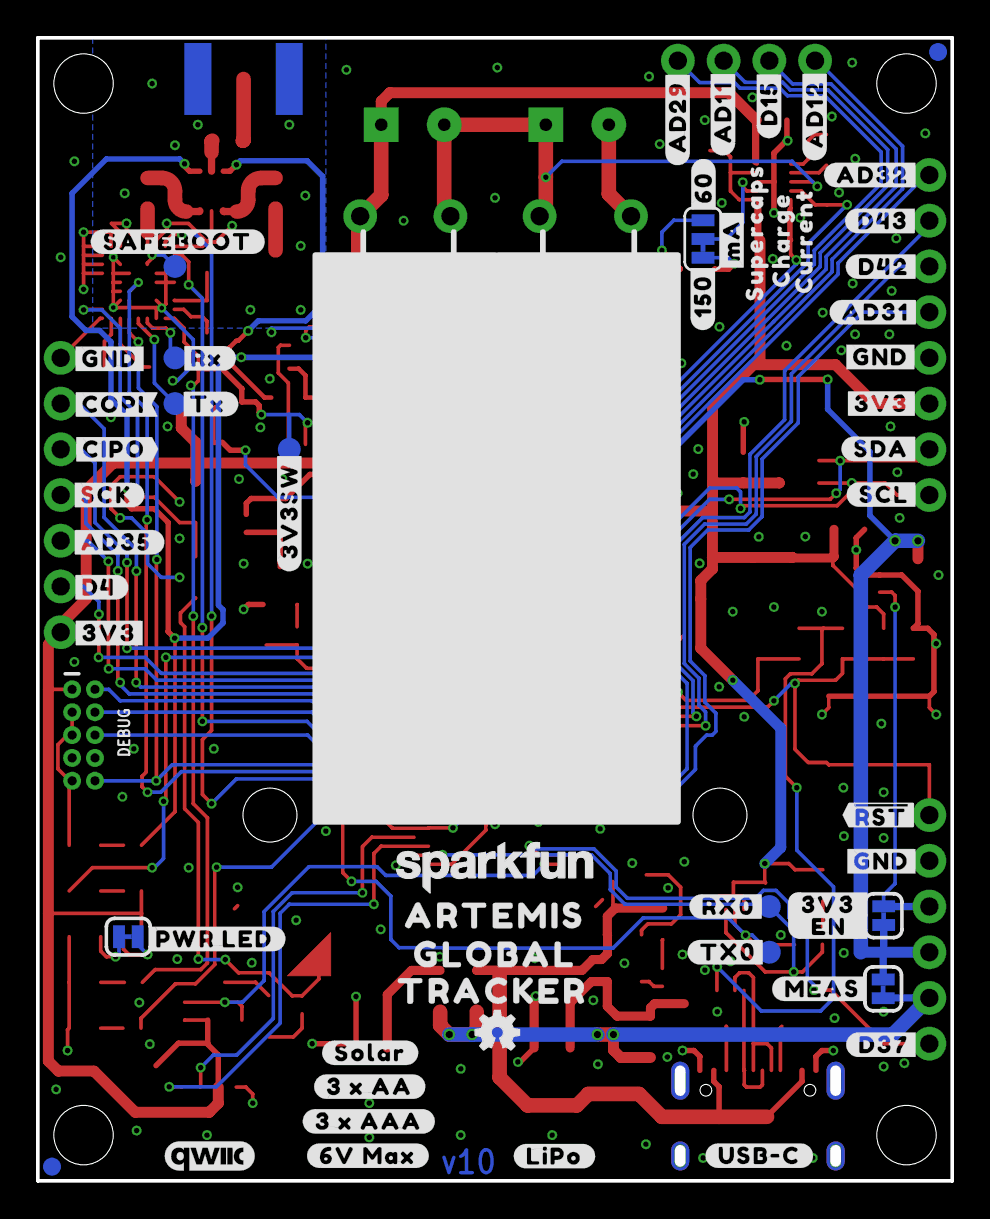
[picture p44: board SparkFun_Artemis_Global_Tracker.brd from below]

Board: 2 copper layers, 50.8 x 63.5 mm, 240 parts (79 on the bottom side), 101 nets.

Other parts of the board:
U$1, U$13: SUPERCAPACITOR151
U$2: #SCK#199608
U$3, U$43: #3V3#0
U$4: #SDA#0
U$5: #USB#C#0
U$6: #SCL#0
U$7: #VIN#158
U$8: #3V3SW#0
U$9: CHARGING9604
U$10: #COPI#9694
U$11: QWIIC_4MM
U$12: LIPO5
U$14, U$15: 10F_2#7V152
U$16: RX06
U$17, U$70: #3V3#153
U$18: TX07
U$19: #AD35#199609
U$20, U$36: #GND#0
U$21: #SDA#153
U$22: #SCL#154
U$24: #AD31#7
U$25: QWIIC_5MM
U$26: #_RST##156
U$27: #EN#157
U$28: #VIN#3#0
U$29: #AD35#0
U$30: ARTEMIS0
U$31: SUPERCAPS6
U$32: #D17#0
U$33: #SAFEBOOT#0
U$34: #TX0#0
U$35: #TX1#0
U$37: #RX#0
U$38: #RX1#0
U$39: #TX#0
U$40: #5#3V#0
U$41: #D41#0
U$42: #RX0#0
U$44: #RESET#162
U$45: #SOLAR#165
U$46: #LIPO#164
U$47: #MEAS#0
U$48: #3V3_#0
U$50: #D4#36
U$51: GLOBAL0
U$52: TRACKER0
U$53: #LIPO#0
U$54: #_EN_#0
U$55: #SOLAR#0
U$56: #USB#C#161
U$57: #3_X_AA#0
U$58: #VBUS#159
U$59: #AD32#152
U$60: #SCK#9696
U$61: #PWR_LED#0
U$63: #D4#5
U$64: #CIPO#2
U$65: #3_X_AAA#0
U$66: #6V_MAX#0
U$67: CHARGE8
U$69: CURRENT9
U$71: #D42#32
U$72: #D37#152
U$73: #D43#43
U$74: #150#61
U$75: #COPI#5
U$76, U$77, U$78: #GND#152
U$79: #A32#44
U$80: #MA#45
U$81: #60#46
U$82: #D43#151
U$83: #D42#151
U$84: #AD31#151
U$85: #AD12#151
U$86: #D15#151
U$87: #AD11#151
U$88: #AD29#151
U$89: #CIPO#151
U$90: #D37#0
U$91: #GND#38
U$92: ##RST##39
U$93: 9603N_PWR40
U$94: POWER9605
U$95: GNSS9606
U$96: D199607

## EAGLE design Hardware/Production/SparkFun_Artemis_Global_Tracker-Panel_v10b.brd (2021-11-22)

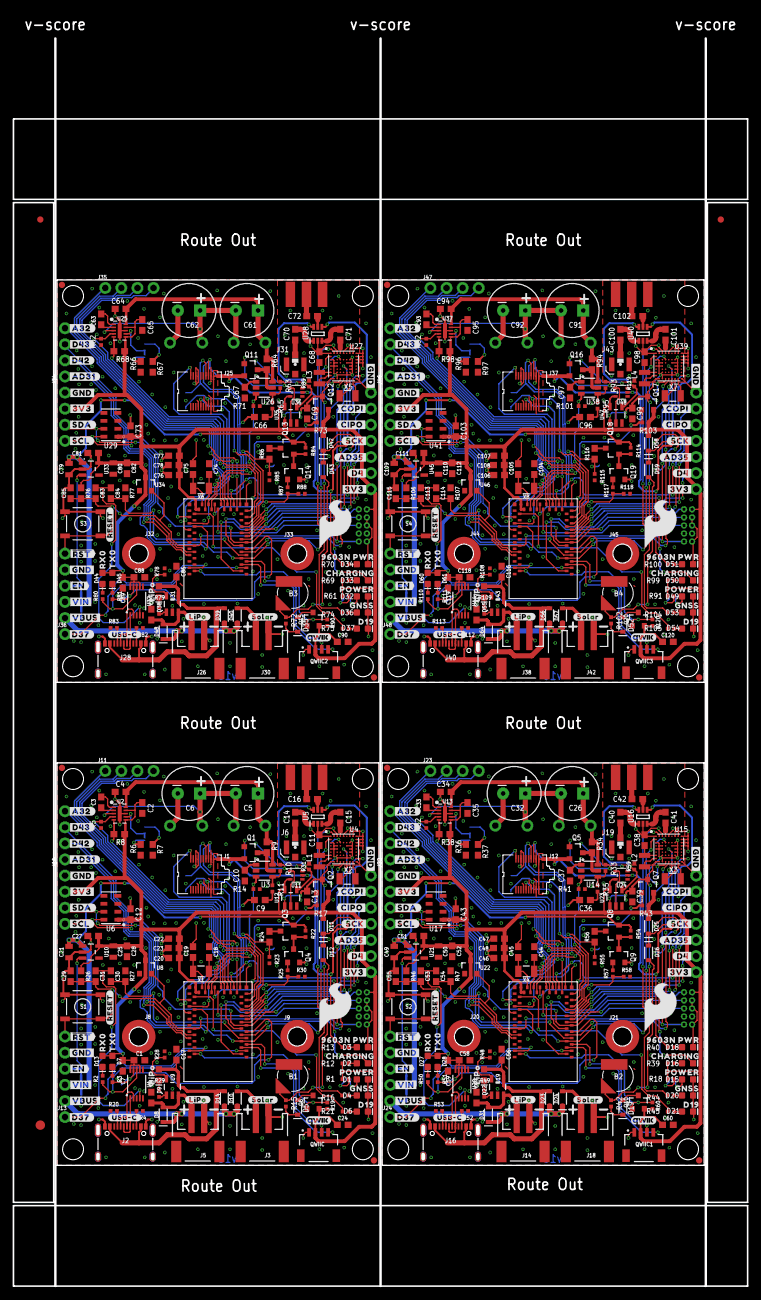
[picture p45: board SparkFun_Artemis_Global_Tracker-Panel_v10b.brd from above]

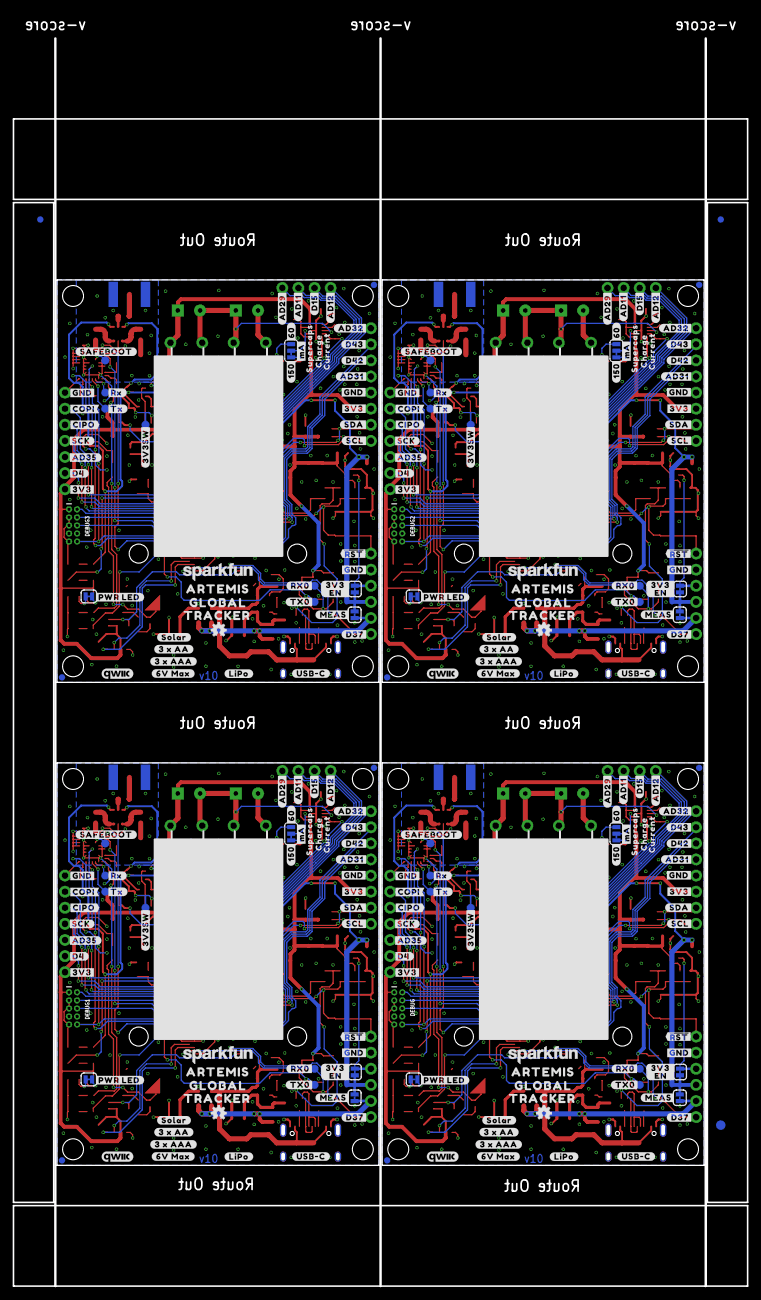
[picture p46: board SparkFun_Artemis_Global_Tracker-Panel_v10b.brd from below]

Board: 2 copper layers, 115.8 x 196.9 mm, 958 parts (319 on the bottom side), 404 nets.

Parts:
3V3EN, 3V3EN1, 3V3EN2, 3V3EN3: JUMPER-SMT_2_NC_TRACE_SILK; SMT-JUMPER_2_NC_TRACE_SILK
3V3SW, 3V3SW1, 3V3SW2, 3V3SW3: PAD.03X.05
5V1, 5V2, 5V3, 5V4: TEST-POINT3X5; PAD.03X.05
!RESET, !RESET1, !RESET2, !RESET3: 1X01_NO_SILK
B1, B2, B3, B4: ML414H_IV01E_BATTERY; ML414H_IV01E
C1, C9, C36, C58, C66, C88, C96, C118: 10nF; 0603
C2, C35, C65, C95: 2.2uF; 0603
C3, C10, C23, C24, C27, C33, C37, C48, C51, C60, C63, C67, C78, C81, C90, C93, C97, C108, C111, C120: 1.0uF; 0603
C4, C12, C34, C43, C64, C73, C94, C103: 0.22uF; 0603
C5, C6, C26, C32, C61, C62, C91, C92: 1F 2.7V; CPOL-RADIAL-1F-2.7V
C7, C13, C20, C28, C30, C31, C39, C46, C52, C53, C54, C59, C69, C76, C82, C83, C84, C89, C99, C106, C112, C113, C114, C119: 0.1uF; 0603
C8, C11, C17, C38, C56, C57, C68, C86, C87, C98, C116, C117: 4.7uF; 0603
C14, C15, C16, C40, C41, C42, C70, C71, C72, C100, C101, C102: 100pF; 0603
C18, C19, C44, C45, C74, C75, C104, C105: 15pF; 0603
C21, C25, C49, C50, C79, C80, C109, C110: 22uF; 0805
C22, C47, C77, C107: 10uF; 0603
C29, C55, C85, C115: 1nF; 0603
D1, D7, D15, D28, D32, D45, D49, D61: GREEN; LED-0603
D2, D9, D13, D16, D22, D27, D33, D38, D44, D50, D55, D60: Yellow; LED-0603
D3, D18, D34, D51: RED; LED-0603
D4, D20, D36, D53: BLUE; LED-0603
D5, D8, D10, D11, D12, D14, D19, D23, D24, D25, D26, D31, D35, D39, D40, D42, D43, D48, D52, D56, D57, D58, D59, D64: 0.5A/40V/420mV; SOD-323
D6, D21, D37, D54: WHITE; LED-0603
D17, D29, D30, D41, D46, D47, D62, D63: PAD.03X.05
DEBUG, DEBUG1, DEBUG2, DEBUG3: CORTEX_DEBUG; 2X5-PTH-1.27MM-NO_SILK
E$1, E$2, E$3, E$4: FIDUCIAL-1X2
E$5, E$6: FIDUCIAL-1.5X3
EN, EN1, EN2, EN3: 1X01_NO_SILK
GND, GND1, GND2, GND3: 1X01_NO_SILK
GPS_RX, GPS_RX1, GPS_RX2, GPS_RX3: TEST-POINT3X5; PAD.03X.05
GPS_TX, GPS_TX1, GPS_TX2, GPS_TX3: TEST-POINT3X5; PAD.03X.05
I2C, I2C1, I2C2, I2C3: PTH; 1X04_NO_SILK
J1, J12, J25, J37: IRIDIUM_9603N
J2, J16, J28, J40: USB-C; USB-C-16P-2LAYER-PADS
J3, J5, J14, J18, J26, J30, J38, J42: JST-2-SMD
J4, J15, J27, J39: 1X02_NO_SILK
J6, J19, J31, J43: U.FL
J7, J17, J29, J41: ANTENNA-GROUNDEDEDGE_SMA; SMA-EDGE
J8, J9, J20, J21, J32, J33, J44, J45: STAND-OFF-REFLOW-M2.0_6.0MM_TALL; STAND-OFF-REFLOW-M2.0
J10, J11, J22, J23, J34, J35, J46, J47: 1X04_NO_SILK
J13, J24, J36, J48: 1X01_NO_SILK
JP1, JP15, JP25, JP35: JUMPER-SMT_3_1-NC_TRACE_SILK; SMT-JUMPER_3_1-NC_TRACE_SILK
JP2, JP16, JP26, JP36: JUMPER-SMT_2_NC_TRACE_SILK; SMT-JUMPER_2_NC_TRACE_SILK
JP3, JP4, JP5, JP6, JP7, JP8, JP13, JP14, JP21, JP22, JP23, JP24, JP31, JP32, JP33, JP34: FIDUCIAL1X2; FIDUCIAL-1X2
JP9, JP10, JP11, JP12, JP17, JP18, JP19, JP20, JP27, JP28, JP29, JP30, JP37, JP38, JP39, JP40: STAND-OFF
L1, L2, L3, L4: 2.2uH; 0806
LOGO1, LOGO5, LOGO8, LOGO11: SFE_LOGO_NAME.1_INCH; SFE_LOGO_NAME_.1
LOGO2, LOGO6, LOGO9, LOGO12: SFE_LOGO_FLAME.3_INCH; SFE_LOGO_FLAME_.3
LOGO3, LOGO4, LOGO7, LOGO10: OSHW-LOGOMINI; OSHW-LOGO-MINI
MEAS, MEAS1, MEAS2, MEAS3: JUMPER-SMT_2_NC_TRACE_SILK; SMT-JUMPER_2_NC_TRACE_SILK
Q1, Q5, Q11, Q16: 5.8A/30V/35mΩ; SOT23-3
Q2, Q3, Q6, Q7, Q8, Q10, Q12, Q13, Q15, Q17, Q18, Q20: 20V/4.2A/52mΩ/1.4W; SOT23-3
Q4, Q9, Q14, Q19: 600mA/40V; SOT23-3
QWIIC, QWIIC1, QWIIC2, QWIIC3: QWIIC_RA; JST04_1MM_RA
R1, R18, R61, R91: 330; 0402-TIGHT
R2, R3, R12, R16, R21, R25, R29, R39, R44, R45, R49, R50, R51, R57, R69, R74, R75, R79, R80, R81, R87, R99, R104, R105, R109, R110, R111, R117: 1k; 0402-TIGHT
R4, R20, R52, R53, R82, R83, R112, R113: 5.1k; 0402-TIGHT
R5, R14, R17, R19, R22, R23, R30, R32, R41, R43, R54, R55, R58, R60, R62, R71, R73, R84, R85, R88, R90, R92, R101, R103, R114, R115, R118, R120: 10K; 0402-TIGHT
R6, R36, R66, R96: 12k; 0603
R7, R37, R67, R97: 30.1k; 0603
R8, R26, R38, R46, R68, R76, R98, R106: 100k; 0603
R9, R34, R64, R94: 0.015ohm; 0603
R10, R11, R33, R35, R63, R65, R93, R95: 100; 0402-TIGHT
R13, R28, R40, R48, R70, R78, R100, R108: 2.0K; 0402-TIGHT
R15, R42, R72, R102: 3.3K; 0402-TIGHT
R24, R56, R86, R116: 20k; 0603
R27, R47, R77, R107: 220k; 0603
R31, R59, R89, R119: 20k; 0402-TIGHT
RX0, RX1, RX2, RX3, RX4, RX5, RX6, RX7: TEST-POINT3X5; PAD.03X.05
S1, S2, S3, S4: RESET; TACTILE_SWITCH_SMD_5.2MM
SAFEBOOT, SAFEBOOT1, SAFEBOOT2, SAFEBOOT3: TEST-POINT3X5; PAD.03X.05
SC1+, SC1+1, SC1+2, SC1+3, SC1-, SC1-1, SC1-2, SC1-3, SC2+, SC2+1, SC2+2, SC2+3, SC2-, SC2-1, SC2-2, SC2-3: 1X01_NO_SILK
SPI, SPI1, SPI2, SPI3: 1X07_NO_SILK
TX0, TX1, TX2, TX3, TX4, TX5, TX6, TX7: TEST-POINT3X5; PAD.03X.05
U1, U20, U32, U44: CH340E_MSOP10; MSOP10
U2, U13, U25, U37: LTC3225EDDB; DFN300X200-10L
U3, U14, U26, U38: ADM4210_1TSOT6; TSOT6
U4, U15, U27, U39: U-BLOX_ZOE_M8Q-0-10; UBLOX_ZOE_M8-0-10
U5, U16, U28, U40: AS179-92LF; SOT65P220X100-6N
U6, U17, U29, U41: MS8607-02BA01
U7, U18, U30, U42: ARTEMIS_MODULESMD; ARTEMIS_FP
U8, U22, U34, U46: V_SUPERVISOR_BD48K24G_2.4V; SOT23-3
U9, U19, U31, U43: MCP73831; SOT23-5
U10, U21, U33, U45: 3.3V; SOT23-5
U11, U24, U36, U48: 74LVC1G04SE; SOT353
U12, U23, U35, U47: 74LVC1G08W5-7; SOT23-5
U$1, U$13, U$131, U$132, U$223, U$224, U$315, U$316: SUPERCAPACITOR151
U$2, U$177, U$269, U$361: #SCK#199608
U$3, U$43, U$111, U$124, U$203, U$216, U$295, U$308: #3V3#0
U$4, U$112, U$204, U$296: #SDA#0
U$5, U$117, U$209, U$301: #USB#C#0
U$6, U$113, U$205, U$297: #SCL#0
U$7, U$143, U$235, U$327: #VIN#158
U$8, U$98, U$190, U$282: #3V3SW#0
U$9, U$173, U$265, U$357: CHARGING9604
U$10, U$149, U$241, U$333: #COPI#9694
U$11, U$23, U$185, U$277: QWIIC_4MM
U$12, U$182, U$274, U$366: LIPO5
U$14, U$15, U$133, U$134, U$225, U$226, U$317, U$318: 10F_2#7V152
U$16, U$183, U$275, U$367: RX06
U$17, U$70, U$138, U$151, U$230, U$243, U$322, U$335: #3V3#153
U$18, U$184, U$276, U$368: TX07
U$19, U$178, U$270, U$362: #AD35#199609
U$20, U$36, U$110, U$125, U$202, U$217, U$294, U$309: #GND#0
U$21, U$139, U$231, U$323: #SDA#153
U$22, U$140, U$232, U$324: #SCL#154
U$24, U$152, U$244, U$336: #AD31#7
U$25, U$49, U$186, U$278: QWIIC_5MM
U$26, U$141, U$233, U$325: #_RST##156
U$27, U$142, U$234, U$326: #EN#157
U$28, U$99, U$191, U$283: #VIN#3#0
U$29, U$179, U$271, U$363: #AD35#0
U$30, U$62, U$187, U$279: ARTEMIS0
U$31, U$128, U$220, U$312: SUPERCAPS6
U$32, U$101, U$193, U$285: #D17#0
U$33, U$109, U$201, U$293: #SAFEBOOT#0
U$34, U$104, U$196, U$288: #TX0#0
U$35, U$106, U$198, U$290: #TX1#0
U$37, U$108, U$200, U$292: #RX#0
U$38, U$105, U$197, U$289: #RX1#0
U$39, U$107, U$199, U$291: #TX#0
U$40, U$100, U$192, U$284: #5#3V#0
U$41, U$102, U$194, U$286: #D41#0
U$42, U$103, U$195, U$287: #RX0#0
U$44, U$146, U$238, U$330: #RESET#162
U$45, U$148, U$240, U$332: #SOLAR#165
U$46, U$147, U$239, U$331: #LIPO#164
U$47, U$114, U$206, U$298: #MEAS#0
U$48, U$115, U$207, U$299: #3V3_#0
U$50, U$180, U$272, U$364: #D4#36
U$51, U$68, U$188, U$280: GLOBAL0
U$52, U$97, U$189, U$281: TRACKER0
U$53, U$118, U$210, U$302: #LIPO#0
U$54, U$116, U$208, U$300: #_EN_#0
U$55, U$119, U$211, U$303: #SOLAR#0
U$56, U$145, U$237, U$329: #USB#C#161
U$57, U$120, U$212, U$304: #3_X_AA#0
U$58, U$144, U$236, U$328: #VBUS#159
U$59, U$167, U$259, U$351: #AD32#152
U$60, U$150, U$242, U$334: #SCK#9696
U$61, U$123, U$215, U$307: #PWR_LED#0
U$63, U$181, U$273, U$365: #D4#5
U$64, U$126, U$218, U$310: #CIPO#2
U$65, U$121, U$213, U$305: #3_X_AAA#0
U$66, U$122, U$214, U$306: #6V_MAX#0
U$67, U$129, U$221, U$313: CHARGE8
U$69, U$130, U$222, U$314: CURRENT9
U$71, U$153, U$245, U$337: #D42#32
U$72, U$168, U$260, U$352: #D37#152
U$73, U$154, U$246, U$338: #D43#43
U$74, U$158, U$250, U$342: #150#61
U$75, U$127, U$219, U$311: #COPI#5
U$76, U$77, U$78, U$135, U$136, U$137, U$227, U$228, U$229, U$319, U$320, U$321: #GND#152
U$79, U$155, U$247, U$339: #A32#44
U$80, U$156, U$248, U$340: #MA#45
U$81, U$157, U$249, U$341: #60#46
U$82, U$159, U$251, U$343: #D43#151
U$83, U$160, U$252, U$344: #D42#151
U$84, U$161, U$253, U$345: #AD31#151
U$85, U$162, U$254, U$346: #AD12#151
U$86, U$163, U$255, U$347: #D15#151
U$87, U$164, U$256, U$348: #AD11#151
U$88, U$165, U$257, U$349: #AD29#151
U$89, U$166, U$258, U$350: #CIPO#151
U$90, U$169, U$261, U$353: #D37#0
U$91, U$170, U$262, U$354: #GND#38
U$92, U$171, U$263, U$355: ##RST##39
U$93, U$172, U$264, U$356: 9603N_PWR40
U$94, U$174, U$266, U$358: POWER9605
U$95, U$175, U$267, U$359: GNSS9606
U$96, U$176, U$268, U$360: D199607
VIN/1, VIN/2, VIN/3, VIN/4: TEST-POINT3X5; PAD.03X.05
X1, X2, X3, X4, X5, X6, X7, X8: 32.768kHz; CRYSTAL-SMD-3.2X1.5MM

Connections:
3.3V: C1.1, C2.1, C7.1, C12.1, C20.2, C22.1, C23.1, C24.1, C25.1, C27.1, C28.1, D7.A, D11.A, D13.A, DEBUG.1, I2C.2, Q2.2, Q6.2, QWIIC.2, R1.2, R8.2, R12.2, R17.2, R19.2, R26.2, SPI.7, U1.7, U1.10, U2.6, U2.9, U6.1, U7.VDD@36, U7.VDD@37, U8.3, U10.5, U11.5, U12.5
3.3V1: C35.1, C43.1, C46.2, C47.1, C48.1, C50.1, C51.1, C52.1, C58.1, C59.1, C60.1, D25.A, D27.A, D28.A, DEBUG1.1, I2C1.2, Q7.2, Q10.2, QWIIC1.2, R18.2, R38.2, R39.2, R43.2, R46.2, R60.2, SPI1.7, U13.6, U13.9, U17.1, U18.VDD@36, U18.VDD@37, U20.7, U20.10, U21.5, U22.3, U23.5, U24.5
3.3V2: C65.1, C73.1, C76.2, C77.1, C78.1, C80.1, C81.1, C82.1, C88.1, C89.1, C90.1, D42.A, D44.A, D45.A, DEBUG2.1, I2C2.2, Q12.2, Q15.2, QWIIC2.2, R61.2, R68.2, R69.2, R73.2, R76.2, R90.2, SPI2.7, U25.6, U25.9, U29.1, U30.VDD@36, U30.VDD@37, U32.7, U32.10, U33.5, U34.3, U35.5, U36.5
3.3V3: C95.1, C103.1, C106.2, C107.1, C108.1, C110.1, C111.1, C112.1, C118.1, C119.1, C120.1, D58.A, D60.A, D61.A, DEBUG3.1, I2C3.2, Q17.2, Q20.2, QWIIC3.2, R91.2, R98.2, R99.2, R103.2, R106.2, R120.2, SPI3.7, U37.6, U37.9, U41.1, U42.VDD@36, U42.VDD@37, U44.7, U44.10, U45.5, U46.3, U47.5, U48.5
3V3SW: 3V3SW.1, C13.1, Q2.3, R16.2, U4.24, U4.25, U12.1
3V3SW1: 3V3SW1.1, C39.1, Q7.3, R44.2, U15.24, U15.25, U23.1
3V3SW2: 3V3SW2.1, C69.1, Q12.3, R74.2, U27.24, U27.25, U35.1
3V3SW3: 3V3SW3.1, C99.1, Q17.3, R104.2, U39.24, U39.25, U47.1
ANTENNA: C16.1, J7.SIG
ANTENNA1: C42.1, J17.SIG
ANTENNA2: C72.1, J29.SIG
ANTENNA3: C102.1, J41.SIG
ARTEMIS_!RESET: !RESET.1, C29.1, C31.2, DEBUG.10, R26.1, S1.3, S1.4, U4.20, U7.~RST, U8.2
ARTEMIS_!RESET1: !RESET1.1, C53.2, C55.1, DEBUG1.10, R46.1, S2.3, S2.4, U15.20, U18.~RST, U22.2
ARTEMIS_!RESET2: !RESET2.1, C83.2, C85.1, DEBUG2.10, R76.1, S3.3, S3.4, U27.20, U30.~RST, U34.2
ARTEMIS_!RESET3: !RESET3.1, C113.2, C115.1, DEBUG3.10, R106.1, S4.3, S4.4, U39.20, U42.~RST, U46.2
ARTEMIS_!RTS!: C30.1, C31.1, U1.4
ARTEMIS_!RTS!1: C53.1, C54.1, U20.4
ARTEMIS_!RTS!2: C83.1, C84.1, U32.4
ARTEMIS_!RTS!3: C113.1, C114.1, U44.4
ARTEMIS_AD1: J22.1, U18.~AD31
ARTEMIS_AD2: J23.4, U18.~AD29
ARTEMIS_AD3: J23.3, U18.~AD11
ARTEMIS_AD4: J23.1, U18.~AD12
ARTEMIS_AD5: J22.4, U18.~AD32
ARTEMIS_AD6: J34.1, U30.~AD31
ARTEMIS_AD7: J35.4, U30.~AD29
ARTEMIS_AD8: J35.3, U30.~AD11
ARTEMIS_AD9: J35.1, U30.~AD12
ARTEMIS_AD10: J34.4, U30.~AD32
ARTEMIS_AD11: J11.3, U7.~AD11
ARTEMIS_AD12: J11.1, U7.~AD12
ARTEMIS_AD13: J46.1, U42.~AD31
ARTEMIS_AD14: J47.4, U42.~AD29
ARTEMIS_AD15: J47.3, U42.~AD11
ARTEMIS_AD16: J47.1, U42.~AD12
ARTEMIS_AD17: J46.4, U42.~AD32
ARTEMIS_AD29: J11.4, U7.~AD29
ARTEMIS_AD31: J10.1, U7.~AD31
ARTEMIS_AD32: J10.4, U7.~AD32
ARTEMIS_BOOT: C30.2, R27.2, U7.BOOT
ARTEMIS_BOOT1: C54.2, R47.2, U18.BOOT
ARTEMIS_BOOT2: C84.2, R77.2, U30.BOOT
ARTEMIS_BOOT3: C114.2, R107.2, U42.BOOT
ARTEMIS_D1: DEBUG1.6, U18.~AD33/SWO
ARTEMIS_D2: SPI1.5, U18.~AD35
ARTEMIS_D3: R55.1, R56.2, U18.~AD13, VIN/1.1
ARTEMIS_D4: SPI.6, U7.~D4
ARTEMIS_D5: R45.2, U18.~D19
ARTEMIS_D5_SCK: SPI.4, U7.~D5
ARTEMIS_D5_SCK1: SPI1.4, U18.~D5
ARTEMIS_D5_SCK2: SPI2.4, U30.~D5
ARTEMIS_D5_SCK3: SPI3.4, U42.~D5
ARTEMIS_D6: J12.19, U18.~D18
ARTEMIS_D6_MISO: SPI.3, U7.~D6
ARTEMIS_D6_MISO1: SPI1.3, U18.~D6
ARTEMIS_D6_MISO2: SPI2.3, U30.~D6
ARTEMIS_D6_MISO3: SPI3.3, U42.~D6
ARTEMIS_D7: J12.7, RX3.1, U18.~D25
ARTEMIS_D7_MOSI: SPI.2, U7.D7
ARTEMIS_D7_MOSI1: SPI1.2, U18.D7
ARTEMIS_D7_MOSI2: SPI2.2, U30.D7
ARTEMIS_D7_MOSI3: SPI3.2, U42.D7
ARTEMIS_D8: R32.2, U13.4, U18.~D27
ARTEMIS_D8_SCL: I2C.4, U4.32, U6.8, U7.D8
ARTEMIS_D8_SCL1: I2C1.4, U15.32, U17.8, U18.D8
ARTEMIS_D8_SCL2: I2C2.4, U27.32, U29.8, U30.D8
ARTEMIS_D8_SCL3: I2C3.4, U39.32, U41.8, U42.D8
ARTEMIS_D9: SPI1.6, U18.~D4
ARTEMIS_D9_SDA: I2C.3, U4.2, U6.7, U7.D9
ARTEMIS_D9_SDA1: I2C1.3, U15.2, U17.7, U18.D9
ARTEMIS_D9_SDA2: I2C2.3, U27.2, U29.7, U30.D9
ARTEMIS_D9_SDA3: I2C3.3, U39.2, U41.7, U42.D9
ARTEMIS_D10: U4.50, U7.D10
ARTEMIS_D11: U15.50, U18.D10
ARTEMIS_D12: D29.1, J12.5, U18.D17
ARTEMIS_D13: R23.1, R24.2, U7.~AD13, VIN/3.1
ARTEMIS_D14: R41.1, U14.3, U18.~D22
ARTEMIS_D15: J11.2, U7.D15
ARTEMIS_D16: J12.6, TX3.1, U18.~D24
ARTEMIS_D17: D17.1, J1.5, U7.D17
ARTEMIS_D18: J1.19, U7.~D18
ARTEMIS_D19: R21.2, U7.~D19
ARTEMIS_D20: Q7.1, R43.1, U18.~D26
ARTEMIS_D21: D16.C, R38.1, U13.5, U18.~D28
ARTEMIS_D22: R14.1, U3.3, U7.~D22
ARTEMIS_D23: D30.1, J12.12, U18.D41
ARTEMIS_D24: J1.6, TX1.1, U7.~D24
ARTEMIS_D25: J1.7, RX1.1, U7.~D25
ARTEMIS_D26: Q2.1, R17.1, U7.~D26
ARTEMIS_D27: R5.2, U2.4, U7.~D27
ARTEMIS_D28: D2.C, R8.1, U2.5, U7.~D28
ARTEMIS_D29: R57.1, R58.1, U18.AD34
ARTEMIS_D30: Q10.1, R60.1, U18.~D44
ARTEMIS_D31: J22.2, U18.~D42
ARTEMIS_D32: J22.3, U18.~D43
ARTEMIS_D33: DEBUG.6, U7.~AD33/SWO
ARTEMIS_D34: R25.1, R30.1, U7.AD34
ARTEMIS_D35: SPI.5, U7.~AD35
ARTEMIS_D36: J23.2, U18.D15
ARTEMIS_D37: J13.1, U7.~D37
ARTEMIS_D38: J24.1, U18.~D37
ARTEMIS_D39: DEBUG2.6, U30.~AD33/SWO
ARTEMIS_D39_SCL1: QWIIC1.4, U18.~D39
ARTEMIS_D39_SCL2: QWIIC2.4, U30.~D39
ARTEMIS_D39_SCL3: QWIIC3.4, U42.~D39
ARTEMIS_D39_SCL4: QWIIC.4, U7.~D39
ARTEMIS_D40: SPI2.5, U30.~AD35
ARTEMIS_D40_SDA1: QWIIC1.3, U18.D40
ARTEMIS_D40_SDA2: QWIIC2.3, U30.D40
ARTEMIS_D40_SDA3: QWIIC3.3, U42.D40
ARTEMIS_D40_SDA4: QWIIC.3, U7.D40
ARTEMIS_D41: D41.1, J1.12, U7.D41
ARTEMIS_D42: J10.2, U7.~D42
ARTEMIS_D43: J10.3, U7.~D43
ARTEMIS_D44: Q6.1, R19.1, U7.~D44
ARTEMIS_D45: R85.1, R86.2, U30.~AD13, VIN/2.1
ARTEMIS_D46: R75.2, U30.~D19
ARTEMIS_D47: J25.19, U30.~D18
ARTEMIS_D48: J25.7, RX5.1, U30.~D25
ARTEMIS_D49: R62.2, U25.4, U30.~D27
ARTEMIS_D50: SPI2.6, U30.~D4
ARTEMIS_D51: U27.50, U30.D10
ARTEMIS_D52: D46.1, J25.5, U30.D17
ARTEMIS_D53: R71.1, U26.3, U30.~D22
ARTEMIS_D54: J25.6, TX5.1, U30.~D24
ARTEMIS_D55: Q12.1, R73.1, U30.~D26
ARTEMIS_D56: D33.C, R68.1, U25.5, U30.~D28
ARTEMIS_D57: D47.1, J25.12, U30.D41
ARTEMIS_D58: R87.1, R88.1, U30.AD34
ARTEMIS_D59: Q15.1, R90.1, U30.~D44
ARTEMIS_D60: J34.2, U30.~D42
ARTEMIS_D61: J34.3, U30.~D43
ARTEMIS_D62: J35.2, U30.D15
ARTEMIS_D63: J36.1, U30.~D37
ARTEMIS_D64: DEBUG3.6, U42.~AD33/SWO
ARTEMIS_D65: SPI3.5, U42.~AD35
ARTEMIS_D66: R115.1, R116.2, U42.~AD13, VIN/4.1
ARTEMIS_D67: R105.2, U42.~D19
ARTEMIS_D68: J37.19, U42.~D18
ARTEMIS_D69: J37.7, RX7.1, U42.~D25
ARTEMIS_D70: R92.2, U37.4, U42.~D27
ARTEMIS_D71: SPI3.6, U42.~D4
ARTEMIS_D72: U39.50, U42.D10
ARTEMIS_D73: D62.1, J37.5, U42.D17
ARTEMIS_D74: R101.1, U38.3, U42.~D22
ARTEMIS_D75: J37.6, TX7.1, U42.~D24
ARTEMIS_D76: Q17.1, R103.1, U42.~D26
ARTEMIS_D77: D50.C, R98.1, U37.5, U42.~D28
ARTEMIS_D78: D63.1, J37.12, U42.D41
ARTEMIS_D79: R117.1, R118.1, U42.AD34
ARTEMIS_D80: Q20.1, R120.1, U42.~D44
ARTEMIS_D81: J46.2, U42.~D42
ARTEMIS_D82: J46.3, U42.~D43
ARTEMIS_D83: J47.2, U42.D15
ARTEMIS_D84: J48.1, U42.~D37
ARTEMIS_RX0: R2.1, RX0.1, U1.8, U7.RXI-0
ARTEMIS_RX1: R50.1, RX2.1, U18.RXI-0, U20.8
ARTEMIS_RX2: R80.1, RX4.1, U30.RXI-0, U32.8
ARTEMIS_RX3: R110.1, RX6.1, U42.RXI-0, U44.8
ARTEMIS_SWDCK: DEBUG.4, U7.SWDCK
ARTEMIS_SWDCK1: DEBUG1.4, U18.SWDCK
ARTEMIS_SWDCK2: DEBUG2.4, U30.SWDCK
ARTEMIS_SWDCK3: DEBUG3.4, U42.SWDCK
ARTEMIS_SWDIO: DEBUG.2, U7.SWDIO
ARTEMIS_SWDIO1: DEBUG1.2, U18.SWDIO
ARTEMIS_SWDIO2: DEBUG2.2, U30.SWDIO
ARTEMIS_SWDIO3: DEBUG3.2, U42.SWDIO
ARTEMIS_TX0: R3.1, TX0.1, U1.9, U7.TXO-0
ARTEMIS_TX1: R51.1, TX2.1, U18.TXO-0, U20.9
ARTEMIS_TX2: R81.1, TX4.1, U30.TXO-0, U32.9
ARTEMIS_TX3: R111.1, TX6.1, U42.TXO-0, U44.9
CC1: J16.B5, R52.2
CC2: J16.A5, R53.2
CC3: J2.B5, R4.2
CC4: J2.A5, R20.2
CC5: J28.B5, R82.2
CC6: J28.A5, R83.2
CC7: J40.B5, R112.2
CC8: J40.A5, R113.2
D+1: J16.A6, J16.B6, U20.1
D+2: J2.A6, J2.B6, U1.1
D+3: J28.A6, J28.B6, U32.1
D+4: J40.A6, J40.B6, U44.1
D-1: J16.A7, J16.B7, U20.2
D-2: J2.A7, J2.B7, U1.2
D-3: J28.A7, J28.B7, U32.2
D-4: J40.A7, J40.B7, U44.2
EXT_PWR: 5V3.1, J1.1, J1.2, Q1.2, R13.2, U5.4, U11.2
EXT_PWR1: 5V1.1, J12.1, J12.2, Q5.2, R40.2, U16.4, U24.2
EXT_PWR2: 5V2.1, J25.1, J25.2, Q11.2, R70.2, U28.4, U36.2
EXT_PWR3: 5V4.1, J37.1, J37.2, Q16.2, R100.2, U40.4, U48.2
GND: B1.-, C1.2, C2.2, C4.2, C6.-, C7.2, C8.2, C9.2, C10.2, C11.2, C12.2, C13.2, C17.2, C18.1, C19.1, C20.1, C21.2, C22.2, C23.2, C24.2, C25.2, C27.2, C28.2, C29.2, D1.C, D3.C, D4.C, D6.C, DEBUG.3, DEBUG.5, DEBUG.9, GND.1, I2C.1, J1.3, J1.4, J1.8, J1.13, J1.14, J1.15, J1.18, J2.GND, J2.GND2, J3.1, J5.1, J6.1, J6.2, J7.GND@0, J7.GND@1, J7.GND@2, J7.GND@3, J8.1, J9.1, Q4.2, QWIIC.1, R4.1, R5.1, R6.1, R7.2, R14.2, R20.1, R23.2, R27.1, R28.1, R30.2, R31.2, S1.1, S1.2, SC2-.1, SPI.1, U1.3, U2.8, U2.11, U3.2, U4.1, U4.3, U4.5, U4.7, U4.8, U4.9, U4.10, U4.11, U4.12, U4.17, U4.23, U4.29, U4.31, U4.37, U4.38, U4.39, U4.40, U4.41, U4.44, U4.46, U4.47, U4.49, U5.2, U6.3, U7.GND@1, U7.GND@22, U7.GND@38, U7.GND@39, U7.GND@47, U7.GND@59, U8.1, U9.2, U10.2, U11.3, U12.3
GND1: B2.-, C32.-, C34.2, C35.2, C36.2, C37.2, C38.2, C39.2, C43.2, C44.1, C45.1, C46.1, C47.2, C48.2, C49.2, C50.2, C51.2, C52.2, C55.2, C56.2, C57.2, C58.2, C59.2, C60.2, D15.C, D18.C, D20.C, D21.C, DEBUG1.3, DEBUG1.5, DEBUG1.9, GND1.1, I2C1.1, J12.3, J12.4, J12.8, J12.13, J12.14, J12.15, J12.18, J14.1, J16.GND, J16.GND2, J17.GND@0, J17.GND@1, J17.GND@2, J17.GND@3, J18.1, J19.1, J19.2, J20.1, J21.1, Q9.2, QWIIC1.1, R32.1, R36.1, R37.2, R41.2, R47.1, R48.1, R52.1, R53.1, R55.2, R58.2, R59.2, S2.1, S2.2, SC2-1.1, SPI1.1, U13.8, U13.11, U14.2, U15.1, U15.3, U15.5, U15.7, U15.8, U15.9, U15.10, U15.11, U15.12, U15.17, U15.23, U15.29, U15.31, U15.37, U15.38, U15.39, U15.40, U15.41, U15.44, U15.46, U15.47, U15.49, U16.2, U17.3, U18.GND@1, U18.GND@22, U18.GND@38, U18.GND@39, U18.GND@47, U18.GND@59, U19.2, U20.3, U21.2, U22.1, U23.3, U24.3
GND2: B3.-, C62.-, C64.2, C65.2, C66.2, C67.2, C68.2, C69.2, C73.2, C74.1, C75.1, C76.1, C77.2, C78.2, C79.2, C80.2, C81.2, C82.2, C85.2, C86.2, C87.2, C88.2, C89.2, C90.2, D32.C, D34.C, D36.C, D37.C, DEBUG2.3, DEBUG2.5, DEBUG2.9, GND2.1, I2C2.1, J25.3, J25.4, J25.8, J25.13, J25.14, J25.15, J25.18, J26.1, J28.GND, J28.GND2, J29.GND@0, J29.GND@1, J29.GND@2, J29.GND@3, J30.1, J31.1, J31.2, J32.1, J33.1, Q14.2, QWIIC2.1, R62.1, R66.1, R67.2, R71.2, R77.1, R78.1, R82.1, R83.1, R85.2, R88.2, R89.2, S3.1, S3.2, SC2-2.1, SPI2.1, U25.8, U25.11, U26.2, U27.1, U27.3, U27.5, U27.7, U27.8, U27.9, U27.10, U27.11, U27.12, U27.17, U27.23, U27.29, U27.31, U27.37, U27.38, U27.39, U27.40, U27.41, U27.44, U27.46, U27.47, U27.49, U28.2, U29.3, U30.GND@1, U30.GND@22, U30.GND@38, U30.GND@39, U30.GND@47, U30.GND@59, U31.2, U32.3, U33.2, U34.1, U35.3, U36.3
GND3: B4.-, C92.-, C94.2, C95.2, C96.2, C97.2, C98.2, C99.2, C103.2, C104.1, C105.1, C106.1, C107.2, C108.2, C109.2, C110.2, C111.2, C112.2, C115.2, C116.2, C117.2, C118.2, C119.2, C120.2, D49.C, D51.C, D53.C, D54.C, DEBUG3.3, DEBUG3.5, DEBUG3.9, GND3.1, I2C3.1, J37.3, J37.4, J37.8, J37.13, J37.14, J37.15, J37.18, J38.1, J40.GND, J40.GND2, J41.GND@0, J41.GND@1, J41.GND@2, J41.GND@3, J42.1, J43.1, J43.2, J44.1, J45.1, Q19.2, QWIIC3.1, R92.1, R96.1, R97.2, R101.2, R107.1, R108.1, R112.1, R113.1, R115.2, R118.2, R119.2, S4.1, S4.2, SC2-3.1, SPI3.1, U37.8, U37.11, U38.2, U39.1, U39.3, U39.5, U39.7, U39.8, U39.9, U39.10, U39.11, U39.12, U39.17, U39.23, U39.29, U39.31, U39.37, U39.38, U39.39, U39.40, U39.41, U39.44, U39.46, U39.47, U39.49, U40.2, U41.3, U42.GND@1, U42.GND@22, U42.GND@38, U42.GND@39, U42.GND@47, U42.GND@59, U43.2, U44.3, U45.2, U46.1, U47.3, U48.3
GNSS: C15.2, U4.4
GNSS1: C41.2, U15.4
GNSS2: C71.2, U27.4
GNSS3: C101.2, U39.4
IRIDIUM: C14.2, J6.FEED
IRIDIUM1: C40.2, J19.FEED
IRIDIUM2: C70.2, J31.FEED
IRIDIUM3: C100.2, J43.FEED
LTC3225_VOUT: C4.1, C5.+, R9.2, SC1+.1, U2.10, U3.6
LTC3225_VOUT1: C26.+, C34.1, R34.2, SC1+1.1, U13.10, U14.6
LTC3225_VOUT2: C61.+, C64.1, R64.2, SC1+2.1, U25.10, U26.6
LTC3225_VOUT3: C91.+, C94.1, R94.2, SC1+3.1, U37.10, U38.6
unnamed: C5.-, C6.+, SC1-.1, SC2+.1, U2.3
unnamed: JP1.3, R6.2
unnamed: JP2.2, R1.1
unnamed: JP1.1, R7.1
unnamed: D2.A, R12.1
unnamed: D3.A, R13.1
unnamed: D5.A, Q6.3
unnamed: Q1.3, R9.1, U3.5
unnamed: C3.2, U2.2
unnamed: C3.1, U2.1
unnamed: JP1.2, U2.7
unnamed: Q1.1, R10.1
unnamed: R10.2, R11.1, U3.4
unnamed: C9.1, R11.2
unnamed: C10.1, U3.1
unnamed: L1.2, U4.26
unnamed: C11.1, L1.1, U4.27
unnamed: U4.18, X2.P$2
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

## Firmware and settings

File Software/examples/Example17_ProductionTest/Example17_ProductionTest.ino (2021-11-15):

/*
 Artemis Global Tracker
 Production Test Code
 
 ** Requires the Artemis Global Tracker Test Header **

 Written by Paul Clark (PaulZC)
 21st July 2020

 ** Set the Board to "SparkFun Artemis Module" **

 This code tests each component on the AGT.
 The Iridium 9603N connections are tested using the AGT Test Header.
 
 _Before_ connecting the USB-C cable:
 carefully insert the test header into the Samtec socket;
 secure the test header with at least one screw;
 connect the Qwiic socket on the test header to the Qwiic socket
 on the AGT using a short Qwiic cable.

 Helpful messages will appear in the Serial Monitor (115200 Baud) as the test progresses.

 You will need to install the Qwiic_PHT_MS8607_Library before this example
 will run successfully:
 https://github.com/sparkfun/SparkFun_PHT_MS8607_Arduino_Library
 (Search for MS8607 in the Library Manager)

 You will need to install the SparkFun u-blox library before this example
 will run successfully:
 https://github.com/sparkfun/SparkFun_Ublox_Arduino_Library

 Version History:
 V1.1: 21st July 2020
   Added the RTC test (Test 6)
 V1.0: 7th June 2020
   First release

*/

// Uncomment the "#define noFail" to allow the test to continue even though it has failed
// (Beware: doing this could kill an Artemis I/O pin if it is shorted to ground!)
//#define noFail

// Artemis Tracker pin definitions
#define spiCS1              4  // D4 can be used as an SPI chip select or as a general purpose IO pin
#define geofencePin         10 // Input for the ZOE-M8Q's PIO14 (geofence) pin
#define busVoltagePin       13 // Bus voltage divided by 3 (Analog in)
#define iridiumSleep        17 // Iridium 9603N ON/OFF (sleep) pin: pull high to enable the 9603N
#define iridiumNA           18 // Input for the Iridium 9603N Network Available
#define LED                 19 // White LED
#define iridiumPwrEN        22 // ADM4210 ON: pull high to enable power for the Iridium 9603N
#define gnssEN              26 // GNSS Enable: pull low to enable power for the GNSS (via Q2)
#define gnssBckpBatChgEN    44 // GNSS backup battery charge enable; when set as INPUT = disabled, when OUTPUT+LOW = charging.
#define superCapChgEN       27 // LTC3225 super capacitor charger: pull high to enable the super capacitor charger
#define superCapPGOOD       28 // Input for the LTC3225 super capacitor charger PGOOD signal
#define busVoltageMonEN     34 // Bus voltage monitor enable: pull high to enable bus voltage monitoring (via Q4 and Q3)
#define spiCS2              35 // D35 can be used as an SPI chip select or as a general purpose IO pin
#define iridiumRI           41 // Input for the Iridium 9603N Ring Indicator
#define iridiumTx           25 // The Iridium 9603N Tx pin (RX_OUT) (Serial1 Rx)
#define iridiumRx           24 // The Iridium 9603N Rx pin (TX_IN) (Serial1 Tx)
// Make sure you do not have gnssEN and iridiumPwrEN enabled at the same time!
// If you do, bad things might happen to the AS179 RF switch!

// Define the bit masks for the IO pin states (for command 0x55)
#define ON_OFF_BIT_MASK 0x1000
#define RX_OUT_BIT_MASK 0x0800
#define DCD_BIT_MASK 0x0400
#define CTS_BIT_MASK 0x0200
#define RTS_BIT_MASK 0x0100
#define RES_17_BIT_MASK 0x0080
#define NA_BIT_MASK 0x0040
#define TX_IN_BIT_MASK 0x0020
#define DSR_BIT_MASK 0x0010
#define RI_BIT_MASK 0x0008
#define DTR_BIT_MASK 0x0004
#define RES_16_BIT_MASK 0x0002
#define SUPPLY_BIT_MASK 0x0001

#include <Wire.h>
TwoWire testWire(D40,D39); //Will use Artemis pads 39/40 to talk to the AGT Test Header

const byte PIN_AGTWIRE_SCL = D8;
const byte PIN_AGTWIRE_SDA = D9;
TwoWire agtWire(PIN_AGTWIRE_SDA, PIN_AGTWIRE_SCL); //Create an I2C port using pads 8 (SCL) and 9 (SDA)

#include <SparkFun_PHT_MS8607_Arduino_Library.h> //http://librarymanager/All#SparkFun_PHT_MS8607

//Create an instance of the MS8607 object
//The on-board MS8607 is connected to I2C Port 1 (agtWire): SCL = D8; SDA = D9
MS8607 barometricSensor;

#include "SparkFun_u-blox_GNSS_Arduino_Library.h" //http://librarymanager/All#SparkFun_u-blox_GNSS
//The ZOE-M8Q shares I2C Port 1 (agtWire) with the MS8607: SCL = D8; SDA = D9
SFE_UBLOX_GNSS myGPS;

//Globals
bool testFailed = false; // Flag to show if the test failed (but might have continued anyway if noFail is defined)
volatile bool geofenceFlag = false; // Flag to show if the geofence pin has changed state

// geofencePin Interrupt Service Routine
// (Always keep ISRs as short as possible, don't do anything clever in them,
//  and always use volatile variables if the main loop needs to access them too.)
void geofenceISR(void)
{
  geofenceFlag = true; // Update the flag
}

// Define how often to wake up in SECONDS during Test 6
unsigned long INTERVAL = 5;

// Use this to keep track of the second alarms from the RTC
volatile unsigned long seconds_count = 0;

// This flag indicates an interval alarm has occurred
volatile bool interval_alarm = false;

// Loop Steps - these are used by the switch/case in Test 6
#define loop_init     0
#define send_time_1   1
#define zzz           2
#define wake          3
#define send_time_2   4
#define done          5
int loop_step = loop_init; // Make sure loop_step is set to loop_init

// Set up the RTC and generate interrupts every second
void setupRTC()
{
  // Enable the XT for the RTC.
  am_hal_clkgen_control(AM_HAL_CLKGEN_CONTROL_XTAL_START, 0);
  
  // Select XT for RTC clock source
  am_hal_rtc_osc_select(AM_HAL_RTC_OSC_XT);
  
  // Enable the RTC.
  am_hal_rtc_osc_enable();
  
  // Set the alarm interval to 1 second
  am_hal_rtc_alarm_interval_set(AM_HAL_RTC_ALM_RPT_SEC);
  
  // Clear the RTC alarm interrupt.
  am_hal_rtc_int_clear(AM_HAL_RTC_INT_ALM);
  
  // Enable the RTC alarm interrupt.
  am_hal_rtc_int_enable(AM_HAL_RTC_INT_ALM);
  
  // Enable RTC interrupts to the NVIC.
  NVIC_EnableIRQ(RTC_IRQn);

  // Enable interrupts to the core.
  am_hal_interrupt_master_enable();
}

// RTC alarm Interrupt Service Routine
// Clear the interrupt flag and increment seconds_count
// If INTERVAL has been reached, set the interval_alarm flag and reset seconds_count
// (Always keep ISRs as short as possible, don't do anything clever in them,
//  and always use volatile variables if the main loop needs to access them too.)
extern "C" void am_rtc_isr(void)
{
  // Clear the RTC alarm interrupt.
  am_hal_rtc_int_clear(AM_HAL_RTC_INT_ALM);

  // Increment seconds_count
  seconds_count = seconds_count + 1;

  // Check if interval_alarm should be set
  if (seconds_count >= INTERVAL)
  {
    interval_alarm = true;
    seconds_count = 0;
  }
}

void gnssON(void) // Enable power for the GNSS
{
  digitalWrite(gnssEN, LOW); // Disable GNSS power (HIGH = disable; LOW = enable)
  pinMode(gnssEN, OUTPUT); // Configure the pin which enables power for the ZOE-M8Q GNSS
}

void gnssOFF(void) // Disable power for the GNSS
{
  pinMode(gnssEN, INPUT_PULLUP); // Configure the pin which enables power for the ZOE-M8Q GNSS
  digitalWrite(gnssEN, HIGH); // Disable GNSS power (HIGH = disable; LOW = enable)
}

void setup()
{
  // Configure the I/O pins
  pinMode(LED, OUTPUT);

  pinMode(iridiumPwrEN, OUTPUT); // Configure the Iridium Power Pin (connected to the ADM4210 ON pin)
  digitalWrite(iridiumPwrEN, LOW); // Disable Iridium Power
  pinMode(superCapChgEN, OUTPUT); // Configure the super capacitor charger enable pin (connected to LTC3225 !SHDN)
  digitalWrite(superCapChgEN, LOW); // Disable the super capacitor charger
  
  gnssOFF(); // Disable power for the GNSS
  pinMode(gnssBckpBatChgEN, INPUT); // GNSS backup batttery charge control; input = disable charging; output+low=charging. 
  pinMode(geofencePin, INPUT); // Configure the geofence pin as an input
  attachInterrupt(digitalPinToInterrupt(geofencePin), geofenceISR, CHANGE); // Call geofenceISR whenever geofencePin changes state

  pinMode(iridiumSleep, INPUT_PULLUP); // Iridium 9603N On/Off (Sleep) pin
  pinMode(iridiumRI, INPUT_PULLUP); // Configure the Iridium Ring Indicator as an input
  pinMode(iridiumNA, INPUT_PULLUP); // Configure the Iridium Network Available as an input
  pinMode(iridiumTx, INPUT_PULLUP); // Configure the pin connected to the Iridium 9603N Tx (RX_OUT)
  pinMode(iridiumRx, INPUT_PULLUP); // Configure the pin connected to the Iridium 9603N Rx (TX_IN)
  pinMode(superCapPGOOD, INPUT); // Configure the super capacitor charger PGOOD input

  pinMode(busVoltageMonEN, OUTPUT); // Make the Bus Voltage Monitor Enable an output
  digitalWrite(busVoltageMonEN, HIGH); // Enable the bus voltage monitor
  analogReadResolution(14); //Set resolution to 14 bit

  // Set up the I2C pins for the test header
  testWire.begin();

  // Set up the I2C pins for the MS8607
  agtWire.begin();
  agtWire.setClock(100000); // Use 100kHz for best performance
  setAGTWirePullups(0); // Remove the pull-ups from the I2C pins (internal to the Artemis) for best performance

  // Start the console serial port
  Serial.begin(115200);

  // Comment the next two lines if you want the code to start automatically
  // - without needing to open the Serial Monitor.
  // The OK LED on the test header will indicate if the test was successful.
  while (!Serial) // Wait for the user to open the serial monitor
    ;

  delay(100);
  Serial.println();
  Serial.println();
  Serial.println(F("Artemis Global Tracker"));
  Serial.println(F("Production Test"));
  Serial.println();
  Serial.println(F("Please make sure the AGT Test Header is connected before running this test"));
  Serial.println();

  //empty the serial buffer
  while(Serial.available() > 0)
    Serial.read();

  //wait for the user to press any key before beginning
  Serial.println(F("Please check that the Serial Monitor is set to 115200 Baud"));
  Serial.println(F("and that the line ending is set to Newline."));
  Serial.println(F("Then click Send to start the test."));
  Serial.println();
  while(Serial.available() == 0)
    ;

  //turn the green LED on the test header off
  testWire.beginTransmission(0x63);
  testWire.write(0x22); // 0x22 turns the LED off
  testWire.endTransmission();

// -----------------------------------------------------------------------
// Test 1 - check the bus voltage and VCC
// -----------------------------------------------------------------------

  float busV = ((float)analogRead(busVoltagePin)) * 3.0 * 1.09 * 2.0 / 16384.0;
  Serial.print(F("Test 1 Step 1: The bus voltage is: "));
  Serial.print(busV, 2);
  Serial.println(F("V"));

  if (busV < 4.25)
  {
    Serial.println(F("Test 1 Step 1: The bus voltage is too low!"));
    fail();
  }
  if (busV > 5.25)
  {
    Serial.println(F("Test 1 Step 1: The bus voltage is too high!"));
    fail();
  }

  int div3 = analogReadVCCDiv3(); //Read VCC across a 1/3 resistor divider
  float vcc = (float)div3 * 3.0 * 2.0 / 16384.0; //Convert 1/3 VCC to VCC
  Serial.print(F("Test 1 Step 2: VCC is: "));
  Serial.print(vcc, 2);
  Serial.println(F("V"));

  if (vcc < 3.1)
  {
    Serial.println(F("Test 1 Step 2: VCC is too low!"));
    fail();
  }
  if (vcc > 3.5)
  {
    Serial.println(F("Test 1 Step 2: VCC is too high!"));
    fail();
  }

  int vss = analogReadVSS(); //Read internal VSS (should be 0)
  Serial.print(F("Test 1 Step 3: VSS: "));
  Serial.print(vss);
  Serial.println();

  if (vss > 100)
  {
    Serial.println(F("Test 1 Step 3: VSS is too high!"));
    fail();
  }

  if (testFailed == false)
  {
    Serial.println(F("Test 1: Passed"));
  }

// -----------------------------------------------------------------------
// Test 2 - check the on-board MS8607
// -----------------------------------------------------------------------

  if (barometricSensor.begin(agtWire) == false)
  {
    Serial.println(F("Test 2 Step 1: MS8607 sensor did not respond. Trying again..."));
    if (barometricSensor.begin(agtWire) == false)
    {
      Serial.println(F("Test 2 Step 1: MS8607 sensor did not respond (2nd attempt)!"));
      fail();
    }
  }

  float temperature = barometricSensor.getTemperature();
  float pressure = barometricSensor.getPressure();
  float humidity = barometricSensor.getHumidity();

  Serial.print(F("Test 2 Step 2: Temperature="));
  Serial.print(temperature, 1);
  Serial.println(F("(C)"));

  if (temperature < 10.0)
  {
    Serial.println(F("Test 2 Step 2: Temperature is too low!"));
    fail();
  }
  if (temperature > 30.0)
  {
    Serial.println(F("Test 2 Step 2: Temperature is too high!"));
    fail();
  }

  Serial.print(F("Test 2 Step 3: Pressure="));
  Serial.print(pressure, 3);
  Serial.println(F("(hPa or mbar)"));

  if (pressure < 750.0)
  {
    Serial.println(F("Test 2 Step 3: Pressure is too low!"));
    fail();
  }
  if (pressure > 1080.0)
  {
    Serial.println(F("Test 2 Step 3: Pressure is too high!"));
    fail();
  }

  Serial.print(F("Test 2 Step 4: Humidity="));
  Serial.print(humidity, 1);
  Serial.println(F("(%RH)"));

  if (humidity < 10.0)
  {
    Serial.println(F("Test 2 Step 4: Humidity is too low!"));
    fail();
  }
  if (humidity > 90.0)
  {
    Serial.println(F("Test 2 Step 4: Humidity is too high!"));
    fail();
  }

  if (testFailed == false)
  {
    Serial.println(F("Test 2: Passed"));
  }
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
void loop()
{
}

// Read the state of the IO pins from the AGT Test Header.
// Returns a uint16_t:
// Bit 12      : ON_OFF
// Bit 11      : RX_OUT
// Bit 10      : DCD
// Bit 9       : CTS
// Bit 8       : RTS
// Bit 7       : RES_17
// Bit 6       : NA
// Bit 5       : TX_IN
// Bit 4       : DSR
// Bit 3       : RI
// Bit 2       : DTR
// Bit 1       : RES_16
// Bit 0 (LSB) : SUPPLY
uint16_t readTestHeaderPins()
{
  uint16_t retVal = 0; // Use this to store the return value
  
  testWire.beginTransmission(0x63);
  testWire.write(0x55); // 0x55 reads the IO pins
  testWire.endTransmission(false);
  testWire.requestFrom(0x63, 2); // Read two bytes
  
  if (testWire.available() >= 2) // Read the I2C bytes
  {
    uint8_t lsb = testWire.read(); // IO pins data is little endian
    uint8_t msb = testWire.read();
    retVal = (((uint16_t)msb) << 8) | ((uint16_t)lsb);
  }
  
  while (testWire.available())
  {
    testWire.read(); // Mop up any unexpected bytes (hopefully redundant!)
  }

  return (retVal);
}

float readTestHeaderPWR1()
{
  float retVal = 0.0; // Use this to store the return value
  uint16_t deciVolts = 0; // Use this to store the voltage in Volts * 10^-2
  
  testWire.beginTransmission(0x63);
  testWire.write(0x33); // 0x33 reads the PWR_1 voltage
  testWire.endTransmission(false);
  testWire.requestFrom(0x63, 2); // Read two bytes
  
  if (testWire.available() >= 2) // Read the I2C bytes
  {
    uint8_t lsb = testWire.read(); // Voltage data is little endian
    uint8_t msb = testWire.read();
    deciVolts = (((uint16_t)msb) << 8) | ((uint16_t)lsb);
  }
  
  while (testWire.available())
  {
    testWire.read(); // Mop up any unexpected bytes (hopefully redundant!)
  }

  retVal = ((float)deciVolts) / 100.0; // Convert to Volts
  
  return (retVal);
}

float readTestHeaderPWR2()
{
  float retVal = 0.0; // Use this to store the return value
  uint16_t deciVolts = 0; // Use this to store the voltage in Volts * 10^-2
  
  testWire.beginTransmission(0x63);
  testWire.write(0x44); // 0x44 reads the PWR_2 voltage
  testWire.endTransmission(false);
  testWire.requestFrom(0x63, 2); // Read two bytes
  
  if (testWire.available() >= 2) // Read the I2C bytes
  {
    uint8_t lsb = testWire.read(); // Voltage data is little endian
    uint8_t msb = testWire.read();
    deciVolts = (((uint16_t)msb) << 8) | ((uint16_t)lsb);
  }
  
  while (testWire.available())
  {
    testWire.read(); // Mop up any unexpected bytes (hopefully redundant!)
  }

  retVal = ((float)deciVolts) / 100.0; // Convert to Volts
  
  return (retVal);
}

void fail() // Stop the test
{
  Serial.println(F("!!! TEST FAILED! !!!"));
  testFailed = true;
#ifdef noFail
  return;
#else  
  while(1)
    ; // Do nothing more
#endif
}


void setAGTWirePullups(uint32_t i2cBusPullUps)
{
  //Change SCL and SDA pull-ups manually using pin_config
  am_hal_gpio_pincfg_t sclPinCfg = g_AM_BSP_GPIO_IOM1_SCL;
  am_hal_gpio_pincfg_t sdaPinCfg = g_AM_BSP_GPIO_IOM1_SDA;

  if (i2cBusPullUps == 0)
  {
    sclPinCfg.ePullup = AM_HAL_GPIO_PIN_PULLUP_NONE; // No pull-ups
    sdaPinCfg.ePullup = AM_HAL_GPIO_PIN_PULLUP_NONE;
  }
  else if (i2cBusPullUps == 1)
  {
    sclPinCfg.ePullup = AM_HAL_GPIO_PIN_PULLUP_1_5K; // Use 1K5 pull-ups
    sdaPinCfg.ePullup = AM_HAL_GPIO_PIN_PULLUP_1_5K;
  }
  else if (i2cBusPullUps == 6)
  {
    sclPinCfg.ePullup = AM_HAL_GPIO_PIN_PULLUP_6K; // Use 6K pull-ups
    sdaPinCfg.ePullup = AM_HAL_GPIO_PIN_PULLUP_6K;
  }
  else if (i2cBusPullUps == 12)
  {
    sclPinCfg.ePullup = AM_HAL_GPIO_PIN_PULLUP_12K; // Use 12K pull-ups
    sdaPinCfg.ePullup = AM_HAL_GPIO_PIN_PULLUP_12K;
  }
  else
  {
    sclPinCfg.ePullup = AM_HAL_GPIO_PIN_PULLUP_24K; // Use 24K pull-ups
    sdaPinCfg.ePullup = AM_HAL_GPIO_PIN_PULLUP_24K;
  }

  pin_config(PinName(PIN_AGTWIRE_SCL), sclPinCfg);
  pin_config(PinName(PIN_AGTWIRE_SDA), sdaPinCfg);
}

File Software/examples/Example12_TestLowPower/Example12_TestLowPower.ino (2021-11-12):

/*
  Artemis Global Tracker
  Example: Test Low Power
  
  Written by Paul Clark (PaulZC)
  August 7th 2021

  ** Updated for v2.1.0 of the Apollo3 core / Artemis board package **

  ** Set the Board to "RedBoard Artemis ATP" **

  This example test the Artemis low power mode and in particular:
  tests that millis is still running afterwards; checks the RTC;
  and let's us figure out what we need to do when waking from sleep
  to put the Flash, RAM and clock speeds back to normal.

  It is also how we discover that millis gets corrupted somehow
  when going into or coming out of deep sleep. It is probably
  something to do with having to configure the stimer but I
  haven't found the root cause yet.

  It is also how we discover that pressing the Reset switch
  does _not_ reset the RTC. Nice!
  
  This example is based extensively on the Apollo3 Example6_Low_Power_Alarm
  
  SparkFun labored with love to create this code. Feel like supporting open source hardware?
  Buy a board from SparkFun!

  Version history:
  August 7th 2021
    Update for Apollo3 v2.1 using the powerDown code from OpenLog Artemis v2
  December 15th, 2020:
    Adding the deep sleep code from OpenLog Artemis.
    Keep RAM powered up during sleep to prevent corruption above 64K.
    Restore busVoltagePin (Analog in) after deep sleep.
  January 30th, 2020:
    Original release

*/

// Artemis Tracker pin definitions
#define spiCS1              4  // D4 can be used as an SPI chip select or as a general purpose IO pin
#define geofencePin         10 // Input for the ZOE-M8Q's PIO14 (geofence) pin
#define busVoltagePin       13 // Bus voltage divided by 3 (Analog in)
#define iridiumSleep        17 // Iridium 9603N ON/OFF (sleep) pin: pull high to enable the 9603N
#define iridiumNA           18 // Input for the Iridium 9603N Network Available
#define LED                 19 // White LED
#define iridiumPwrEN        22 // ADM4210 ON: pull high to enable power for the Iridium 9603N
#define gnssEN              26 // GNSS Enable: pull low to enable power for the GNSS (via Q2)
#define gnssBckpBatChgEN    44 // GNSS backup battery charge enable; when set as INPUT = disabled, when OUTPUT+LOW = charging.
#define superCapChgEN       27 // LTC3225 super capacitor charger: pull high to enable the super capacitor charger
#define superCapPGOOD       28 // Input for the LTC3225 super capacitor charger PGOOD signal
#define busVoltageMonEN     34 // Bus voltage monitor enable: pull high to enable bus voltage monitoring (via Q4 and Q3)
#define spiCS2              35 // D35 can be used as an SPI chip select or as a general purpose IO pin
#define iridiumRI           41 // Input for the Iridium 9603N Ring Indicator
// Make sure you do not have gnssEN and iridiumPwrEN enabled at the same time!
// If you do, bad things might happen to the AS179 RF switch!

#include "RTC.h" //Include RTC library included with the Arduino_Apollo3 core

// Define how often to wake up in SECONDS
unsigned long INTERVAL = 15;

// Use this to keep track of the second alarms from the RTC
volatile unsigned long seconds_count = 0;

// This flag indicates an interval alarm has occurred
volatile bool interval_alarm = false;

// Loop Steps - these are used by the switch/case in the main loop
typedef enum {
  loop_init = 0,
  send_time,
  zzz,
  wakeUp
} loop_steps;
loop_steps loop_step = loop_init; // Make sure loop_step is set to loop_init

// RTC alarm Interrupt Service Routine
// Clear the interrupt flag and increment seconds_count
// If INTERVAL has been reached, set the interval_alarm flag and reset seconds_count
// (Always keep ISRs as short as possible, don't do anything clever in them,
//  and always use volatile variables if the main loop needs to access them too.)
extern "C" void am_rtc_isr(void)
{
  // Clear the RTC alarm interrupt
  rtc.clearInterrupt();

  // Increment seconds_count
  seconds_count = seconds_count + 1;

  // Check if interval_alarm should be set
  if (seconds_count >= INTERVAL)
  {
    interval_alarm = true;
    seconds_count = 0;
  }
}

void gnssON(void) // Enable power for the GNSS
{
  am_hal_gpio_pincfg_t pinCfg = g_AM_HAL_GPIO_OUTPUT; // Begin by making the gnssEN pin an open-drain output
  pinCfg.eGPOutcfg = AM_HAL_GPIO_PIN_OUTCFG_OPENDRAIN;
  pin_config(PinName(gnssEN), pinCfg);
  delay(1);
  
  digitalWrite(gnssEN, LOW); // Enable GNSS power (HIGH = disable; LOW = enable)
}

void gnssOFF(void) // Disable power for the GNSS
{
  am_hal_gpio_pincfg_t pinCfg = g_AM_HAL_GPIO_OUTPUT; // Begin by making the gnssEN pin an open-drain output
  pinCfg.eGPOutcfg = AM_HAL_GPIO_PIN_OUTCFG_OPENDRAIN;
  pin_config(PinName(gnssEN), pinCfg);
  delay(1);
  
  digitalWrite(gnssEN, HIGH); // Disable GNSS power (HIGH = disable; LOW = enable)
}
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

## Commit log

2021-09-13 Logos swapped for SFE, proposed antenna switch logic circuit in SCH
    [SparkFun_Artemis_Global_Tracker.brd, SparkFun_Artemis_Global_Tracker.sch]
2021-09-13 swapping names of U11 and U12 to avoid confusion
    [SparkFun_Artemis_Global_Tracker.brd, SparkFun_Artemis_Global_Tracker.sch]
2021-09-13 removed voltage divider (logic shift) from inverter to AND gate.
    The AND gate is 5.5V tolerant, so we don't need to shift logic level
    [SparkFun_Artemis_Global_Tracker.brd, SparkFun_Artemis_Global_Tracker.sch]
2021-09-13 powering U11 from 3.3V
    [SparkFun_Artemis_Global_Tracker.brd, SparkFun_Artemis_Global_Tracker.sch]
2021-09-13 schematic tightening and moving most to first sheet
    [SparkFun_Artemis_Global_Tracker.brd, SparkFun_Artemis_Global_Tracker.sch]
2021-09-15 antenna switch circuit added in
    -added antenna switch protection circuit.
    -a few parts moved to 0402 packages to make room
    [SparkFun_Artemis_Global_Tracker.brd, SparkFun_Artemis_Global_Tracker.sch]
2021-09-16 Switched D8 to a P-CH MOSFET
    [SparkFun_Artemis_Global_Tracker.brd, SparkFun_Artemis_Global_Tracker.sch]
2021-09-16 schematic cleanup/tightening
    [SparkFun_Artemis_Global_Tracker.brd, SparkFun_Artemis_Global_Tracker.sch]
2021-09-16 silk updates almost done
    [SparkFun_Artemis_Global_Tracker.brd, SparkFun_Artemis_Global_Tracker.sch]
2021-09-16 silk updates and R1 to 330 for brighter green power led
    [SparkFun_Artemis_Global_Tracker.brd, SparkFun_Artemis_Global_Tracker.sch]
2021-09-17 backup battery charge resistor val and switch
    -added pch mosfet to switch backup battery charging on and off via GPIO on artemis
    -changed backup battery charge source to 3.3V rail, and changed charge resistor to 3.3K
    -Moved Iridium module and artemis module down 0.1 inch to allow more clearance around sam-tech connector so epoxy is less likely to flow over/into nearby additional supercap pth pads.
    -moved a few other components from 0603 to 0402 to make more room.
    [SparkFun_Artemis_Global_Tracker.brd, SparkFun_Artemis_Global_Tracker.sch]
2021-09-22 Reverted back to battery input diode
    [SparkFun_Artemis_Global_Tracker.brd, SparkFun_Artemis_Global_Tracker.sch]
2021-09-22 Moved all 0.1uF caps to higher spec'd part
    [SparkFun_Artemis_Global_Tracker.brd, SparkFun_Artemis_Global_Tracker.sch]
2021-09-22 Moved all 1.0uF caps to higher spec'd part
    [SparkFun_Artemis_Global_Tracker.brd, SparkFun_Artemis_Global_Tracker.sch]
2021-09-22 Moved C25 to 0805 higher voltage rating
    -to decrease BOM diversity
    [SparkFun_Artemis_Global_Tracker.brd, SparkFun_Artemis_Global_Tracker.sch]
2021-09-23 Routed 8 more Artemis GPIOs to PTH headers
    -routed AD32, D43, D42, AD31, AD29, AD11, D15 and AD12 to 0.1" PTH headers on upper right edge of board.
    -removed full size sparkfun logo, added large flame.
    [SparkFun_Artemis_Global_Tracker.brd, SparkFun_Artemis_Global_Tracker.sch]
2021-09-23 Broke out D37 to bottom right corner PTH header
    [SparkFun_Artemis_Global_Tracker.brd, SparkFun_Artemis_Global_Tracker.sch]
2021-09-23 checklist stuff pre-review
    -library work
    -voltage input max in sch
    [SparkFun_Artemis_Global_Tracker.brd, SparkFun_Artemis_Global_Tracker.sch]
2021-09-23 added measures
    [SparkFun_Artemis_Global_Tracker.brd]
2021-09-24 More Gnd vias near AD31 and upper left corner to stitch GND a bit better
    -added more gnd vias near AD31 header to stich ground better
    -nudged traces in upper left away from standoff to make more room for gnd plane, added a couple more vias to connect to bottom pour
    [SparkFun_Artemis_Global_Tracker.brd]
2021-09-24 Corrected PROD_ID on ADM4210-1 inrush current detector IC
    [SparkFun_Artemis_Global_Tracker.brd, SparkFun_Artemis_Global_Tracker.sch]
2021-09-24 design review changes
    -measures cleaned up to avoid overlap
    -LED labels to text only (and corrected 9603N typo)
    -3.3V voltage regulator text in schematic (section label)
    -corrected SPI SCK label on bottom
    -D35 buzzard label turned to AD35 and round end
    -D4 to round end label
    [SparkFun_Artemis_Global_Tracker.brd, SparkFun_Artemis_Global_Tracker.sch]
2021-09-24 eng checklist run
    nudged some vias to avoid hitting silk labels
    -fixed some PROD_IDs
    -a little SCH cleaning
    [SparkFun_Artemis_Global_Tracker.brd, SparkFun_Artemis_Global_Tracker.sch]
2021-09-24 Production panel and gerbers v10b
    [SparkFun_Artemis_Global_Tracker-Panel_v10b.brd]
2021-10-25 R9 Current Sense Resistor Value changed to 15mOhm
    Switched in-rush current sense resistor from 12mOhms to 15mOhms. This value is easier to source. It changes the in-rush current sense from 4.2A to 3.3A.
    Also added datasheet for in-rush current protection IC: ADM4210
    [SparkFun_Artemis_Global_Tracker.brd, SparkFun_Artemis_Global_Tracker.sch]
2021-10-25 Updated current sense resistors on production panel to 0.015Ohms (RES-16305)
    updated values and prod_ids on all four boards in the panel
    [SparkFun_Artemis_Global_Tracker-Panel_v10b.brd]
2021-11-10 Bringing over Arduino Examples and more from SPX repo
2021-11-12 GNSS backup battery charging control - added into examples
    Note, by default, most examples (that utilize the GNSS) have GNSS backup battery charging disabled during setup, and then enabled during the "run" portion of the example.
2021-11-15 Ex17 production test SDA/SCL swap
    [Example17_ProductionTest.ino]
2021-11-18 AND Gate (U12) PROD_ID update to correct package
    [SparkFun_Artemis_Global_Tracker.brd, SparkFun_Artemis_Global_Tracker.sch]
2021-11-22 AND Gate (U12) PROD_ID update to correct package on PANEL FILE
    Note, updated both PROD ID and part value on each part of the panel.
    [SparkFun_Artemis_Global_Tracker-Panel_v10b.brd]
2021-11-22 R31 20K 0402 Resistor change
    R31 has been changed from RES-15131 to RES14972, due to supply chain issues.
    [SparkFun_Artemis_Global_Tracker-Panel_v10b.brd, SparkFun_Artemis_Global_Tracker.brd, SparkFun_Artemis_Global_Tracker.sch]
2022-04-07 u-blox typo correction
    [SparkFun_Artemis_Global_Tracker.brd, SparkFun_Artemis_Global_Tracker.sch]

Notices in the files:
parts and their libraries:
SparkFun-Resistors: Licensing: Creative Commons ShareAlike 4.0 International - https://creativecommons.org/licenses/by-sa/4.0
